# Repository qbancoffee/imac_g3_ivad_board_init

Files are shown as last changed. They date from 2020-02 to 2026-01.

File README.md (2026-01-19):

# Add custom boards to an iMac G3 DV(slot loader) in order to use it as a monitor without having to destroy it.

See the wiki for an explantion of how this was done.<BR>

<H2>Wiki explaining how this was done.</H2>
 
- [Wiki explaining how this was done.](https://github.com/qbancoffee/imac_g3_ivad_board_init/wiki)

If you have a dead logic board but a functioning CRT then these boards can let you use your
iMac G3 DV as a VGA monitor so that you can use a modern desktop with it. You can even hand wire the 
whole thing without the need for the boards if you so wish.

Even if you have a perfectly functional iMac G3 DV you can remove your logic board and use these boards
to convert your iMac G3 DV into a VGA monitor without harming your iMac G3 and when you want your iMac back, you can remove the custom boards and plug your original logic board back in and still use your iMac G3 as an original apple product.
These boards are designed to plug right in without having to modify the case and attached things.

However....

# --->DO THIS AT YOUR OWN RISK<--- as things may break as you dissasemble your iMac and you can get shocked.

Although low risk, things can always go wrong, so be careful.

- The inner bezel is extremely fragile and routintely breaks.
- The CRT can hold a charge and shock you even if the iMac is not plugged in.
- Static discharge from your hands can destroy electronics so "GROUND THYSELF"

 I've documented much of the iMac G3 slot loader chasis connector pinouts on this repo and used 
 it as a guide to make breakout circuit boards than can plug right into the chassis connectors and provide
 standard connections so that a regular computer can use things like the CRT,speakers, power button, audio
 jacks, the down-converter board ect..
 
 It wasn't easy but luckily a lot of people have shared their findings online..
 
 There is working code here for both the arduino and raspberry pi to initialize the IVAD board so that you can use it as a monitor.
 
The current initialization sketch waits for button presses on an arduino pin to send the initialization sequence
to the IVAD board but you can just uncomment "initIvadBoard();" in "setup()" to send it as soon as it's powered.

</br>

Also, you might have to modify values in the init sequence to get the brightness, contrast and screen geometry
just right for your setup. below is an example from the init sketch.

```
  writeToIvad( 0x46, 0x04, 0x80);//red x-30
  writeToIvad( 0x46, 0x05, 0xB0);// green x
  writeToIvad( 0x46, 0x06, 0x78); //blue x-38

  writeToIvad( 0x46, 0x07, 0xB1); //horizontal position
  writeToIvad( 0x46, 0x08, 0xF8); //vertical size
  ```

<!-- toc -->
- [Success stories](#Success-Stories)
- [Goals](#Goals)
- [Chassis Connectors and Pinouts](#Chassis-Connectors-and-Pinouts)
    * [Removing the logic board](#Removing-the-logic-board)
- [Wiring VGA cable](#Wiring-VGA-cable)
    * [Making the cable](#Making-the-cable)
- [Preparing the Raspberry Pi](#Preparing-the-Raspberry-Pi)
    * [What to install](#What-to-install)
    * [Configure Resolution and Refresh Rate](#Configure-Resolution-and-Refresh-Rate)
-   * [Wiring The Raspberry Pi and testing the connection](#Wiring-The-Raspberry-Pi-and-testing-the-connection)
- [Wiring Arduino Uno](#Wiring-Arduino-Uno)
- [Wiring Arduino Nano](#Wiring-Arduino-Nano)
    * [Loading and Running the initialization sketch](#Loading-and-Running-the-initialization-sketch)
- [Wiring Arduino Uno to transmit EDID](#Wiring-Arduino-Uno-to-transmit-EDID)
- [Wiring Arduino Nano to transmit EDID](#Wiring-Arduino-Nano-to-transmit-EDID)
- [Powering the down converter board PAV](#Powering-the-down-converter-board-PAV)
- [Powering the CRT on and off](#Powering-the-CRT-on-and-off)
- [See Also](#See-Also)
   * [See the boards](#Boards)
   * [Getting adapter boards](#Ordering-Boards)
   * [Acknowledgements](#Acknowledgements)
   * [Videos](#Videos)
## Success Stories
- [Apple IIe using the iMac G3 as a monitor](https://www.reddit.com/r/VintageApple/comments/fox7b8/my_half_retro_battle_station/)
- [Apple IIe using the iMac G3 as a monitor 2 ](https://old.reddit.com/r/VintageApple/comments/fmoi5d/slot_loading_imac_g3_vga_input_hack/)
- [oshimai running windows on a pc104 computer](https://vimeo.com/415301897)
- [oshimais' repo with links to videos](https://github.com/shuuryou/imacg3)
- [A Nintendo Switch connected to an iMac G3](https://www.reddit.com/r/crtgaming/comments/k3hf02/imac_g3_crt_connected_to_switch/)
- [Check out the iMacSTer repo by wikerwaka it's impressive!](https://github.com/wickerwaka/iMacSTer)
- [Wikerwaka testing the iMacSTer](https://youtu.be/8O5fEVcCo0Q)
- [Wikerwaka assembling the iMacSTer](https://youtu.be/OmDPnWWWzPM)
- [Matt Gray upgrades an iMac G3 it and now runs on Apple silicon!](https://youtu.be/WoYBuP4Bxiw?si=AiPPqQjk6-E3-r2k)

## Goals

The main goal is to convert the iMac G3 into a VGA monitor whithout sacrificing the original CRT and
using as much of the iMac as possible. The difficult part is tricking the IVAD board into thinking it is 
still connected to a G3 logic board. the idea is to capture the init sequence and reimplement it using
a microcontoller like an arduino.

Once achieved, one can connect a standard computer to it as if it were a regular monitor with speakers.
One can even include a motherboard on the inside of the G3 basically converting it into a modern computer.

Here are the goals

- [x] Capture IVAD board initialization sequence from the Imac logic board to the IVAD board and implement with mcu & rpi.
- [x] Document how to control brightness, contrast, screen goemetry ect via the i2c lines.
- [x] Document as much of the pinouts as possible on the the chassis connectors .
- [x] [Design circuit boards that will plug into the connectors and allow one to use the on/off button,
speakers, power LED, mic ect..](#Boards)
- [x] Design the circuit boards with through hole components so that anyone can build these with just a soldering iron and
solder.
- [x] Use the original down-converter board(kind of like a power supply) to power things like
an amplifier and a slot loading DVD drive.

## Chassis Connectors and Pinouts
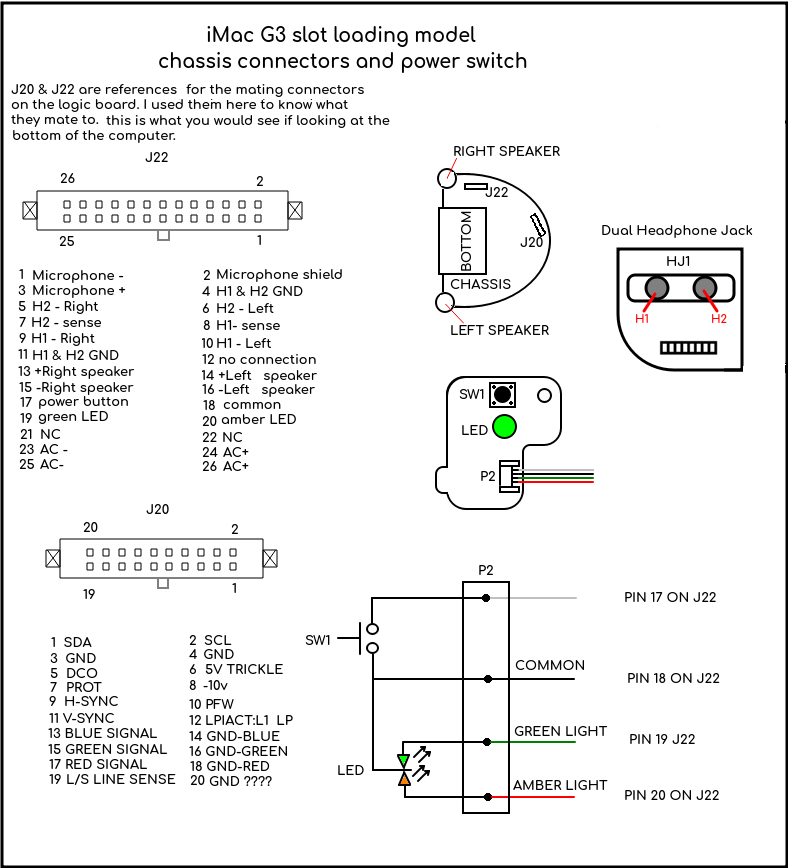
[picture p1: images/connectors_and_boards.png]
ChassisConnectors Chassis connectors


### Removing the logic board
The connector drawings in the above [diagram](#Chassis-Connectors-and-Pinouts) represent the cables
coming from the CRT analog board that plug into the logic board. To expose these, the logic board must
be removed.

## Wiring VGA cable
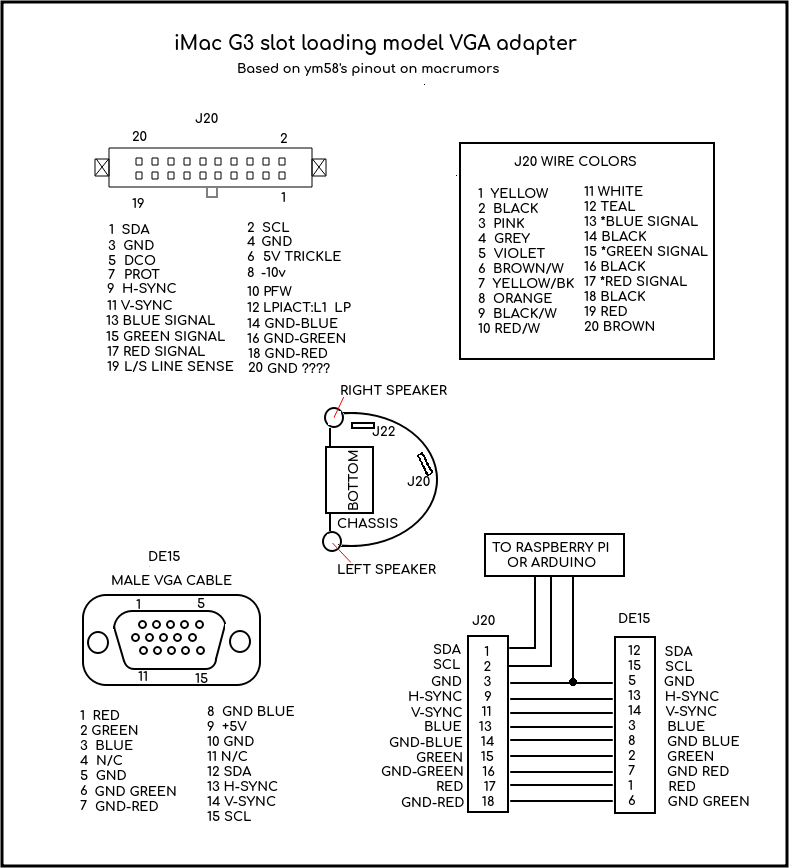
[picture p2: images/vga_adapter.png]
VGACable VGA Cable


### Making the cable
This is perhaps the most time consuming part of the whole process because not all VGA cables are made the same so the colors for the cable I used may not be the colors used in your cable. Here are the steps I took.<br>

- Find a VGA cable to cut.
- Cut the cable so that you have at least one of the ferrite chokes left on the cable.
- Cut away the cable jacket such that the wires are at a comfortable handling length. 3 to 4 inches
- Strip each wire and ring them out to find what color corresponds to each pin on the DE15 connector.
- Use the [diagram](#Wiring-VGA-cable) above and map your cable to J20 using the DE15 pin numbers as the key.
- Option 1 ,use a 20 pin header and solder the DE15 wires to it then plug it into J20.
- Option 2, cut the required wires from J20 and splice them with VGA cable. Solder and use shrink tubing if you can but twisting them and electrical tape works as well. Make sure to leave enough wire on J20 in the event you need to reattach the wires.

## Preparing the Raspberry Pi
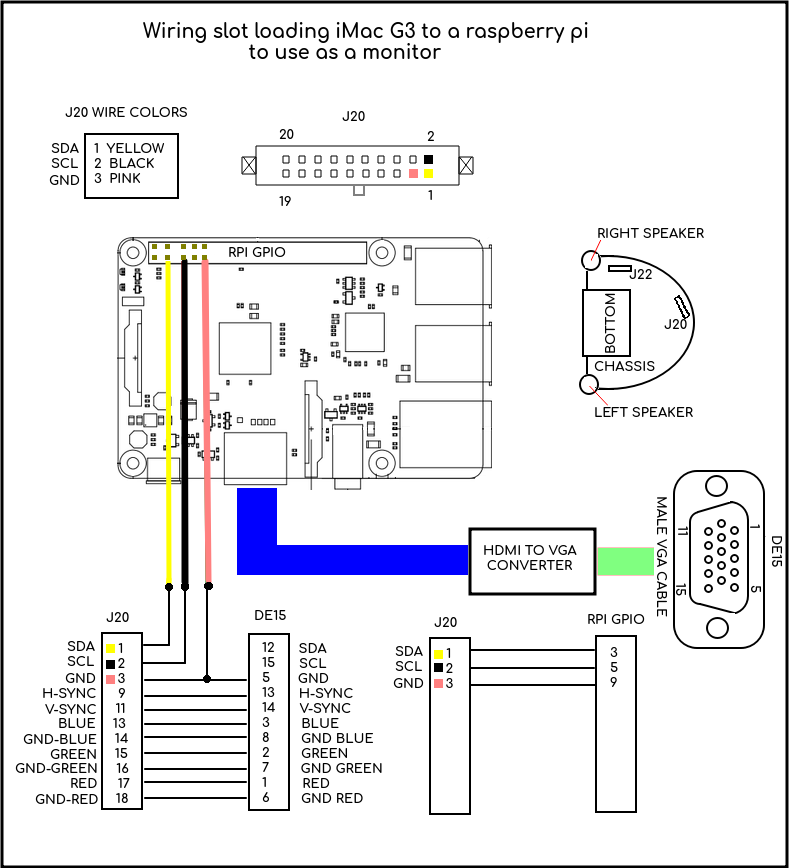
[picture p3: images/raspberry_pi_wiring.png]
WiringRPI Wiring RPI


### What to install
- Install the latest raspian image using a regular monitor.
- Connect to your network and get the ip address for the pi by opening a terminal and issuing the following.
```bash
ifconfig
```
If you connected using wifi then the ip address is under wlan0: , inet.<br>
If you connected using a cable the the ip adress is under eth0: inet<br>
- Enable ssh , you'll need this to login from another computer when you don't have a display.
- Enable I2C.
- Install i2c-tools & git.
- ssh to the pi from a terminal if your on a Mac or linux. If you're on Windows use putty to ssh to the pi I'm assuming
the username is "pi" but replace this with the the username you've created for the pi.

```bash
sudo apt-get update && sudo apt-get -y install i2c-tools git
```
- Install smbus and RPI.GPIO for python using pip for the python version you have.
```bash
sudo pip install smbus RPI.GPIO
```
- Clone the iMac IVAD init repo
```bash
git clone https://github.com/qbancoffee/imac_g3_ivad_board_init.git
cd imac_g3_ivad_board_init
```
- Copy init_ivad.py to /usr/local/bin & and make it executeable
```bash
sudo cp init_ivad.py /usr/local/bin
sudo chmod +x /usr/local/bin/init_ivad.py
```
- Edit rc.local and add the script. Make sure it's added to the line before "exit 0 " or it will not run.
It also needs to be made executable since by default it doesn't do anything.
```bash
sudo nano /etc/rc.local
```

- It should look something like this
```
#!/bin/sh -e
#
# rc.local
#
# This script is executed at the end of each multiuser runlevel.
# Make sure that the script will "exit 0" on success or any other
# value on error.
#
# In order to enable or disable this script just change the execution
# bits.
#
# By default this script does nothing.

# Print the IP address
_IP=$(hostname -I) || true
if [ "$_IP" ]; then
  printf "My IP address is %s\n" "$_IP"
fi

/usr/local/bin/init_ivad.py

exit 0

```

- Ctrl-x to save and exit

- Make rc.local executable
```bash
sudo chmod +x /etc/rc.local
```

### Configure Resolution and Refresh Rate
- Edit config.txt
```bash
sudo nano /boot/config.txt
```
- The newer Raspberry Pi OS uses the VC4 V3D driver that causes the video to go blank. Comment the line that enables it and add the Fake VC4 V3D driver.
```
# Enable DRM VC4 V3D driver
#dtoverlay=vc4-kms-v3d
dtoverlay=vc4-fkms-v3d

```
Newer versions of the Raspberry Pi OS will ignore video modes specified in /boot/config.txt if the EDID sent from the monitor is corrupt or missing. Since we are not sending EDID information to the raspberry pi from the iMac we need to tell the OS to ignore the EDID and set the correct video mode.
- Add the following to the bottom of the file and save.
```
#iMac G3 settings
hdmi_ignore_edid=0xa5000080
hdmi_group=2
hdmi_mode=18
```
Here is a video where I perform the above steps.
- [Modding an iMac G3 DV using only a Raspberry Pi](https://youtu.be/xSiqchucFE4)
### Wiring The Raspberry Pi and testing the connection

In all cases, the IVAD board needs to be initialized when the power analog board is
turned on for the first time. To do this, the initialization sequence must be sent using the
I2C lines(SDA & SCL) on the Raspberry Pi's GPIO header. Connect the I2C lines according to the diagram
above and connect the VGA cable to the HDMI port using a HDMI to VGA converter.

- Use i2cdetect to probe the IVAD board. Make sure the iMac is plugged in, it does not have to be turned on for this.

```bash
i2cdetect -y 1
```
- Confirm it found address's 46 and 53, if no luck, check the wiring and make sure I2C is enabled. The output should look something like the following.
```    
     0  1  2  3  4  5  6  7  8  9  a  b  c  d  e  f
00:          -- -- -- -- -- -- -- -- -- -- -- -- -- 
10: -- -- -- -- -- -- -- -- -- -- -- -- -- -- -- -- 
20: -- -- -- -- -- -- -- -- -- -- -- -- -- -- -- -- 
30: -- -- -- -- -- -- -- -- -- -- -- -- -- -- -- -- 
40: -- -- -- -- -- -- 46 -- -- -- -- -- -- -- -- -- 
50: -- -- -- 53 -- -- -- -- -- -- -- -- -- -- -- -- 
60: -- -- -- -- -- -- -- -- -- -- -- -- -- -- -- -- 
70: -- -- -- -- -- -- -- --
```
- [Turn on the monitor](#Powering-the-CRT-on-and-off) and run the initialization script.The iMac should make
a nice old school "CRT IS ON"  sound. 
```bash
/usr/local/bin/init_ivad.py
```
If there are errors, make sure the iMac is plugged in and check the wiring.<br>
If there are no errors and there is nothing on the screen, move the mouse or press a key.
The raspberry pi might have turned off the display due to inactivity.

- With the IVAD initialized, Reboot the Raspberry Pi.

## Wiring Arduino Uno
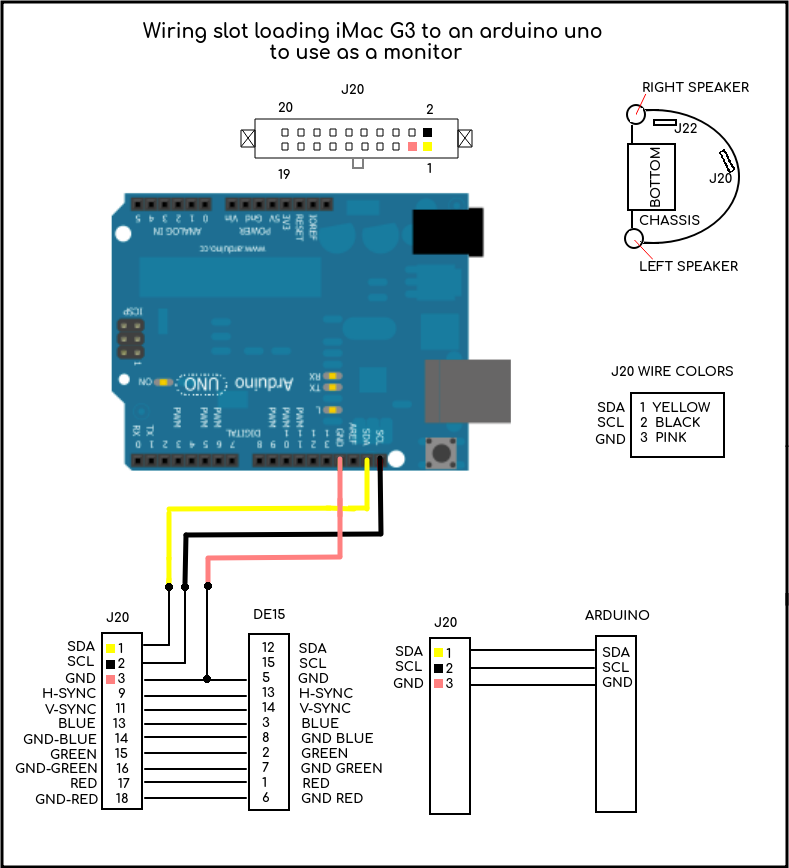
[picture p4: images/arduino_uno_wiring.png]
WiringArduinoUno Wiring Arduino Uno


## Wiring Arduino Nano
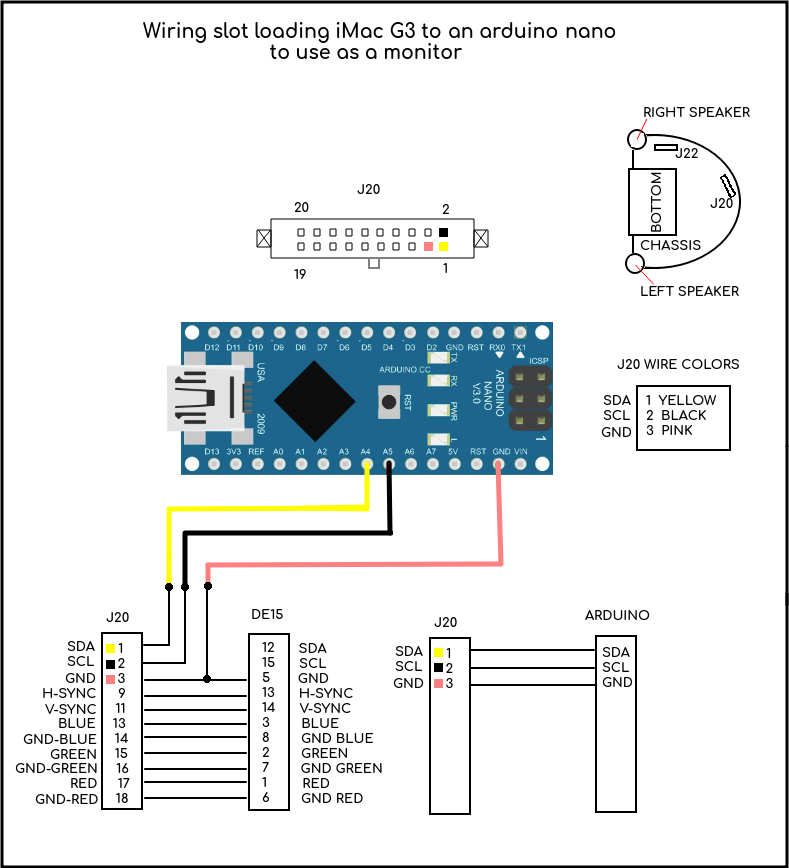
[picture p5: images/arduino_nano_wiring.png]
WiringArduinoNano Wiring Arduino Nano


### Loading and Running the initialization sketch
write here

## Wiring Arduino Uno to transmit EDID
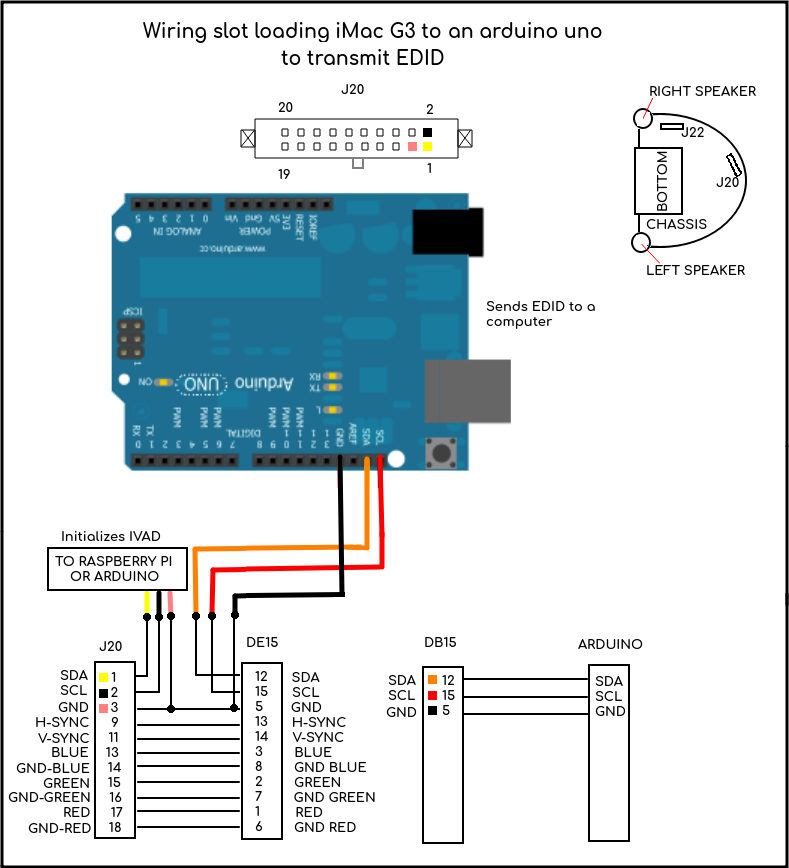
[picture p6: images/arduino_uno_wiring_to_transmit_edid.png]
WiringArduinoUnoToXmitEdid Wiring Arduino Uno to transmit EDID


## Wiring Arduino Nano to transmit EDID
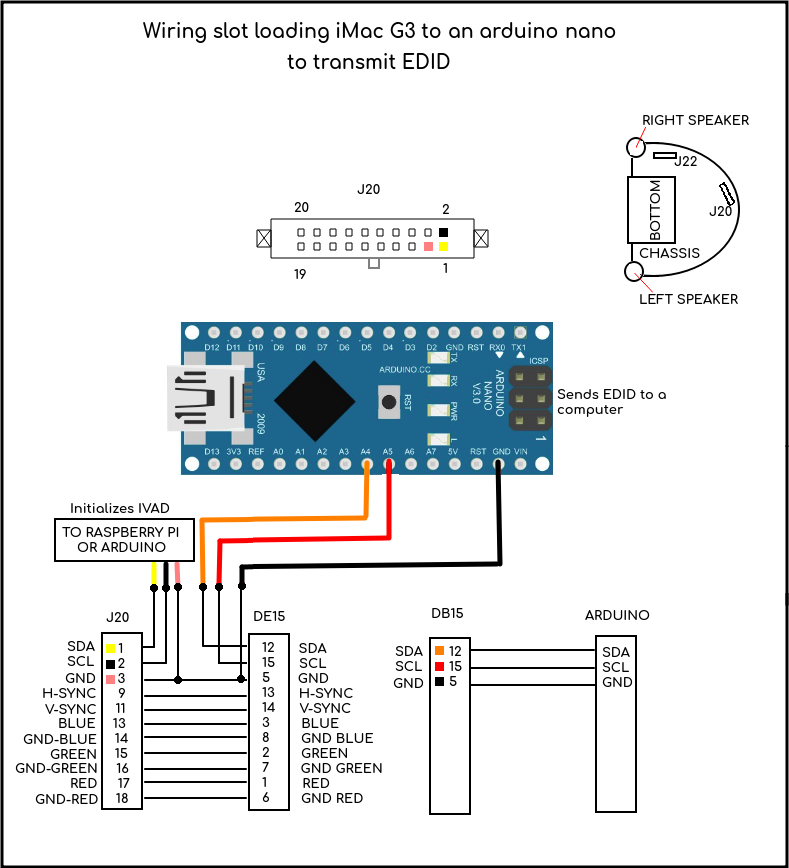
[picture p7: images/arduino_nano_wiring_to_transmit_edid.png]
WiringArduinoNanotoXmitEdid Wiring Arduino Nano to transmit EDID


## Powering the down converter board PAV
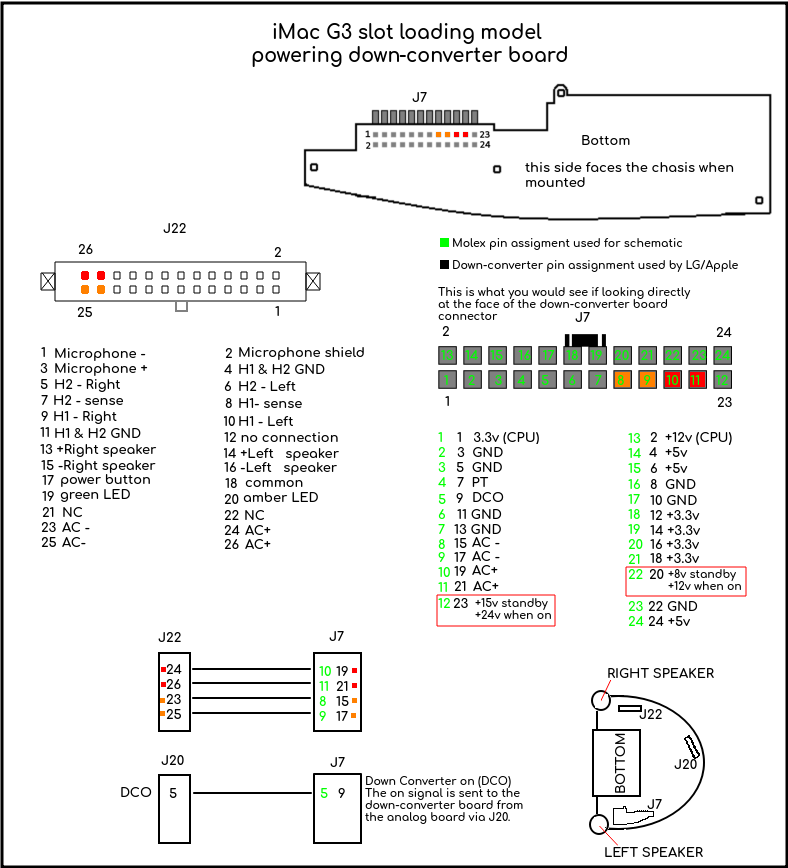
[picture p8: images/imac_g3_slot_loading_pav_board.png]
WiringPAV Powering the PAV board


The CRT analog board provides 24v AC to the PAV or down converter board through the logic board via the J22 
connector. you can directly connect the PAV board and the analog board through the J22 connector and
the PAV board will produce the typical mother board volytages. +12v, +5v +3.3v ect...

## Powering the CRT on and off
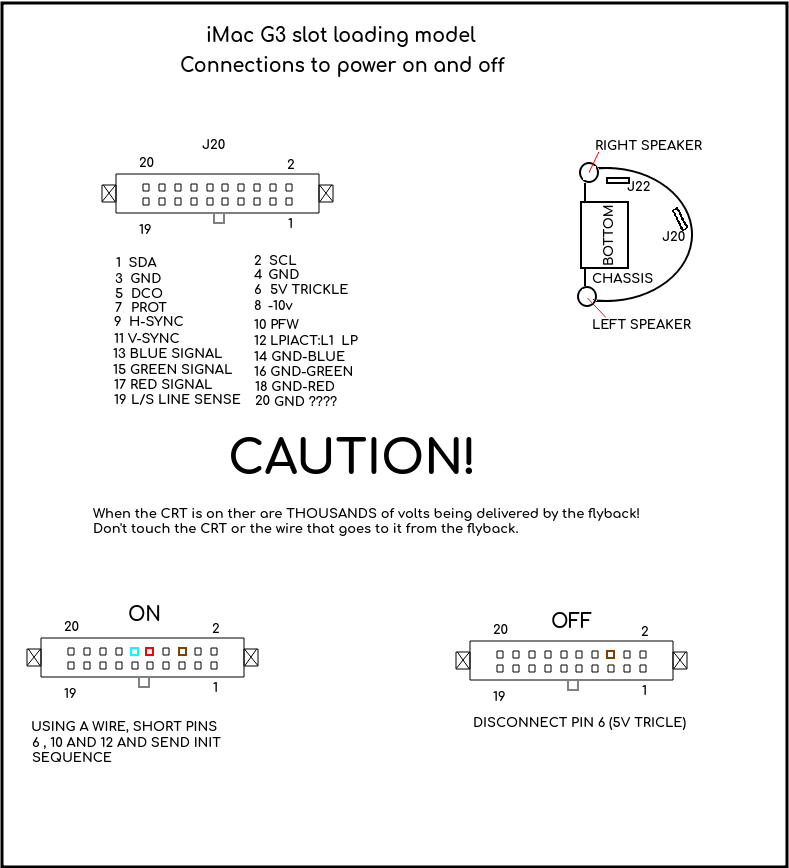
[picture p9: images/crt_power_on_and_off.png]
CRTOnAndOff CRT On and Off


## See Also
### Boards
# J20 Board
What it does.
- detects button presses
- sends the init sequence to the IVAD boar
- sends the "turn-on" signal to the down-converter board
- has a control line "PROT" that when 5 volts are applied turns everythin off. A shut-off signal can be sent here.
- powers the green LED
- sends EDID information via VGA cable so that a connected computer knows how to configure the monitor for use.
</br>

This board works but as of March 23 2020 it needs a slight modification to make it more robust.
# Rendition
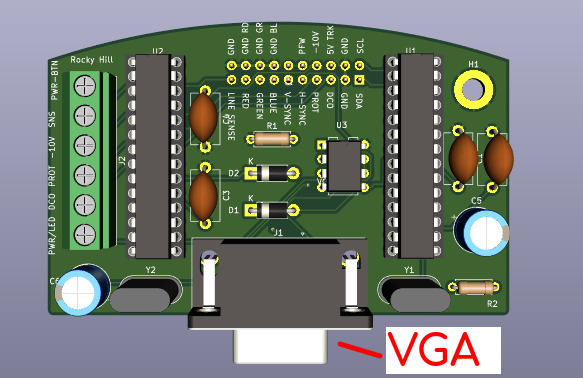
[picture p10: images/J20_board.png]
J20 J20 VGA adapter board

# Board installed
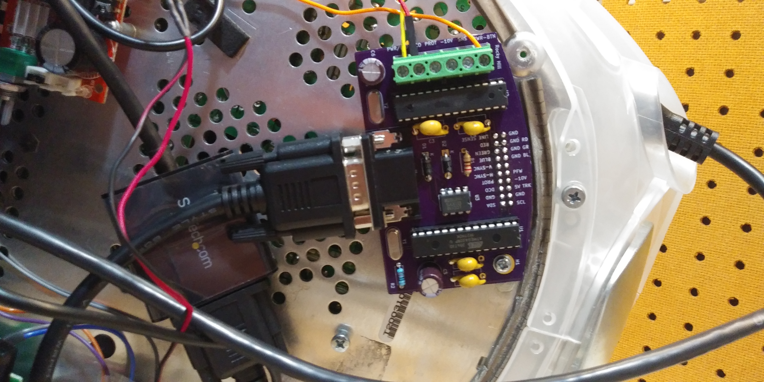
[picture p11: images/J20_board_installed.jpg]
J20Installed J20 VGA adapter board installed

</br>

# Rendiiton of Rev 2 of the J20 board.
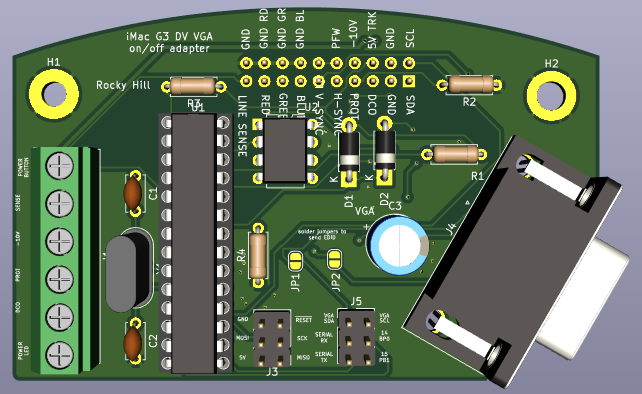
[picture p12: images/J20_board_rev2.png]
J20REV2 J20 VGA adapter board Rev 2

</br>

# J22 Board
What it does.
- provides access to the microphone and the speakers
- provides access to the power button
- provides access to the green LED
- provides access to the amber LED
- provides access to the headphone jacks 
- routes 24 VAC from the analog(CRT) board to the the down converter break out board.
</br>

This board has been tested and mostly worked. I found that the mic was miswired
but I've since fixed that.
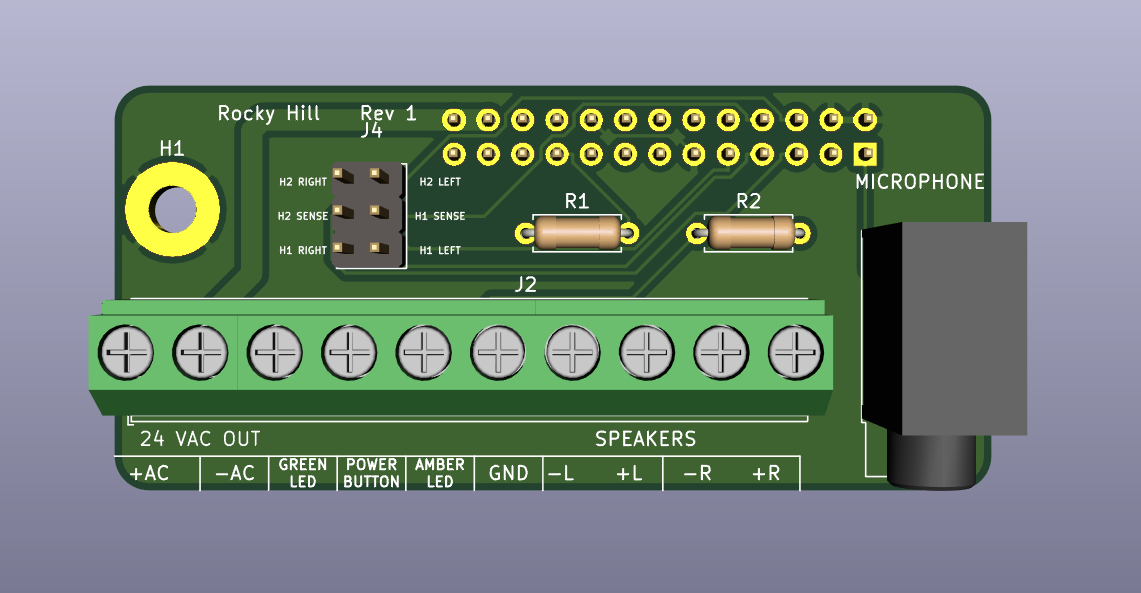
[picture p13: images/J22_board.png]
J22 J22 speaker/mic/led/power button breakout board

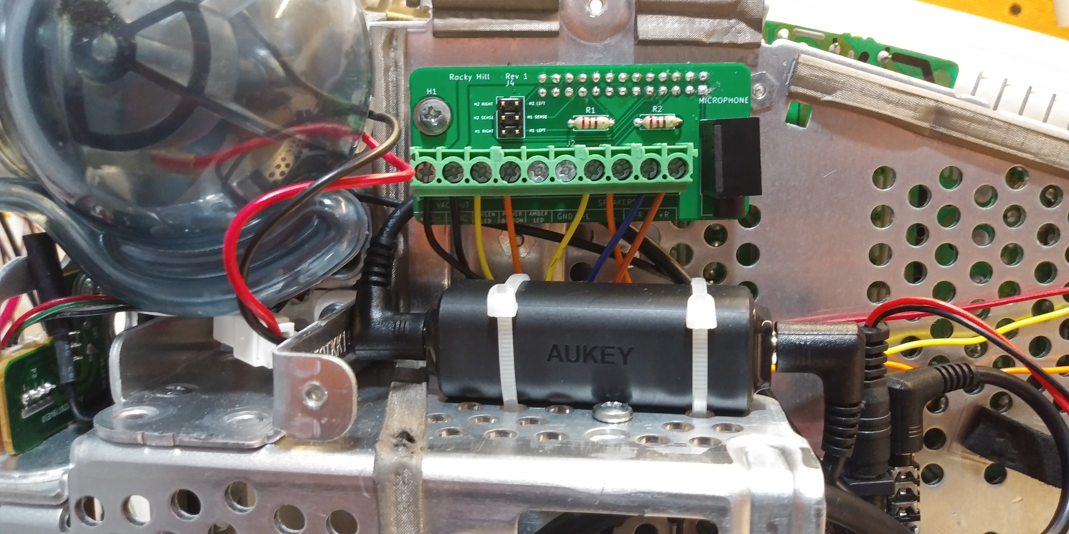
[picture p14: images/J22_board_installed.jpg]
J22Installed J22 speaker/mic/led/power button breakout board installed

</br>
# Down-converter breakout board
What it does
- provides a 24 VAC input from the J22 board into the down-converter board
- provides a "turn-on" input for the J20 board, this is DCO, which stands for Down Converter On
- provides 3.3 VDC out from the down-converter board that turns on and off with the CRT.
- provides   5 VDC out from the down-converter board that turns on and off with the CRT.
- provides  12 VDC out from the down-converter board that turns on and off with the CRT.
- provides a constant  8 VDC standby voltage when all is off and 12 VDC when all is on.
- provided a constant 15 VDC standby voltage when all is off and 24 VDC when all is on.
</br>
The down-conveter uses the 24 VAC coming from J22 in order to power the original logic board and drives. Some people have called this the iMac G3 power supply. This is what it looks like.

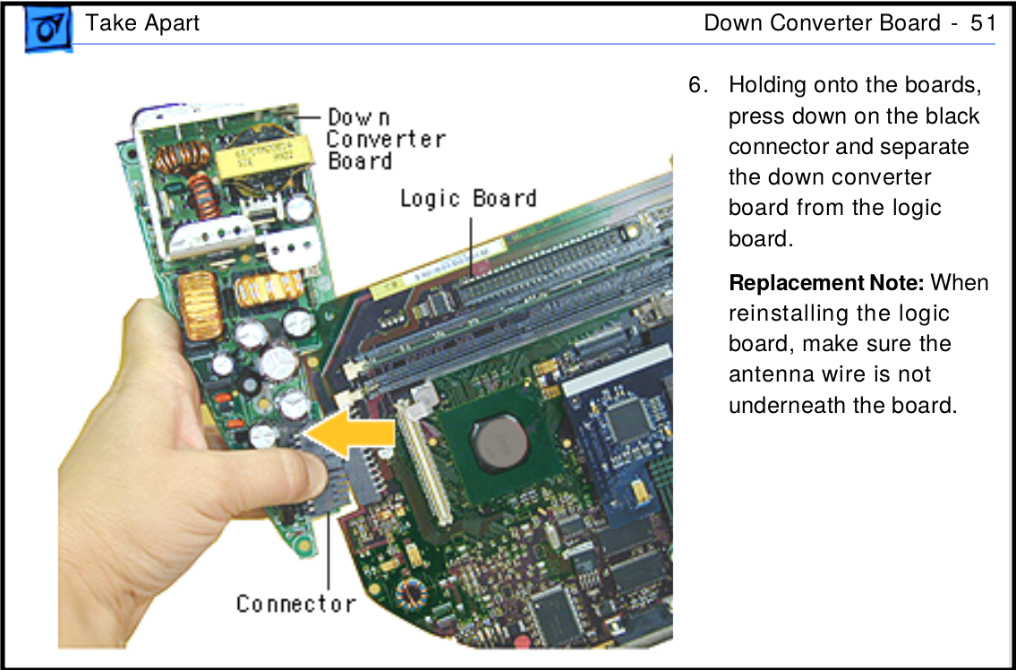
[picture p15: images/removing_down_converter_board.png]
DCB Removing down-converter board

</br>
# Rendition
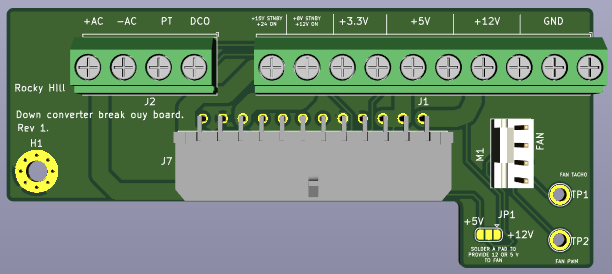
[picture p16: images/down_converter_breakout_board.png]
DCB1 Breakout board for the down-converter board so one can power things.

</br>
# Actual Board
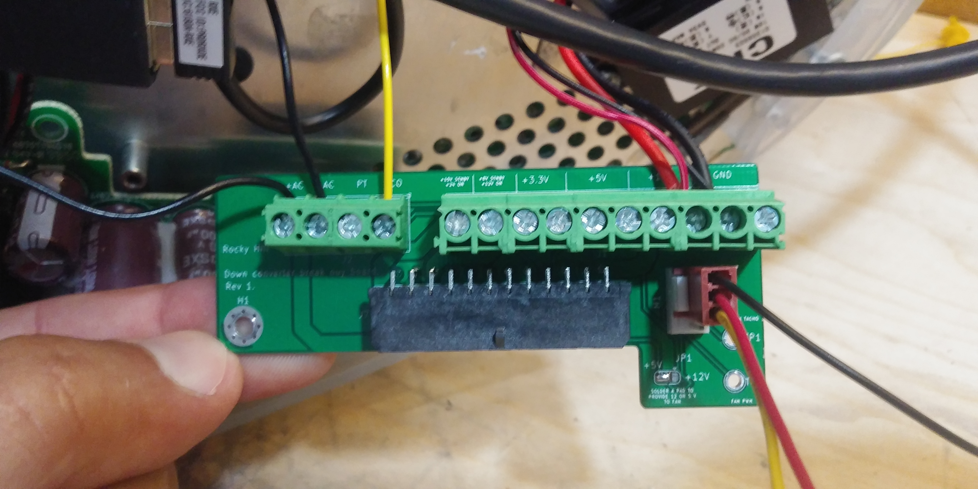
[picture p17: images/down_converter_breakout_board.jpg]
DCB2 Breakout board for the down-converter board so one can power things.

</br>
# Board installed
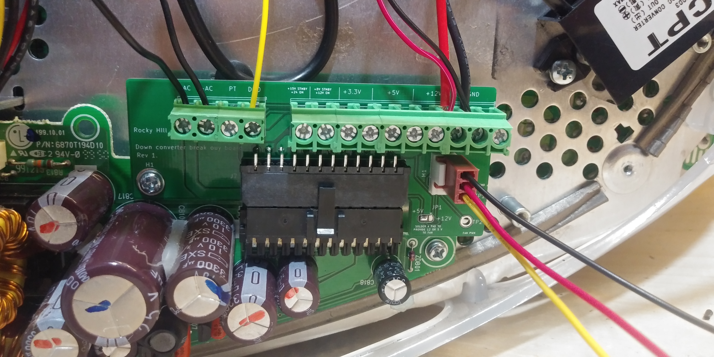
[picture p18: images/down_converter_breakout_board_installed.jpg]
DCB3 Breakout board for the down-converter board so one can power things.


</br>

### Ordering Boards
All PCB manufacturers should accept gerber files to manufacture boards so I've decided
to design these in KiCAD which is suite of open source EDA programs to create schematics and
design PCBs. There are no limitations to the size of the board and you don't have to order from
a specific vendor.

Recently I've been using https://jlcpcb.com/ and the turn arounds are fast for the price.
In the "schematics_and_pcbs" folder are the three kicad projects for each board, each in its own folder.
I've included the gerber files and zipped them up for convenience, they are in the gerber directory
for each project. To order you can just upload the zip file to https://jlcpcb.com/ or whatever company you choose
and you should get them in the mail. There is a bill of materials included in each project folder. It's a csv file
that includes the reference number, the part number and vendor so you can order the componets to build the boards.
I like to buy from digikey but obviously you can find a vendor that fits your needs.

### Acknowledgements

- [patriciooholegu for inspiring me to do this with an eMac](https://forums.macrumors.com/threads/i-have-decided-to-hack-emacs-crt-to-work-with-any-standard-motherboard.1754089/post-19353472)
- [ym58 for providing the video connector wiring.](https://www.tonymacx86.com/threads/imac-g3-slot-mod-video-connector.125515/)
- [Eric Bylenga for providing the pinout for the PAV board.](http://bylenga.ddns.net/index.php?page=vcr.php)
- [sparpet for capturing and sharing the IVAD initialization code](https://forums.macrumors.com/threads/imac-g3-mod-video-connector.1712095/post-25819428)
- [jamie-g for providing a way to adjust monitor settings via i2c](https://forums.macrumors.com/threads/imac-g3-mod-video-connector.1712095/post-25679538)
- [iMac speaker replacement by TEch Chrunch](https://youtu.be/yc8NGDw5aSQ)
- [DrJekyll_XYZ for providing xrandr output that lead to creating an EDID](https://forums.macrumors.com/threads/imac-g3-mod-video-connector.1712095/post-28272422)
- [DrJekyll_XYZ for suggesting the PAM8403 chip for audio](https://forums.macrumors.com/threads/imac-g3-mod-video-connector.1712095/post-28249216)
- [anotherelise for providing another init sequence](https://forums.macrumors.com/threads/imac-g3-mod-video-connector.1712095/post-28346679)
- [anotherelise for providing IVAD CRT property adjustment capture](https://forums.macrumors.com/threads/imac-g3-mod-video-connector.1712095/post-28349738)
- [oshimai for extracting several EDID's and fiding one that works flawlessly](https://forums.macrumors.com/threads/imac-g3-mod-video-connector.1712095/post-28359571)
- [oshimai for coming up with the idea of monitoring VSYNC to use as a signal to shut off the CRT](https://forums.macrumors.com/threads/imac-g3-mod-video-connector.1712095/post-28345426)

### Videos
- [Booting an non-modded iMac G3 to confirm the CRT turns on](https://youtu.be/meIzAyQd0t0)
- [Initializing IVAD board with an Arduino Uno](https://youtu.be/JLaHMjQ7idI)
- [Using iMac G3 as a second monitor with custom modeline](https://youtu.be/iSCjOOsf-QQ)
- [Tweaking the modeline to make the iMac G3 fullscreen](https://youtu.be/1DeY3o7P60g)
- [Sending the EDID via the VGA cable to a connected computer](https://youtu.be/KzHUogEQob4)
- [Using CRT without the logic board](https://youtu.be/MbTqhlqsKoY)
- [Running DOSBOX](https://youtu.be/PG7bluXxrPA)
- [Initializing the CRT using only a Raspberry Pi](https://youtu.be/isjo-4vQxwM)
- [Powering the iMac G3 on and off using an arduino and two transistors](https://youtu.be/-TeNbAcnvbk)
- [Powering the Down Convetrer Board without the logic board](https://youtu.be/xmISR5iBjTU)
- [Using CRT on second iMac without logic board](https://youtu.be/UcsI3FVfpCM)
- [Powering an arduino nano with only the triclke voltage provided by the analog board](https://youtu.be/KuT7AKvZXhk)
- [iMac G3 speaker repair](https://youtu.be/jgs-gkoiUrA)
- [Testing replacement speakers with smooth criminal](https://youtu.be/Vm1vN6xlomQ)
- [Testing an SBC inside the iMac G3 ](https://youtu.be/ZOYHHg9NhZA)
- [Powering a computer using the iMac's down converter board](https://youtu.be/1DuaIlEZ5WU)
- [Using a PAM8403 board to drive the speakers on the iMac G3](https://youtu.be/jEA85s0Cqyg)
- [Testing Retropie with iMac G3 monitor](https://youtu.be/S1fnj0tsFQA)
- [Testing J20 board for the first time](https://youtu.be/_IMhMkrIE4M)
- [Testing the J22 board with a raspberry pi](https://youtu.be/HR-qM3-7SYA)
- [Testing audio via the J22 breakout board 1](https://youtu.be/MyON9M_RYCk)
- [Testing audio via the J22 breakout board 2](https://youtu.be/EDeFRHsqa5c)
- [Testing the down converter breakout board for the first time.](https://youtu.be/BQKrsIXOSxU)
- [Mirroring an iMac G3 DV with this iMac G3 monitor hack](https://youtu.be/4jHPZWJs-aY)
- [All three boards installed and working.](https://youtu.be/dqxeiFkvuYg)
- [Rapberry Pi + Arduino powered iMac G3 hybrid running RetroPie](https://youtu.be/CLCZFmmEnno)
- [Adjusting iMac G3 picture settings via a serial terminal](https://youtu.be/9LLsHE3xdBA)
- [Adjusting iMac G3 picture settings with a java based GUI](https://youtu.be/zrzcvThxDeY)
- [Monitoring VSYNC to shut CRT off](https://youtu.be/fBMyjlEAZAw)
- [Cloning compiling and running oshimai's gui](https://youtu.be/DqM9bZfvwgM)
- [Stable arduino sketch that can communicate with oshimais GUI](https://youtu.be/inmUAiIA7sg)
- [Oshimais GUI running on a raspberry pi3 under mono](https://youtu.be/g9aLTrW5eaU)
- [Making a desktop recording the iMac G3 monitor with a raspberry pi, running oshimais gui](https://youtu.be/JA01o5xfwxg)
- [Assembling the J20 adapter board](https://youtu.be/qILuajxscnE)
- [Assembling the J22 adapter board](https://youtu.be/JCPRYKbwKyk)
- [Using a Gert VGA 666 adapter + Raspberry pi 3 with an Imac G3 monitor](https://youtu.be/5H0nzaTycOg)
- [Playing a round of among us using the iMac G3 as a monitor](https://youtu.be/MomKAUGT8i8)
- [Playing minecraft using the iMac G3 as a monitor](https://youtu.be/VxJVShNo72g)
- [Converting an iMac G3 DV into a monitor start to finish](https://youtu.be/guVSI1aqcJg)
- [Playing Duck Hunt and Super Mario Bros with my NES on the iMac G3](https://youtu.be/wCEGIwrCOMQ)
- [Playing "The Legend of Zelda" with my NES on the iMac G3](https://youtu.be/OpjjOnSjGQU)
- [Using my CoCo 2 on the iMac G3](https://youtu.be/9cu0CFqIWnc)
- [Modding an iMac G3 DV using only a Raspberry Pi](https://youtu.be/xSiqchucFE4)

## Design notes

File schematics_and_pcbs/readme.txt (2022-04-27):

These are the KiCAD project files for this project.

===Main boards===

-imac_g3_333mhz_slot_loading_J20_adapter_board
	This board is the "brains" of the operation, it sends the init sequence
	to the IVAD board and also sends EDID information to any device that
	requests it when conencted to the VGA port.
 
-imac_g3_down_converter_board_adapter
	This board takes 24VAC from the analog board via the the J22 board and
	converts it to standard computer power supply voltages. +12VDC, +5VDC
	and +3.3VDC. This board also has a footprint to include a connector
	to connect a CPU fan.
	
-imac_g3_slot_loading_J22_adapter_board
	This board is essentially a breakout board that allows one to use the 
	built in speakers, power switch, leds and 24VAC.

-surfacemount_version	
	This will be a surface mount version of the original main boards.
	It is currently under development. The idea is to have boards
	that can be assembled by an assembly outfit to bring down the cost.
	
===User contributed boards==

-RPiG3iMac	
	Additional KiCAD projects for a Raspberry Pi Hat and a breakout board
	for the J20 board. These boards were contributed by Rudy https://reng.ca
	, look inside the directory for more details.

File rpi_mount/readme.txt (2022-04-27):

These three parts comprise a mount for a raspberry pi 4 inside of the iMac G3.
These parts were created and graciously given to this project by 
Rudy https://reng.ca so that others can enjoy it.

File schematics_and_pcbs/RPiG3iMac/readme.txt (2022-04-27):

These boards were created and graciously contributed by Rudy https://reng.ca for
this project for others to use.

RPiG3iMac       Contains the KiCAD project files for a Raspberry Pi HAT
                with power and activity LEDs. The HAT also converts the
                incoming TTL RS232 signal to CMOS levels for use by the
                built in serial port.
            
RPiG3iMacJ20    Contains the KiCAD project files for a breakout board
                for the J3 and J5 headers on the J20 board. Once mounted
                one can connect regular wires via a terminal strip to
                interface with the two headers

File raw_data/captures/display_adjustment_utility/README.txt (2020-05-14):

This capture was made by running the Apple Display  adjustment utility
under System 9. The IVAD i2c were lines externally monitored with an
ubuntu 16.04 computer using a Saleae Logic analyzer.

Each Property was recorded by sliding the bar from min to max.
The captures have the IVAD address 0x46 and the register offset for
each property along with the value sent for that property.

Each propertry is in a csv file named according to the name in the
program.

For example when I manipulated the "width" property and captured it,
I called that file "width.csv"

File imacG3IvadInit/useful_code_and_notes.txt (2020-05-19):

  /**
       writeToIvad( 0x46,0x13,0x00);
      writeToIvad(0x46,0x13,0x00);
      readFromIvad(0x46,1);
      writeToIvad(0x46,0x09,0x00);
      writeToIvad(0x53,0x33);
      readFromIvad(0x53,1);
      writeToIvad(0x46,0x13,0x0b);
      writeToIvad(0x46,0x00,0x00);
      writeToIvad(0x46,0x08,0xe4);
      writeToIvad(0x46,0x12,0xc9);
      writeToIvad(0x53,0x00);
      readFromIvad(0x53,10);
      writeToIvad(0x53,0x0a);
      readFromIvad(0x53,10);
      writeToIvad(0x53,0x14);
      readFromIvad(0x53,10);
      writeToIvad(0x53,0x1e);
      readFromIvad(0x53,10);
      writeToIvad(0x53,0x28);
      readFromIvad(0x53,10);
      writeToIvad(0x53,0x32);
      readFromIvad(0x53,10);
      writeToIvad(0x53,0x3c);
      readFromIvad(0x53,10);
      writeToIvad(0x53,0x46);
      readFromIvad(0x53,10);
      writeToIvad(0x53,0x50);
      readFromIvad(0x53,10);
      writeToIvad(0x53,0x5a);
      readFromIvad(0x53,10);
      writeToIvad(0x46,0x01,0x82);
      writeToIvad(0x46,0x02,0x82);
      writeToIvad(0x46,0x03,0x82);
      writeToIvad(0x46,0x04,0xa0);
      writeToIvad(0x46,0x05,0xa0);
      writeToIvad(0x46,0x06,0xa0);
      writeToIvad(0x46,0x07,0xad);
      writeToIvad(0x46,0x08,0xe4);
      writeToIvad(0x46,0x09,0x3d);
      writeToIvad(0x46,0x0a,0x9e);
      writeToIvad(0x46,0x0b,0xb4);
      writeToIvad(0x46,0x0c,0xc4);
      writeToIvad(0x46,0x0d,0x27);
      writeToIvad(0x46,0x0e,0xbf);
      writeToIvad(0x46,0x0f,0xc0);
      writeToIvad(0x46,0x10,0x40);
      writeToIvad(0x46,0x11,0x0a);
      writeToIvad(0x46,0x12,0x5b);
      writeToIvad(0x46,0x00,0xff);
      writeToIvad(0x53,0x00);
      readFromIvad(0x53,10);
      writeToIvad(0x53,0x10);
      readFromIvad(0x53,10);
      writeToIvad(0x53,0x20);
      readFromIvad(0x53,10);
      writeToIvad(0x53,0x30);
      readFromIvad(0x53,10);
      writeToIvad(0x46,0x11,0x05);
      writeToIvad(0x46,0x00,0xff);
      writeToIvad(0x46,0x00,0x00);
      writeToIvad(0x46,0x07,0xb1);
      writeToIvad(0x46,0x0d,0x10);
      writeToIvad(0x46,0x0c,0xc7);
      writeToIvad(0x46,0x09,0x4a);
      writeToIvad(0x46,0x08,0xea);
      writeToIvad(0x46,0x0f,0xc0);
      writeToIvad(0x46,0x0b,0xae);
      writeToIvad(0x46,0x12,0x5b);
      writeToIvad(0x46,0x00,0xff);
      writeToIvad(0x46,0x11,0x05);
      writeToIvad(0x46,0x00,0xff);
      writeToIvad(0x46,0x10,0x40);
      writeToIvad(0x46,0x06,0xa0);
      writeToIvad(0x46,0x05,0xa0);
      writeToIvad(0x46,0x04,0xa0);
      writeToIvad(0x46,0x03,0x82);
      writeToIvad(0x46,0x02,0x82);
      writeToIvad(0x46,0x01,0x82);
      writeToIvad(0x46,0x11,0x05);
      writeToIvad(0x46,0x00,0xff);
      writeToIvad(0x46,0x11,0x05);
      writeToIvad(0x46,0x00,0xff);
      writeToIvad(0x46,0x10,0x40);
      writeToIvad(0x46,0x06,0xa0);
      writeToIvad(0x46,0x05,0xa0);
      writeToIvad(0x46,0x04,0xa0);
      writeToIvad(0x46,0x03,0x82);
      writeToIvad(0x46,0x02,0x82);
      writeToIvad(0x46,0x01,0x82);
      writeToIvad(0x46,0x11,0x05);
      writeToIvad(0x46,0x00,0xff);
  */

//this is the EDID information that is sent to the computer that requests it.
//this edid was created by Rocky Hill
//const byte edid[128] =
//{
//
//  0x00, 0xff, 0xff, 0xff, 0xff, 0xff, 0xff, 0x00, 0x06, 0x10, 0x74, 0x61,
//  0xed, 0x5f, 0x84, 0x00, 0x06, 0x1e, 0x01, 0x03, 0x6d, 0x1a, 0x14, 0x78,
//  0xea, 0x5e, 0xc0, 0xa4, 0x59, 0x4a, 0x98, 0x25, 0x20, 0x50, 0x54, 0x00,
//  0x00, 0x00, 0x61, 0x4f, 0x01, 0x01, 0x01, 0x01, 0x01, 0x01, 0x01, 0x01,
//  0x01, 0x01, 0x01, 0x01, 0x01, 0x01, 0xc3, 0x1e, 0x00, 0x30, 0x41, 0x00,
//  0x34, 0x30, 0x14, 0x60, 0xd3, 0x00, 0x0a, 0xc8, 0x10, 0x00, 0x00, 0x1e,
//  0x5f, 0x18, 0x20, 0xf0, 0x30, 0x58, 0x2c, 0x20, 0x15, 0x50, 0x93, 0x00,
//  0xd0, 0x9c, 0x00, 0x00, 0x00, 0x18, 0x7d, 0x13, 0x80, 0xc0, 0x20, 0xe0,
//  0x22, 0x10, 0x11, 0x40, 0x13, 0x00, 0xa6, 0x7d, 0x00, 0x00, 0x00, 0x18,
//  0x00, 0x00, 0x00, 0xfd, 0x00, 0x3b, 0x3d, 0x3a, 0x3d, 0x08, 0x00, 0x00,
//  0x00, 0x00, 0x00, 0x00, 0x00, 0x00, 0x00, 0x19
//};

//edid1
// extracted from an iMac and given by user oshimai
//https://forums.macrumors.com/threads/imac-g3-mod-video-connector.1712095/post-28356515

//const byte edid[128]
//{
//0x00,0xFF,0xFF,0xFF,0xFF,0xFF,0xFF,0x00,0x06,0x10,0x52,0x03,0x01,0x01,0x01,0x01,
//0x01,0x06,0x01,0x01,0x28,0x26,0x1D,0x86,0xE8,0x01,0xC9,0xA0,0x57,0x49,0x98,0x27,
//0x12,0x48,0x4C,0x3F,0xFF,0x80,0x01,0x01,0x31,0x59,0x45,0x59,0x81,0x59,0x61,0x59,
//0xA9,0x4F,0x01,0x01,0x01,0x01,0x10,0x0E,0x80,0xC0,0x20,0xE0,0x1D,0x10,0x38,0x38,
//0x13,0x00,0x7C,0x22,0x11,0x00,0x00,0x1E,0xF9,0x15,0x20,0xF8,0x30,0x58,0x1F,0x20,
//0x20,0x40,0x13,0x00,0x7C,0x22,0x11,0x00,0x00,0x1E,0x00,0x00,0x00,0xFD,0x00,0x30,
//0x78,0x1E,0x5E,0xFF,0x00,0x0A,0x20,0x20,0x20,0x20,0x20,0x20,0x00,0x00,0x00,0xFC,
//0x00,0x41,0x70,0x6C,0x56,0x69,0x73,0x69,0x6F,0x6E,0x38,0x35,0x30,0x0A,0x00,0xA4
//};

//edid2
// extracted from an iMac and given by user oshimai
//https://forums.macrumors.com/threads/imac-g3-mod-video-connector.1712095/post-28356515

//const byte edid[128]
//{
//0x00,0xFF,0xFF,0xFF,0xFF,0xFF,0xFF,0x00,0x06,0x10,0xEE,0x02,0x01,0x01,0x01,0x01,
//0x01,0x01,0x01,0x01,0x28,0x20,0x18,0x86,0xE8,0x01,0xC9,0xA0,0x57,0x49,0x98,0x27,
//0x12,0x48,0x4C,0x35,0x6B,0x80,0x01,0x01,0x01,0x01,0x01,0x01,0x01,0x01,0x01,0x01,
//0x01,0x01,0x01,0x01,0x01,0x01,0x10,0x0E,0x80,0xC0,0x20,0xE0,0x1D,0x10,0x38,0x38,
//0x13,0x00,0x7C,0x22,0x11,0x00,0x00,0x1E,0x10,0x0E,0x80,0xC0,0x20,0xE0,0x1D,0x10,
//0x38,0x38,0x13,0x00,0x7C,0x22,0x11,0x00,0x00,0x1E,0x00,0x00,0x00,0xFD,0x00,0x30,
//0x78,0x1E,0x53,0xFF,0x00,0x0A,0x20,0x20,0x20,0x20,0x20,0x20,0x00,0x00,0x00,0xFC,
//0x00,0x41,0x70,0x6C,0x56,0x69,0x73,0x69,0x6F,0x6E,0x37,0x35,0x30,0x20,0x00,0xA9
//};

//edid3
// extracted from an iMac and given by user oshimai
//https://forums.macrumors.com/threads/imac-g3-mod-video-connector.1712095/post-28356515

//const byte edid[128]
//{
//0x00,0xFF,0xFF,0xFF,0xFF,0xFF,0xFF,0x00,0x06,0x10,0x10,0x92,0x01,0x01,0x01,0x01,
//0x00,0x08,0x01,0x01,0x68,0x27,0x1D,0x86,0xE8,0x0D,0xC9,0xA0,0x57,0x47,0x98,0x27,
//0x12,0x48,0x4C,0x35,0xEF,0x80,0x31,0x59,0x45,0x59,0x61,0x59,0x81,0x80,0x81,0x99,
//0xA9,0x40,0xA9,0x4F,0xA9,0x59,0x01,0x01,0x01,0x01,0x01,0x01,0x01,0x01,0x01,0x01,
//0x01,0x01,0x01,0x01,0x01,0x01,0x01,0x03,0x01,0x01,0x01,0x01,0x01,0x01,0x01,0x01,
//0x01,0x01,0x01,0x01,0x01,0x01,0x01,0x01,0x01,0x03,0x00,0x00,0x00,0xFD,0x00,0x30,
//0x78,0x1E,0x6B,0x17,0x00,0x0A,0x20,0x20,0x20,0x20,0x20,0x20,0x00,0x00,0x00,0xFC,
//0x00,0x53,0x74,0x75,0x64,0x69,0x6F,0x44,0x73,0x70,0x6C,0x79,0x32,0x31,0x00,0x0F
//};

//edid 4
// extracted from an iMac and given by user oshimai
//https://forums.macrumors.com/threads/imac-g3-mod-video-connector.1712095/post-28358458

//const byte edid[128]
//{
//0x00,0xFF,0xFF,0xFF,0xFF,0xFF,0xFF,0x00,0x06,0x10,0x02,0x9D,0x01,0x01,0x01,0x01,
//0x00,0x08,0x01,0x01,0x68,0x20,0x18,0x8C,0xE8,0x04,0x89,0xA0,0x57,0x4A,0x9B,0x26,
//0x12,0x48,0x4C,0x31,0x2B,0x80,0x31,0x59,0x45,0x59,0x61,0x59,0xA9,0x40,0x01,0x01,
//0x01,0x01,0x01,0x01,0x01,0x01,0x60,0x16,0x40,0x40,0x31,0x70,0x2B,0x20,0x20,0x40,
//0x23,0x00,0x38,0xEA,0x10,0x00,0x00,0x18,0x48,0x3F,0x40,0x32,0x62,0xB0,0x32,0x40,
//0x40,0xC2,0x13,0x00,0x38,0xEA,0x10,0x00,0x00,0x18,0x00,0x00,0x00,0xFD,0x00,0x30,
//0xA0,0x1E,0x55,0x10,0x00,0x0A,0x20,0x20,0x20,0x20,0x20,0x20,0x00,0x00,0x00,0xFC,
//0x00,0x53,0x74,0x75,0x64,0x69,0x6F,0x44,0x73,0x70,0x6C,0x79,0x31,0x37,0x00,0xBE
//};

//edid 5
// extracted from an iMac and given by user oshimai
//https://forums.macrumors.com/threads/imac-g3-mod-video-connector.1712095/post-28358458

//const byte edid[128]
//{
//0x00,0xFF,0xFF,0xFF,0xFF,0xFF,0xFF,0x00,0x06,0x10,0x52,0x03,0x01,0x01,0x01,0x01,
//0x01,0x06,0x01,0x01,0x28,0x26,0x1D,0x28,0xE8,0x01,0xC9,0xA0,0x57,0x49,0x98,0x27,
//0x12,0x48,0x4C,0x3F,0xFF,0x80,0x01,0x01,0x31,0x59,0x45,0x59,0x81,0x59,0x61,0x59,
//0xA9,0x4F,0x01,0x01,0x01,0x01,0x10,0x0E,0x80,0xC0,0x20,0xE0,0x1D,0x10,0x38,0x38,
//0x13,0x00,0x7C,0x22,0x11,0x00,0x00,0x1E,0xF9,0x15,0x20,0xF8,0x30,0x58,0x1F,0x20,
//0x20,0x40,0x13,0x00,0x7C,0x22,0x11,0x00,0x00,0x1E,0x00,0x00,0x00,0xFD,0x00,0x30,
//0x78,0x1E,0x5E,0xFF,0x00,0x0A,0x20,0x20,0x20,0x20,0x20,0x20,0x00,0x00,0x00,0xFC,
//0x00,0x41,0x70,0x6C,0x56,0x69,0x73,0x69,0x6F,0x6E,0x38,0x35,0x30,0x0A,0x00,0x02
//};

//edid6
// extracted from an iMac and given by user oshimai
//https://forums.macrumors.com/threads/imac-g3-mod-video-connector.1712095/post-28359571

/*
 * oshimai extracted this from a debian installation on an iMac G3 DV
 * So far this EDID works the best so I'm making it the default one.
 */

const byte edid[128] = {
  0x00, 0xff, 0xff, 0xff, 0xff, 0xff, 0xff, 0x00, 0x06, 0x10, 0x05, 0x9d,
  0x01, 0x01, 0x01, 0x01, 0x00, 0x08, 0x01, 0x01, 0x08, 0x1b, 0x14, 0x96,
  0xe8, 0x66, 0xe9, 0x9c, 0x57, 0x4c, 0x96, 0x26, 0x10, 0x48, 0x4c, 0x00,
  0x02, 0x00, 0x01, 0x01, 0x01, 0x01, 0x01, 0x01, 0x01, 0x01, 0x01, 0x01,
  0x01, 0x01, 0x01, 0x01, 0x01, 0x01, 0x88, 0x13, 0x80, 0xc0, 0x20, 0xe0,
  0x22, 0x10, 0x10, 0x40, 0x13, 0x00, 0x0e, 0xc8, 0x10, 0x00, 0x00, 0x1e,
  0x60, 0x18, 0x20, 0xf0, 0x30, 0x58, 0x20, 0x20, 0x10, 0x50, 0x13, 0x00,
  0x0e, 0xc8, 0x10, 0x00, 0x00, 0x1e, 0x00, 0x00, 0x00, 0xfd, 0x00, 0x4b,
  0x75, 0x3c, 0x3c, 0x08, 0x00, 0x0a, 0x20, 0x20, 0x20, 0x20, 0x20, 0x20,
  0x00, 0x00, 0x00, 0xfc, 0x00, 0x69, 0x4d, 0x61, 0x63, 0x0a, 0x20, 0x20,
  0x20, 0x20, 0x20, 0x20, 0x20, 0x20, 0x00, 0xc9
};

/*
* this edid was provided by oshimai, it's been upgraded to version 1.4 from
* version 1.0
* https://forums.macrumors.com/threads/imac-g3-mod-video-connector.1712095/post-28411000
*/
//const byte edid[128] = {
//0x00, 0xff, 0xff, 0xff, 0xff, 0xff, 0xff, 0x00, 0x06, 0x10, 0x05, 0x9d,
//0x01, 0x01, 0x01, 0x01, 0xff, 0x0a, 0x01, 0x04, 0x08, 0x1b, 0x14, 0x96,
//0xe8, 0x66, 0xe9, 0x9c, 0x57, 0x4c, 0x96, 0x26, 0x10, 0x48, 0x4c, 0x00,
//0x02, 0x00, 0x31, 0x79, 0x45, 0x63, 0x01, 0x01, 0x01, 0x01, 0x01, 0x01,
//0x01, 0x01, 0x01, 0x01, 0x01, 0x01, 0x88, 0x13, 0x80, 0xc0, 0x20, 0xe0,
//0x22, 0x10, 0x10, 0x40, 0x13, 0x00, 0x0e, 0xc8, 0x10, 0x00, 0x00, 0x1e,
//0x60, 0x18, 0x20, 0xf0, 0x30, 0x58, 0x20, 0x20, 0x10, 0x50, 0x13, 0x00,
//0x0e, 0xc8, 0x10, 0x00, 0x00, 0x1e, 0x00, 0x00, 0x00, 0xfd, 0x00, 0x4b,
//0x75, 0x3c, 0x3c, 0x08, 0x00, 0x0a, 0x20, 0x20, 0x20, 0x20, 0x20, 0x20,
//0x00, 0x00, 0x00, 0xfc, 0x00, 0x69, 0x4d, 0x61, 0x63, 0x20, 0x47, 0x33,
//0x0a, 0x20, 0x20, 0x20, 0x20, 0x20, 0x00, 0x3d
//};

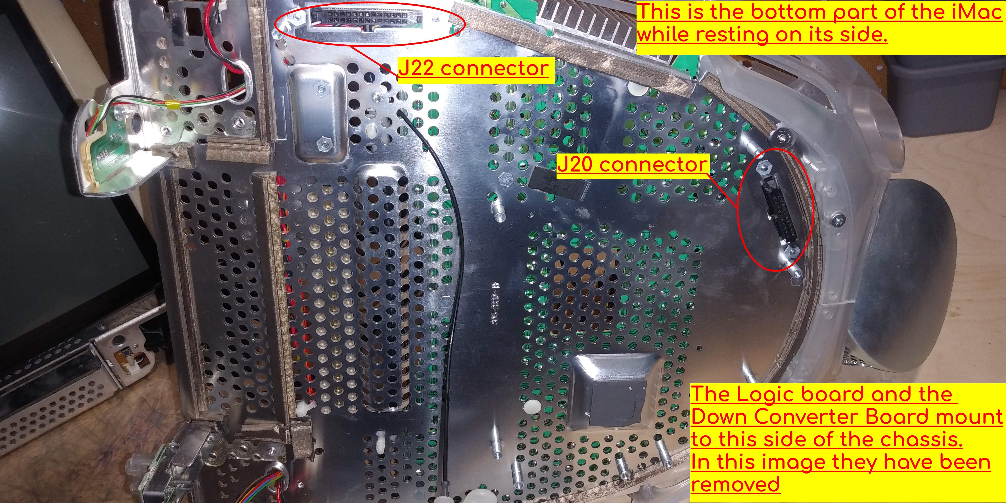
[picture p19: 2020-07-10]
images/chassis.jpg

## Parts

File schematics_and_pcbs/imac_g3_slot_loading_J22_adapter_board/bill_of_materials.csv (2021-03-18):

Manufacturer Part Number | Manufacturer | Digi-Key Part Number | Customer Reference | Reference Designator | Packaging | Part Status | Quantity | Unit Price | Extended Price | Quantity Available | Mfg Std Lead Time | Description | RoHS Status | Lead Free Status | REACH Status
SJ1-3533NG | CUI Devices | CP1-3533NG-ND |  |  | Tray | Active | 1 | 1.18000 | $1.18 | 0 | 11 Weeks | CONN JACK STEREO 3.5MM R/A | RoHS Compliant | Lead free | Not Available
CF14JT220R | Stackpole Electronics Inc | CF14JT220RCT-ND |  |  | Cut Tape (CT) | Active | 1 | 0.10000 | $0.10 | 234432 | 24 Weeks | RES 220 OHM 1/4W 5% AXIAL | ROHS3 Compliant | Lead free | REACH Unaffected
CF14JT220R | Stackpole Electronics Inc | CF14JT220RCT-ND |  |  | Cut Tape (CT) | Active | 1 | 0.10000 | $0.10 | 234432 | 24 Weeks | RES 220 OHM 1/4W 5% AXIAL | ROHS3 Compliant | Lead free | REACH Unaffected
1935857 | Phoenix Contact | 277-9080-ND |  |  | Bulk | Active | 1 | 2.30000 | $2.30 | 605 | 4 Weeks | TERM BLK 10P SIDE ENTRY 5MM PCB | RoHS Compliant | Lead free | Not Available
67997-206HLF | Amphenol ICC (FCI) | 609-3234-ND |  |  | Bag | Active | 1 | 0.35000 | $0.35 | 10232 | 13 Weeks | CONN HEADER VERT 6POS 2.54MM | RoHS Compliant | Lead free | REACH Unaffected
CF14JT2K20 | Stackpole Electronics Inc | CF14JT2K20CT-ND |  |  | Cut Tape (CT) | Active | 1 | 0.10000 | $0.10 | 41877 | 24 Weeks | RES 2.2K OHM 1/4W 5% AXIAL | ROHS3 Compliant | Lead free | REACH Unaffected
USA1H010MDD1TE | Nichicon | 493-14556-1-ND |  |  | Cut Tape (CT) | Active | 1 | 0.29000 | $0.29 | 2916 | 19 Weeks | CAP ALUM 1UF 20% 50V RADIAL | ROHS3 Compliant | Lead free | REACH Unaffected
AOM-5024L-HD-R | PUI Audio, Inc. | 668-1596-ND |  |  | Bulk | Active | 1 | 3.16000 | $3.16 | 8330 | 13 Weeks | MICROPHONE COND ANALOG OMNI | ROHS3 Compliant | Lead free | Not Available
929665-02-13-I | 3M | 3M156308-26-ND |  |  | Bulk | Active | 1 | 4.95000 | $4.95 | 1523 | 2 Weeks | CONN HEADER VERT 26POS 2.54MM | RoHS Compliant | Lead free | REACH Unaffected

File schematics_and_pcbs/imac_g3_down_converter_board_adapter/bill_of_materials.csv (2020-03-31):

Manufacturer Part Number | Manufacturer | Digi-Key Part Number | Customer Reference | Reference Designator | Packaging | Part Status | Quantity | Unit Price | Extended Price | Quantity Available | Mfg Std Lead Time | Description | RoHS Status | Lead Free Status | REACH Status
0430452400 | Molex | WM4728-ND |  |  | Tray | Active | 1 | 6.20000 | $6.20 | 406 | 4 Weeks | CONN HEADER R/A 24POS 3MM | ROHS3 Compliant | Lead free | REACH Unaffected
1935857 | Phoenix Contact | 277-9080-ND |  |  | Bulk | Active | 1 | 2.29000 | $2.29 | 667 | 8 Weeks | TERM BLK 10P SIDE ENTRY 5MM PCB | RoHS Compliant | Lead free | Not Available
1935187 | Phoenix Contact | 277-1579-ND |  |  | Bulk | Active | 1 | 0.84000 | $0.84 | 10518 | 7 Weeks | TERM BLK 4POS SIDE ENTRY 5MM PCB | RoHS Compliant | Lead free | Not Available
0470531000 | Molex | WM4330-ND |  |  | Bag | Active | 1 | 0.46000 | $0.46 | 14543 | 11 Weeks | CONN HEADER VERT 4POS 2.54MM | ROHS3 Compliant | Lead free | REACH Unaffected

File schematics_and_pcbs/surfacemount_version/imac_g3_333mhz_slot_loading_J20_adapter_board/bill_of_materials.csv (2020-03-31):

Manufacturer Part Number | Manufacturer | Digi-Key Part Number | Customer Reference | Reference Designator | Packaging | Part Status | Quantity | Unit Price | Extended Price | Quantity Available | Mfg Std Lead Time | Description | RoHS Status | Lead Free Status | REACH Status
9B-16.000MBBK-B | TXC CORPORATION | 887-2015-ND |  |  | Bulk | Active | 1 | 0.30000 | $0.30 | 1681 | 13 Weeks | CRYSTAL 16.0000MHZ 20PF T/H | RoHS Compliant | Lead free | Not Available
TSW-110-23-G-D | Samtec Inc. | SAM1068-10-ND |  |  | Bulk | Active | 1 | 1.92000 | $1.92 | 801 | Not Available | CONN HEADER VERT 20POS 2.54MM | ROHS3 Compliant | Lead free | REACH Unaffected
L77HDE15SD1CH4F | Amphenol ICC (Commercial Products) | L77HDE15SD1CH4F-ND |  |  | Tray | Active | 1 | 1.51000 | $1.51 | 147 | 5 Weeks | CONN DSUB HD RCPT 15POS R/A SLDR | RoHS Compliant | Lead free | Not Available
LCC110 | IXYS Integrated Circuits Division | CLA106-ND |  |  | Tube | Active | 1 | 3.79000 | $3.79 | 1208 | 6 Weeks | SSR RELAY SPDT 120MA 0-350V | ROHS3 Compliant | Lead free | REACH Unaffected
CF14JT220R | Stackpole Electronics Inc | CF14JT220RCT-ND |  |  | Cut Tape (CT) | Active | 1 | 0.10000 | $0.10 | 37887 | 20 Weeks | RES 220 OHM 1/4W 5% AXIAL | ROHS3 Compliant | Lead free | REACH Unaffected
1N5819-E3/54 | Vishay Semiconductor Diodes Division | 1N5819-E3/54GICT-ND |  |  | Cut Tape (CT) | Active | 1 | 0.45000 | $0.45 | 32593 | 8 Weeks | DIODE SCHOTTKY 40V 1A DO204AL | ROHS3 Compliant | Lead free | REACH Unaffected
1N5819-E3/54 | Vishay Semiconductor Diodes Division | 1N5819-E3/54GICT-ND |  |  | Cut Tape (CT) | Active | 1 | 0.45000 | $0.45 | 32593 | 8 Weeks | DIODE SCHOTTKY 40V 1A DO204AL | ROHS3 Compliant | Lead free | REACH Unaffected
CF14JT10K0 | Stackpole Electronics Inc | CF14JT10K0CT-ND |  |  | Cut Tape (CT) | Active | 1 | 0.10000 | $0.10 | 329624 | 20 Weeks | RES 10K OHM 1/4W 5% AXIAL | ROHS3 Compliant | Lead free | REACH Unaffected
UPW0J471MPD | Nichicon | 493-1702-ND |  |  | Bulk | Active | 1 | 0.36000 | $0.36 | 6705 | 19 Weeks | CAP ALUM 470UF 20% 6.3V RADIAL | ROHS3 Compliant | Lead free | REACH Unaffected
ATMEGA328P-PU | Microchip Technology | ATMEGA328P-PU-ND |  |  | Tube | Active | 1 | 2.08000 | $2.08 | 1721 | 8 Weeks | IC MCU 8BIT 32KB FLASH 28DIP | ROHS3 Compliant | Lead free | REACH Unaffected
61200621621 | Würth Elektronik | 732-5394-ND |  |  | Tray | Active | 1 | 0.45000 | $0.45 | 7331 | 15 Weeks | CONN HEADER VERT 6POS 2.54MM | ROHS3 Compliant | Lead free | REACH Unaffected
67997-206HLF | Amphenol ICC (FCI) | 609-3234-ND |  |  | Bag | Active | 1 | 0.33000 | $0.33 | 15098 | 8 Weeks | CONN HEADER VERT 6POS 2.54MM | RoHS Compliant | Lead free | Not Available
CF14JT10K0 | Stackpole Electronics Inc | CF14JT10K0CT-ND |  |  | Cut Tape (CT) | Active | 1 | 0.10000 | $0.10 | 329624 | 20 Weeks | RES 10K OHM 1/4W 5% AXIAL | ROHS3 Compliant | Lead free | REACH Unaffected
CF14JT10K0 | Stackpole Electronics Inc | CF14JT10K0CT-ND |  |  | Cut Tape (CT) | Active | 1 | 0.10000 | $0.10 | 329624 | 20 Weeks | RES 10K OHM 1/4W 5% AXIAL | ROHS3 Compliant | Lead free | REACH Unaffected
1935174 | Phoenix Contact | 277-1578-ND |  |  | Box | Active | 2 | 0.60000 | $1.20 | 6640 | 7 Weeks | TERM BLK 3POS SIDE ENTRY 5MM PCB | RoHS Compliant | Lead free | Not Available
CC45SL3AD220JYNNA | TDK Corporation | 445-15973-ND |  |  | Bulk | Active | 2 | 0.37000 | $0.74 | 2452 | 10 Weeks | CAP CER 22PF 1KV SL RADIAL | ROHS3 Compliant | Lead free | Not Available

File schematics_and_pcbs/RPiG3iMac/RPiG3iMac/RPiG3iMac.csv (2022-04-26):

Reference | Quantity | Value | Footprint | Datasheet | Manufacturer | Part Number | DigiKey
C1 | 1 | 10uF 25V | Capacitor_SMD:C_0603_1608Metric | https://media.digikey.com/pdf/Data%20Sheets/Samsung%20PDFs/CL10A106MA8NRNC_Spec.pdf | Samsung Electro-Mechanics | CL10A106MA8NRNC | 1276-1869-1-ND
C2 C3 | 2 | 22uF 10V | Capacitor_SMD:C_0603_1608Metric | https://media.digikey.com/pdf/Data%20Sheets/Samsung%20PDFs/CL10A226MP8NUNC_Spec.pdf | Samsung Electro-Mechanics | CL10A226MP8NUNE | 1276-1274-1-ND
D1 | 1 | 40V 3A | Diode_SMD:D_SMB | http://www.smc-diodes.com/propdf/SK310B%20N0283%20REV.A.pdf | SMC Diode Solutions | SK310B | 1655-2295-1-ND
D2 D3 D4 D8 D9 D10 | 6 | --- | LED_SMD:LED_0603_1608Metric | https://www.lumex.com/spec/SML-LXIL0603SIC-TR.pdf | Lumex Opto/Components Inc. | SML-LXIL0603SIC-TR | 67-2333-1-ND
D5 D6 D7 | 3 | 100V 150mA | Diode_SMD:D_SOD-123 | https://www.comchiptech.com/admin/files/product/QW-BA018%20CDBW46-G%20RevD.pdf | Comchip Technology | CDBW46-G | 641-1964-1-ND
J1 | 1 | 12VDC IN | TerminalBlock_Phoenix:TerminalBlock_Phoenix_MKDS-1,5-2-5.08_1x02_P5.08mm_Horizontal | https://media.digikey.com/pdf/Data%20Sheets/Phoenix%20Contact%20PDFs/1729128.pdf | Phoenix Contact | 1729128 | 277-1247-ND
J2 | 1 | RPi | Rudy:Harwin_M20-7812045_2x20_P2.54mm_Vertical_rpi | https://cdn.harwin.com/pdfs/C001XX_M20_Series_Connectors.pdf | Harwin Inc. | M20-7812045 | 952-3218-ND
J3 | 1 | SERIAL TO iMAC G3 J20 BOARD | TerminalBlock_Phoenix:TerminalBlock_Phoenix_MPT-0,5-5-2.54_1x05_P2.54mm_Horizontal | https://media.digikey.com/pdf/Data%20Sheets/Phoenix%20Contact%20PDFs/1725685.pdf | Phoenix Contact | 1725685 | 277-1276-ND
J4 J5 J6 | 3 | --- | TerminalBlock_Phoenix:TerminalBlock_Phoenix_MPT-0,5-2-2.54_1x02_P2.54mm_Horizontal | https://media.digikey.com/pdf/Data%20Sheets/Phoenix%20Contact%20PDFs/1725656_Ds.pdf | Phoenix Contact | 1725656 | 277-1273-ND
Q1 | 1 | BC817 | Package_TO_SOT_SMD:SOT-23 | https://www.mccsemi.com/pdf/Products/BC817-16~BC817-40(SOT-23).pdf | Micro Commercial Co | BC817-16-TP | BC817-16-TPMSCT-ND
R1 | 1 | 1K0 | Resistor_SMD:R_0603_1608Metric | https://industrial.panasonic.com/cdbs/www-data/pdf/RDM0000/AOA0000C328.pdf | Panasonic Electronic Components | ERJ-PB3B1001V | P19972CT-ND
R2 R3 | 2 | 2K0 | Resistor_SMD:R_0603_1608Metric | https://industrial.panasonic.com/cdbs/www-data/pdf/RDO0000/AOA0000C331.pdf | Panasonic Electronic Components | ERJ-PA3J202V | P2KBZCT-ND
R4 R6 | 2 | 470 | Resistor_SMD:R_0603_1608Metric | https://industrial.panasonic.com/cdbs/www-data/pdf/RDM0000/AOA0000C328.pdf | Panasonic Electronic Components | ERJ-PB3D4700V | P20245CT-ND
R5 R7 R8 R9 | 4 | 220 | Resistor_SMD:R_0603_1608Metric | https://industrial.panasonic.com/cdbs/www-data/pdf/RDM0000/AOA0000C328.pdf | Panasonic Electronic Components | ERJ-PB3B2200V | P19894CT-ND
RV1 | 1 | 5M0 | Potentiometer_THT:Potentiometer_Bourns_3296Y_Vertical | https://www.bourns.com/docs/product-datasheets/3296.pdf | Bourns Inc. | 3296Y-1-505LF | 3296Y-1-505LF-ND
U1 | 1 | RPM5.0-3.0 | Converter_DCDC:Converter_DCDC_RECOM_RPMx.x-x.0 | https://recom-power.com/pdf/Innoline/RPM-3.0.pdf | Recom Power | RPM5.0-3.0 | 945-3254-1-ND
FAN | 1 | --- | --- | https://media.digikey.com/pdf/Data%20Sheets/Sunon%20PDFs/MF25101V2-1000U-A99.pdf | Sunon Fans | MF25101V2-1000U-A99 | 259-1833-ND
J2 HEADER | 1 | --- | --- | http://suddendocs.samtec.com/prints/esq-sdt.pdf | Samtec Inc. | ESQ-120-14-G-D | SAM8767-ND

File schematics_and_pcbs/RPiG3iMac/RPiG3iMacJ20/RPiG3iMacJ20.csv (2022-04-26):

Reference | Quantity | Value | Footprint | Datasheet | Manufacturer | Part Number | DigiKey
D1 D2 D3 | 3 | LED | LED_SMD:LED_0603_1608Metric | https://www.lumex.com/spec/SML-LXIL0603SIC-TR.pdf | Lumex Opto/Components Inc. | SML-LXIL0603SIC-TR | 67-2333-1-ND
J1 J2 | 2 | Conn_02x03_Odd_Even | Rudy:Harwin_M20-7810345_2x03_P2.54mm_Vertical | https://cdn.harwin.com/pdfs/C001XX_M20_Series_Connectors.pdf | Harwin Inc. | M20-7810345 | 952-3208-ND
J3 | 1 | Screw_Terminal_01x05 | TerminalBlock_Phoenix:TerminalBlock_Phoenix_MPT-0,5-5-2.54_1x05_P2.54mm_Horizontal | https://media.digikey.com/pdf/Data%20Sheets/Phoenix%20Contact%20PDFs/1725685.pdf | Phoenix Contact | 1725685 | 277-1276-ND
R1 | 1 | 470 | Resistor_SMD:R_0603_1608Metric | https://industrial.panasonic.com/cdbs/www-data/pdf/RDM0000/AOA0000C328.pdf | Panasonic Electronic Components | ERJ-PB3D4700V | P20245CT-ND
R2 R3 | 2 | 220 | Resistor_SMD:R_0603_1608Metric | https://industrial.panasonic.com/cdbs/www-data/pdf/RDM0000/AOA0000C328.pdf | Panasonic Electronic Components | ERJ-PB3B2200V | P19894CT-ND

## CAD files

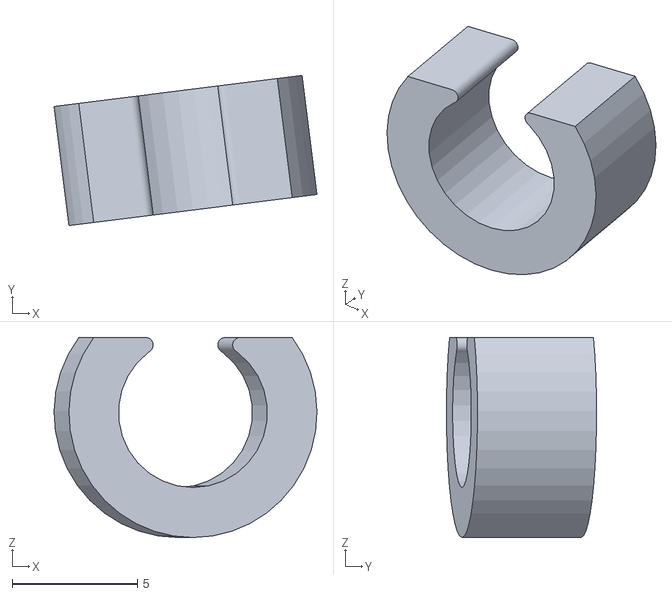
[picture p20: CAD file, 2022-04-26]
rpi_mount/rpi_g3_spacer_v1.stl
10.5 x 6.01 x 8.00

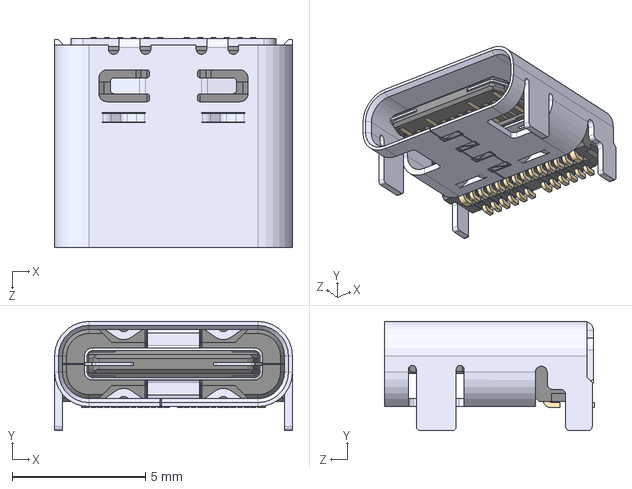
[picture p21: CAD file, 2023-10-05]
schematics_and_pcbs/surfacemount_version/imac_g3_333mhz_slot_loading_J20_adapter_board/3d_models/usb_c_connector_105450-0101.step
8.94 x 4.10 x 7.90 mm

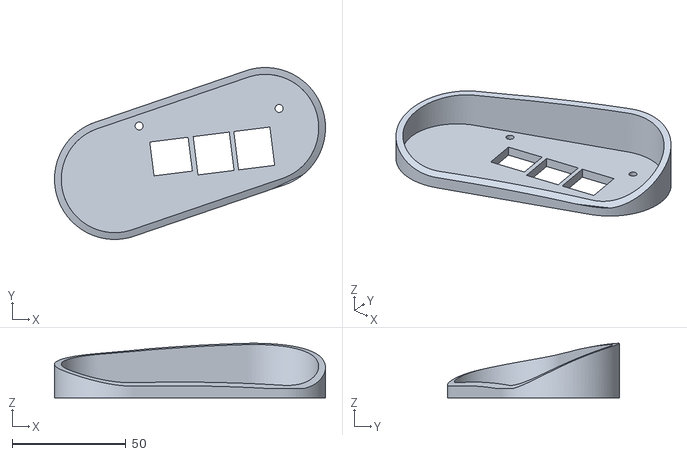
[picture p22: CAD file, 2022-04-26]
rpi_mount/rpi_g3_bezel_v3.stl
119.2 x 75.6 x 24.0

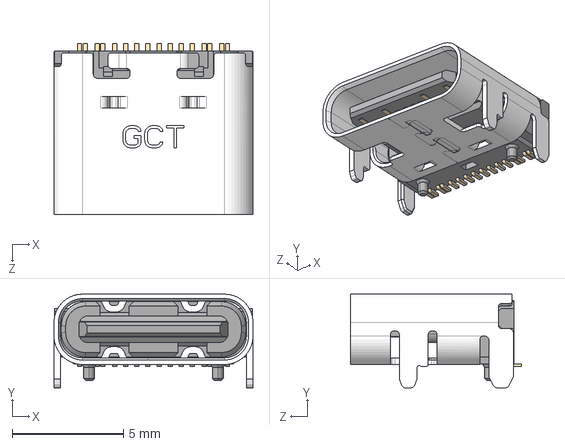
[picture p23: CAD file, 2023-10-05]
schematics_and_pcbs/surfacemount_version/imac_g3_333mhz_slot_loading_J20_adapter_board/3d_models/USB4105-GF-A.step
8.94 x 4.21 x 7.70 mm
HSG_默认

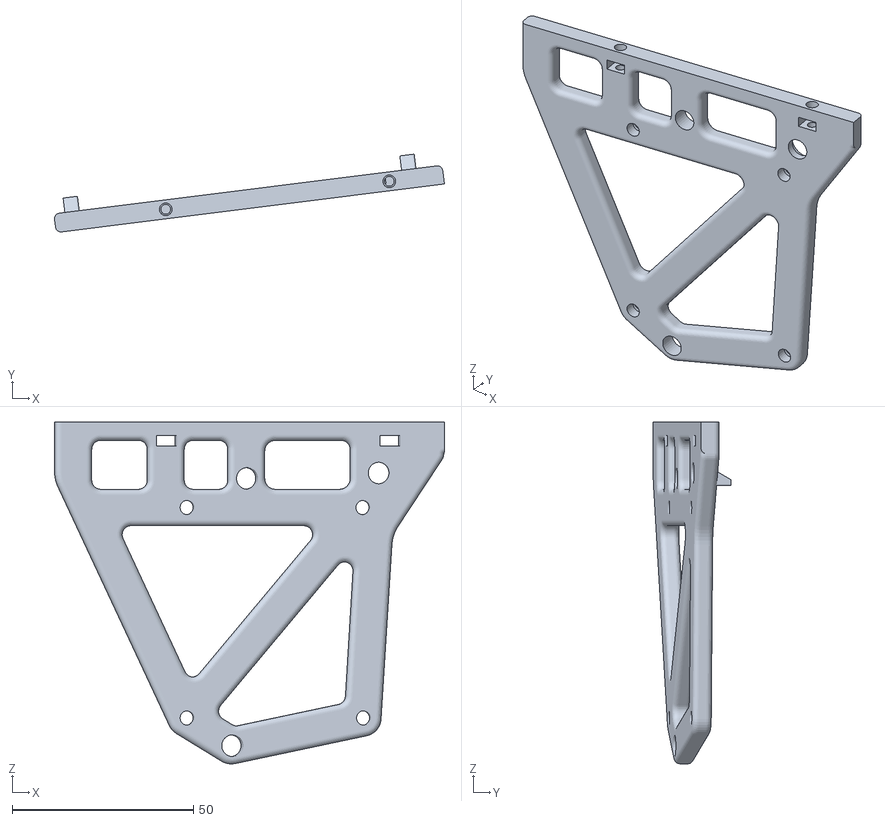
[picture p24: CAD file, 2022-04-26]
rpi_mount/rpi_g3_plate_v2.stl
107.5 x 21.4 x 94.1

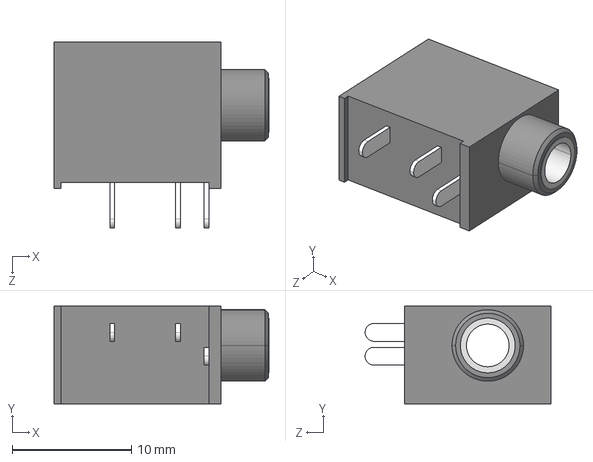
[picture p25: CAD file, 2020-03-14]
schematics_and_pcbs/imac_g3_down_converter_board_adapter/3d_models/CUI_DEVICES_SJ1-3533NG.step
18.1 x 8.20 x 15.6 mm

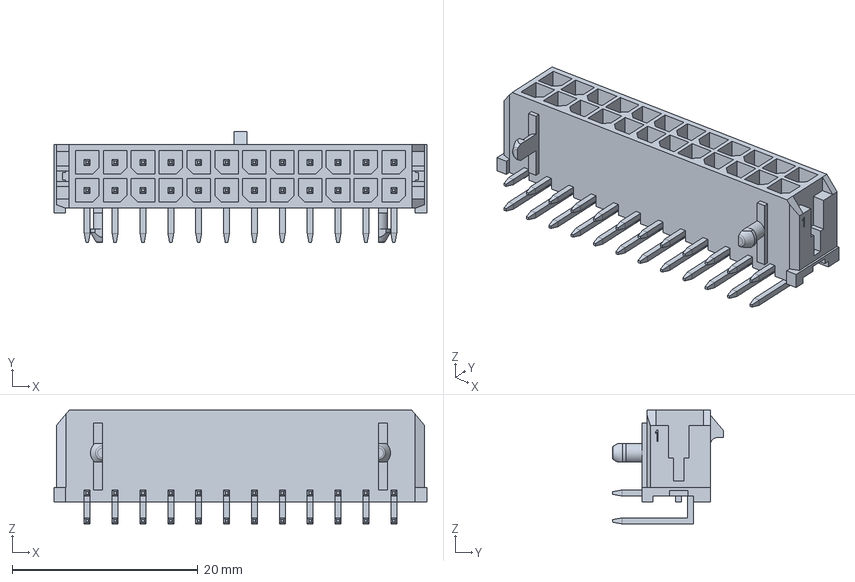
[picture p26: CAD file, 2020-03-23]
schematics_and_pcbs/imac_g3_down_converter_board_adapter/3d_models/430452400.stp
40.1 x 11.9 x 12.2 mm

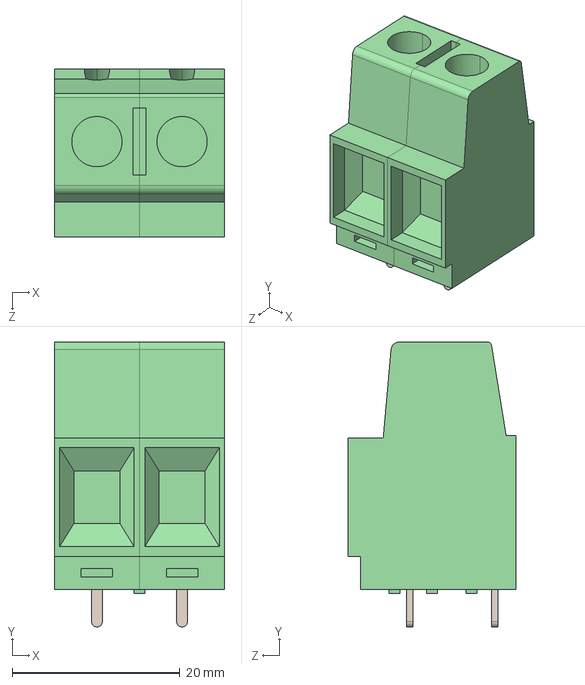
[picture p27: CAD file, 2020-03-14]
schematics_and_pcbs/imac_g3_down_converter_board_adapter/3d_models/EM292902-UL.STEP
20.3 x 34.0 x 20.0 mm

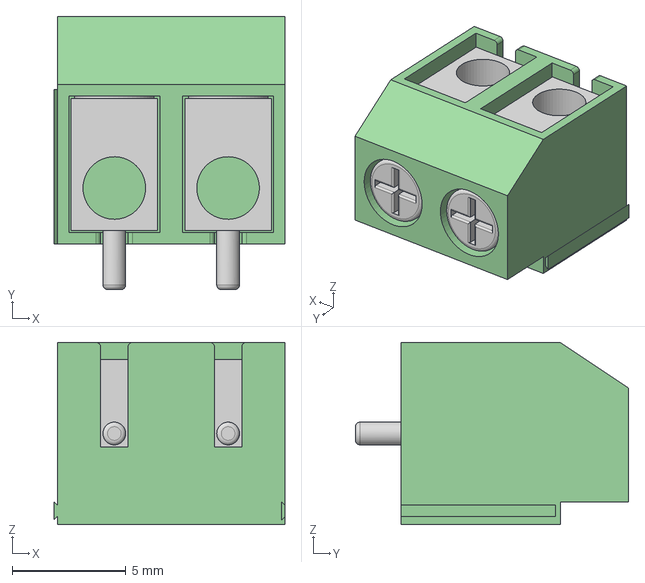
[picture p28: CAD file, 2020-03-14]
schematics_and_pcbs/imac_g3_down_converter_board_adapter/3d_models/Screw Terminal Block 5mm 2-way.step
10.2 x 12.0 x 8.00 mm

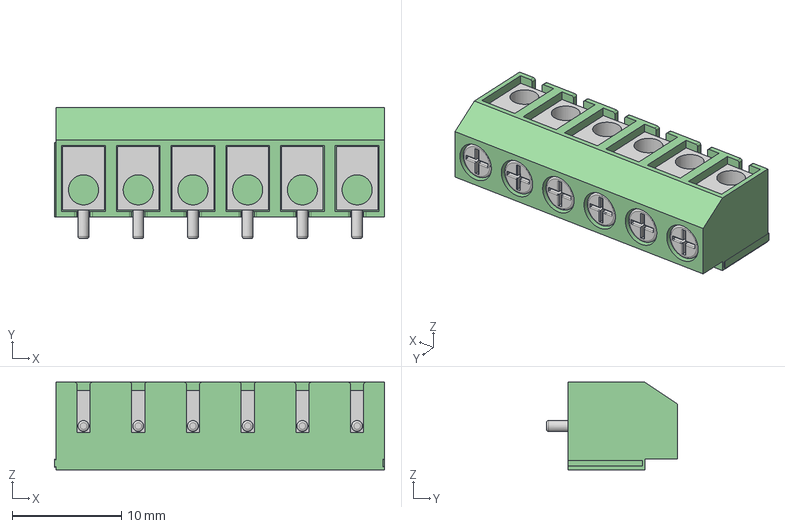
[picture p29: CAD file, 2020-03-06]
schematics_and_pcbs/surfacemount_version/imac_g3_333mhz_slot_loading_J20_adapter_board/3d_models/Screw Terminal Block 5mm 6-way.step
30.1 x 12.0 x 8.00 mm

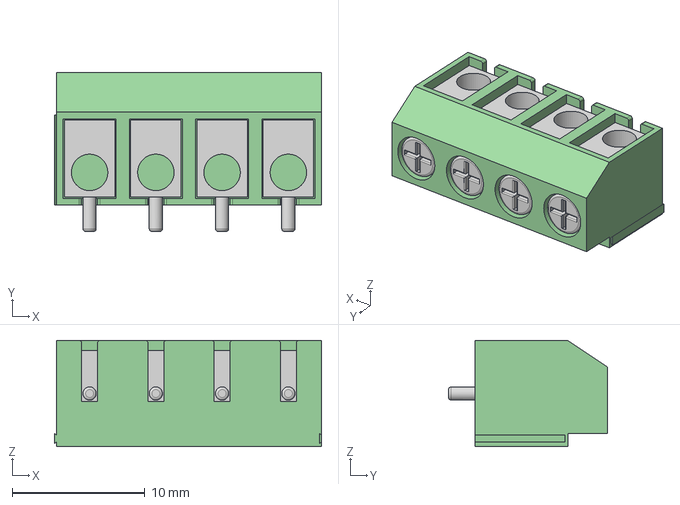
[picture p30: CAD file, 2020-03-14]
schematics_and_pcbs/imac_g3_down_converter_board_adapter/3d_models/Screw Terminal Block 5mm 4-way.step
20.1 x 12.0 x 8.00 mm

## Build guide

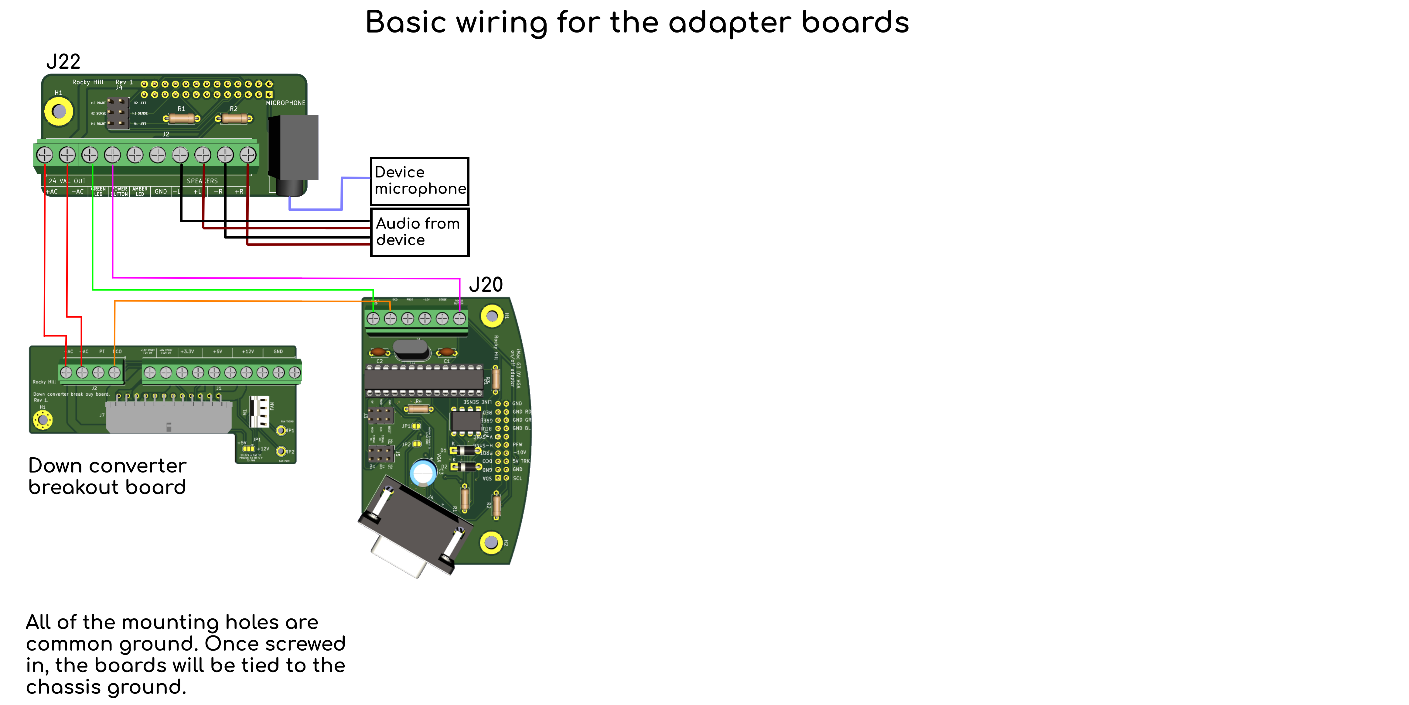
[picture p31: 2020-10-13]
images/basic_wiring.png

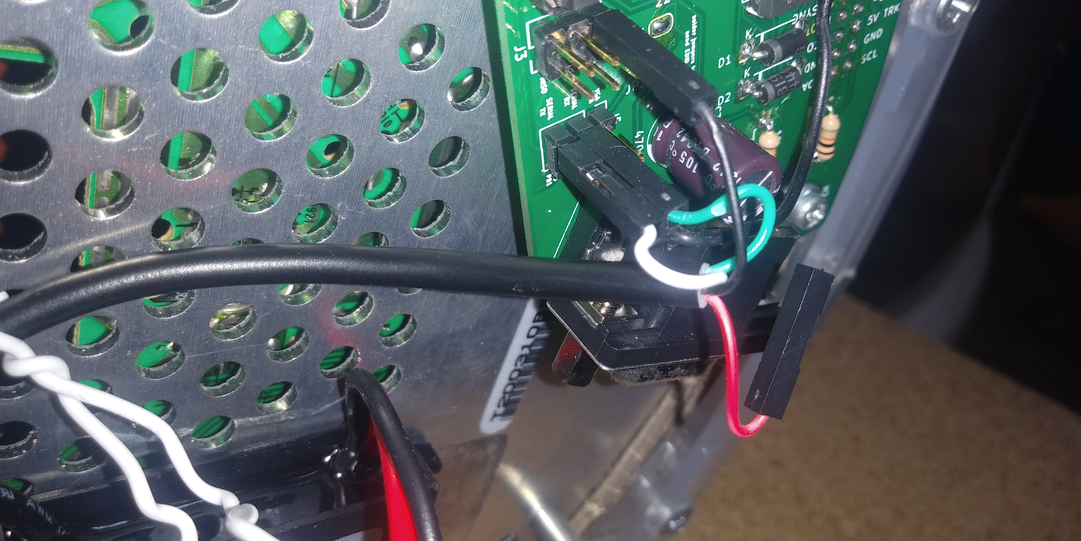
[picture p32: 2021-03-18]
images/wiring_usb_2_serial_debugger.jpg

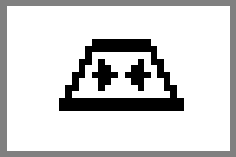
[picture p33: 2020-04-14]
ImacG3DVDisplayProperties/build/classes/imacg3dvdisplayproperties/resources/keystone_pinch_top.png

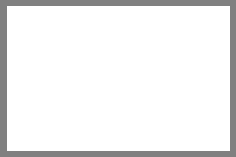
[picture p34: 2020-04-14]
ImacG3DVDisplayProperties/build/classes/imacg3dvdisplayproperties/resources/rectangle.png

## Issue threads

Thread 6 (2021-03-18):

609-3367-ND vertical connecting header is "non-stock" item

chanunnaki, 2021-03-18:
I don't know if this is the right place to put this, but I'm putting in an order with Digikey and one item is listed as being a non-stock item.

That's the 609-3367-ND vertical connecting header.

Is there another substitute item that can stand in for this one?

I'm not sure if it's just on the Digikey Ireland website which I'm ordering from either.

chanunnaki, 2021-03-18:
I can see the J20 boards needs

609-3234-ND 2x03 Vert conn header.

I wonder if they are the same and I can just get two of those instead.

qbancoffee, 2021-03-18:
That is a bummer, I always try to find regularly stocked parts but I guess this one isn't any longer.
As long as the pitch is the same, you should be able to place several of those next to each other
util it adds up to 26.

I'll look around to see if I can find a substitute.

chanunnaki, 2021-03-18:
great, I was thinking the same thing, I will order 6 of the 2x3 and just mate 5 of them together.

qbancoffee, 2021-03-18:
Here is a 26 position header that looks like it might be a better fit then the original.
3M156308-26-ND
I'll update the BOM with this part number.

BTW I have contact info in my profile.

Good luck and please let me know how it goes.

chanunnaki, 2021-03-18:
Great! Thanks a million, I'll order this one and I will let you know how it goes.

In the future I'll use your email or catch you on macrumors :P

Closed 2021-03-18.

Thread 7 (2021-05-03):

Imac G3 Timings?

StrikerMan780, 2021-05-03:
I am wondering, what are the display formats/timings for the Imac G3? I have a device that takes custom timings, and I want to capture the G3's VGA-Out. Figured you might know this. (I'm specifically trying to capture the 640x480, 117hz mode.

qbancoffee, 2021-05-03:
Sounds like fun.

Well, the iMac G3 supports 3 resolutions.

   1024x768 @ 75 Hz  <---standard timings.
   800x600 @ 95 Hz
   640x480 @ 117 Hz

This is what I get when I decode the EDID used in the sketch

Manufacturer: APP Model 9d05 Serial Number 16843009
EDID version: 1.1
Analog display, Input voltage level: 0.7/0.3 V
Sync: Separate
Maximum image size: 27 cm x 20 cm
Gamma: 2.50
DPMS levels: Standby Suspend Off
RGB color display
Established timings supported:
  1024x768@75Hz
Standard timings supported:
Detailed mode: Clock 50.000 MHz, 270 mm x 200 mm
                640  656  720  832 hborder 0
                480  481  484  514 vborder 0
               +hsync +vsync
Detailed mode: Clock 62.400 MHz, 270 mm x 200 mm
                800  816  896 1040 hborder 0
                600  601  604  632 vborder 0
               +hsync +vsync
Monitor ranges (GTF): 75-117Hz V, 60-60kHz H, max dotclock 80MHz
Monitor name: iMac
Checksum: 0xc9 (valid)
EDID block does NOT conform to EDID 1.0!
	Has descriptor blocks other than detailed timings
EDID block does not conform at all!
	Bad year of manufacture

Have you used cvt or gtf to get that sort of info?

I hope that helps.

StrikerMan780, 2021-05-03:
here's an image of the current timings I'm using. The picture is mostly correct, but I have a bunch of flickering garbage at the right-side of the screen:

http://shadowmavericks.com/files/ShareX/GefenSyner-G_2021-05-03_16-02-52.png

qbancoffee, 2021-05-04:
Oh sorry , I somehow missed this.
I'll check it out when I get home.

qbancoffee, 2021-05-05:
its close to what is in one of the edids I use.

try these values. The first column is what you want

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

Closed 2021-08-30.

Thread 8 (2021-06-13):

Emac with just a Pi4

earthwormjim-uk, 2021-06-13:
Have been inspired to try this with an Emac and a Pi4 (no arduino). VGA cable is made and i2cdetect is reporting 46 and 53, as expected.  Looking at the emac_ivad_board_init for the arduino and contemplating next steps, any suggestions or pointers?
Thanks!

qbancoffee, 2021-06-15:
Sorry, I missed this message.

Wow, I hope you get it to work and please share what you've learned.
The sending of the initialization string is very similar for both the eMac and the iMac
so you might just need to modify the python script that runs from the pi and be good to go.
using the iMac without an arduino is possible and here is a link to the video if you haven't seen it.
https://youtu.be/isjo-4vQxwM

it's in the root and it's called "init_ivad.py"

You should only need to edit the config.txt and add the following at the bottom.
hdmi_group=2hdmi_ignore_edid=0xa5000080#hdmi_mode=1#hdmi_mode=87hdmi_cvt=1152 864 80 1

good luck!

earthwormjim-uk, 2021-06-15:
Thanks for replying. what you have described is exactly the approach I've taken, which gives me encouragement that I can get it to work. The CRT is making all the right sounds so I think I'm close, probably just missing something.  When I get it going I'll share the script, Cheers!

earthwormjim-uk, 2021-06-16:
Small update, it's now working and usable at the CLI but needs more work - the screen geometry and settings aren't great, and there is screen flickering in retroarch / retropie.  Maybe need some specific retroarch.cfg settings?

qbancoffee, 2021-06-16:
Most of the changes I made were in the config.txt and I don't remember making changes in retroarch.
Are you supplying the custom monitor settings or are you loading the edid.dat in the repo?
Are you using the sample config.txt file? Can you include a picture of how the image looks?

Great progress!

earthwormjim-uk, 2021-06-17:
Pictures below.  I'm trying to understand exactly how the config.txt works.  It seems that if I set ignore_edid, then it even ignores the manually specified edid.dat file, is that as expected? it's not how I read the documentation. I'm getting interesting results by creating my own edid.dat files but nothing I'm completely happy with.  The edid in the emac repo not working for me.

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

qbancoffee, 2021-06-17:
You've made really good progress!
Generally I've found the documentation to be pretty good when it comes to the raspberry pi 3 however,
I can't say the same for the raspberry pi 4.

That said, I have found that the edid bit in the documentation works as documented.
You've probably seen this already but to use the edid file you need the following line with your filename provided.

hdmi_edid_file=1
hdmi_edid_filename:0=FileForPortZero.edid
hdmi_edid_filename:1=FileForPortOne.edid

It looks like you're trying to fill the whole screen. Is that why you're unhappy with your results?
This part really frustrated me because I couldn't fill the whole screen without some sort of distortion at the edges and to my chagrin it seemed like Apple never intended it to be filled either.

Look for eMac pictures and you'll see that there is usually a 1 inch black border around the image.

earthwormjim-uk, 2021-06-20:
Thanks, couldn't have done this without the great work done by yourself and pedropena.  I may be being optimistic but I think it should be possible to get better output. I created some custom edid files but they didn't seem to work so reconnected the emac logic board and dumped the edid, so I have a the edid used by OSX. Checking it with edid-decode it is valid and has the expected values in it, however unfortunately edidparser concludes that only DVI is supported and the max resolution is 1024x768.  If I use this and disable the v3d driver in config.txt I get a really good output, no borders, no flickering (see below), but only up to 1024x768 :-(
I'd like to retain the v3d driver and get higher res, getting a good edid.dat as suggested by pedropena might do it.
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

qbancoffee, 2021-06-22:
I'm not home at the moment but when I get back home I think I can help you out with an EDID that can get you a higher resolution.
That said, you results are fantastic!

earthwormjim-uk, 2021-06-23:
thanks, hope your getting some holiday time! small update from some more experimenting over the weekend - looking at the edid dumped from the emac in an editor and comparing with another, I've changed my mind - I don't think the edid is the answer, and I don't think it's possible to create a good edid for this?  The CRT settings just don't match any of the standard or preferred settings for an edid.  Instead I've used the edid to derive the complete monitor timings and put those in the config file using hdmi_timings=.  This looks (almost) great at 1280x960, but doesn't work for 1024x768 for reasons I don't understand.  The 'almost' is that although geometry and resolution are near perfect, there are small but irritating screen artefacts (speckles), again for reasons unknown.  I'm hoping that this isn't due a limitation of the pi implementation of hdmi_timings, which seems to only cope with whole number horizontal refresh rates.  any thoughts on that?
 I will upload some code and scripts when I get it fine tuned. The pic doesn't do it justice but;
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

qbancoffee, 2021-06-23:
Thanks, tons of fun in the sun!

Great results and I know what you mean by the pic doesn't do it justice, I went through the same thing...
You are correct that the res and refresh rates are not vesa standards but you can specify custom timings in
an edid file and using an edid editor, I was able to create a custom edid using aw edid editor, by analog way, I think....

I was also able to create a custom timing that worked well with a pi 2 and a pi 3. Regarding the annoying sparklies,
I noticed that was an issue only when I used a VGA cable longer than about one foot and that didn't have a ferrite choke.

I'll look through my files when I get home because clearly I forgot to put some things in the repo.

Great progress!

earthwormjim-uk, 2021-06-24:
Interesting, I also used AWEdidEditor and started with the edid dumped from the (OSx) eMac.  I found that the piemac looked at the edid and didn't see anything it liked, so went with a less-than-optimum default (according to tvservice at least).
I've also looked at CRU, which is nice utility but didn't give me any more than AWEdidEditor did.  Using a pi4 I suspect is part of the problem, a different GPU means some of the sw implementations maybe are still not ironed out?
If I could just lose the speckles / artefacts it would be great, but I'm struggling with that.  The cable is only 6/7 inches long, and now has 3 ferrite cores on it! I still think it's a sw issue, currently experimenting with fbset, and vcgencmd, both of which give inconsistent results as well and haven't solved the artefacts.   Learning lots, but not sure what else to try - more ferrite cores? :-D

earthwormjim-uk, 2021-07-09:
Fixed the artefacts this evening after not touching this for a couple of weeks, it now looks really good, just tinkering with the hex values to get the best out of it, I'll upload some code for the emac, can I add into this repo? let me know and I'll close this issue off, thanks for all help and encouragement.

qbancoffee, 2021-07-09:
glad to hear you have a clean picture now!
The best way to add to the repo is by forking it and making changes to your fork. You can then submit a pull request and I'll go over the changes and merge them to the main branch making sure there is a history of where it came from and so on and so forth.
If you're not familiar with git then it seem like it's more work than it's worth in which case you can send it to me and
add it to the repo and properly credit you somewhere.

earthwormjim-uk, 2021-07-10:
Yeah happy to use git, expect a pull request at some point, thanks.

Closed 2021-07-10.

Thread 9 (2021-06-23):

Solid State Relay

wickerwaka, 2021-06-23:
I have a question about the use of the relay on the J20 board. Is there a reason the PFW and LPIACT signals can't be pulled high/low by the microcontroller directly (high current requirements?) or was it just easier to combine those signals and the led into a single switch?

qbancoffee, 2021-06-24:
Hi,
While testing I was bringing those hi and lo with the micro controller and it was working well but one day it didn't work and I found that somehow the inputs on the atmega had burnt. For all I know it could have been static discharge but I decided to use a solid state relay just in case. I think the SSR is rated to 200mA which I thought would  be safe upper limit.

wickerwaka, 2021-06-24:
Thanks for the response. Great project!

Closed 2021-06-24.

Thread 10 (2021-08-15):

iMac G3 (non slot loading) with DB-15 connector instead of VGA

BeanieBen9990, 2021-08-15:
Hey, I'm wanting to do this with my older, first generation iMac, but it has a two-row DB-15 connector. Still 15 pins like VGA, but with a different layout. Are the same numbered pins the same, or is there a separate pinout diagram for the DB-15 connector?

BeanieBen9990, 2021-08-15:
Actually some more quick research led me to [this!](https://old.pinouts.ru/Video/maclcvideo_pinout.shtml)

It hopefully is the right pinout, and everything here should work since there are corresponding pins, just not the same numbers

qbancoffee, 2021-08-15:
Hi,
Is your G3 a slot loader? If it is, then this mod can't be done to it, the slot loader and the tray loader are just too different on the inside...
Unfortunately I don't have a slot loader to mod myself so I can't really confirm much about how to mod it. That said, I have talked with a couple of people that have modded  a slot loader and it turns out it's a bit easier to do.

http://whatdoyouguyswannado.com/Zotac_Powered_Grape_iMac_revD/

https://forums.macrumors.com/threads/imac-g3-mod-video-connector.1712095/page-16?post=29085273#post-29085273

Good luck.

BeanieBen9990, 2021-08-15:
No, it's not a slot loader, however, I was under the impression that the iMac being referred to in this documentation was a slot loader.

BeanieBen9990, 2021-08-15:
For example, the very first line in the readme:
> Add custom boards to an iMac G3 DV(slot loader) in order to use it as a monitor without having to destroy it.

Does this not refer to a slot loading G3 if it says that?

qbancoffee, 2021-08-15:
Sorry that was a typo on my part... I'm still having my coffee. I meant to say if your's  is a tray loader.

BeanieBen9990, 2021-08-15:
Ahh Gotcha. Honestly, I'm going a very different route with what I'm actually doing, but the pinout diagram and most of the video connector stuff would definitely work and this stuff is hugely helpful. Thanks!

qbancoffee, 2021-08-15:
Eventually I plan on getting a tray loader and I'll definitely document what I do with it just like I did for the slot loader.
Please share whatever it is you end up doing because I think there is still quite a bit to learn about the tray loader.

Good luck!

Closed 2021-08-30.

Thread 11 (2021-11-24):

Consider sending EDID in bursts instead of patching Wire library?

shuuryou, 2021-11-24:
Hello

To make the sketch work in its current state the Wire library needs to be patched in two locations so its buffer size is 128 instead of 32.

I am curious as to why you decided to go with that approach. Did sending the EDID in chunks not work?

e.g. like this (totally untested pseudocode)

```
/* somewhere in the global scope */
// Default buffer size of unpatched Wire library
#define TWI_BUFSIZE 32

#define EDID_LENGTH 128
// (or like this, GCC is hopefully smart enough to optimize it into a constant)
// int EDID_LENGTH = sizeof(edid) / sizeof(byte);

byte edid_chunk_buf[TWI_BUFSIZE];

/* where the EDID is sent to the controlling PC */
int i;
for (i=0;i<EDID_LENGTH;i++)
{
  if (i!=0&&i%TWI_BUFSIZE==0)
    Wire.write(edid_chunk_buf, TWI_BUFSIZE);

  edid_chunk_buf[i%TWI_BUFSIZE] = edid[i];
}

// next 2 lines not really necessary if EDID_LENGTH is always a multiple of TWI_BUFSIZE
if ((TWI_BUFSIZE-i%TWI_BUFSIZE)!=0)
  Wire.write(edid_chunk_buf, (TWI_BUFSIZE-i%TWI_BUFSIZE));
```

I am currently (again, after destroying the first one last year) trying stuff with an eMac and building on the foundations you painfully figured out for that heavy monster. But since your iMac sketch is the pretty one I thought I'd file this here.

The real pain with the eMac is finding a HDMI>VGA adapter that will attempt to do the insane refresh rates on lower resolutions. That's a different story though.

qbancoffee, 2021-12-06:
Hello,

Yes, I tried sending it in bursts and sometimes it would work but I had many many issues with HDMI to VGA adapters.
In the end it was not very reliable so I decided to patch the wire library. I know it isn't the cleanest but until I figure out a
more reliable way of doing it, I need something reproducible.

The eMac was my first conversion and it is one I need to revisit. I had to take a break from most of the stuff I was doing with these projects but I'm planning on revisiting the eMac project to make it as doable as the iMac one.

shuuryou, 2021-12-07:
I ashamed to say that I had the same results as you, unfortunately. :(

I also gave up (for now) and went with this:
```
#if BUFFER_LENGTH < EMAC_EDID_BIN_LEN
#error Must patch the Wire library to send EDID correctly.
#endif
```
BUFFER_LENGTH is in Wire.h or TWI.h; I forget which. But it stops the compile if the library isn't patched.

Same issue with HDMI to VGA adapters. I got a used HDF1 Nano GX which won't pass through my EDID but will at least do the insane refresh rates without crapping out.

I have a Sketch for the eMac and a very crude "GUI" ready. I will put it in my emac repo soon. I also brought the iMac G3 VGA thread on forums.macrumors.com back from the dead.

qbancoffee, 2021-12-10:
Well, I know there's some general handshaking with the HDMI to VGA that I can't figure out and I think it's erratic because of
the limited memory on these devices. I can hard code sending burst EDID and it works on  a per converter basis not a good
general solution....

I can't wait to see your GUI, it will be a great addition! I have some projects lined up that I need to finish but the emac is definitely one project I really want to revisit.

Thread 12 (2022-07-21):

I have some questions about the project.

gerardit, 2022-07-21:
Do I just need the monitor? or do I also need the power supply?
How do I know if my iMac is slot-loader or tray-loader?
I saw in the wiki a link to order speakers, Can I use the original ones?

gerardit, 2022-07-23:
Okay, thanks for the info. Also, I have been reviewing the BOMs and there's a part on Digikey that says it's obsolete.
This is the part USA1H010MDD1TE
Do you know another place where I can order it or a substitute part? DigiKey suggest me another component but the substitute has a minimum order quantity of 2000

gerardit, 2022-07-23:
You made a really nice job with that. You know a lot.

Closed 2022-07-29.

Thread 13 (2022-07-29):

Im trying to order the BOM on digikey but theres a component that is not available

gerardit, 2022-07-29:
I have been reviewing the BOMs and there's a part on Digikey that says it's obsolete.
This is the part USA1H010MDD1TE
Do you know another place where I can order it or a substitute part? DigiKey suggest me another component but the substitute has a minimum order quantity of 2000.

qbancoffee, 2022-07-30:
Take a look at this one on DigiKey. 1189-4015-ND

fradotkso, 2023-09-28:
1189-4015-ND is no longer available in small quantities (bulk 5000 items). With similar specifications I found this one instead on Digikey:  105RSS050M-ND

Closed 2022-09-14.

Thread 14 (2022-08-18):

Everything is assembled, but the monitor doesn't show anything.

Clochard123, 2022-08-18:
Hello, I followed the wiki step by step but something isn't working. I'm trying to understand if it's because some shoddy soldering, some faulty component or rather my Italian iMac G3 that may want a different edid. When i connect a laptop to the vga port on the J20 board, it recognizes a new monitor. As soon as the power chord is connected, the green led on the button turns on and I can hear the cathodic tube warming up. But no image is shown and after a few seconds of inactivity everything turns off. Then if i push the power button, all that happens again, it turns on with no picture just to turn off a few moments later.
Do you happen to have seen this behaviour before? Can it tell us where is the issue in my boards?
Thank you in advance.

qbancoffee, 2022-08-18:
There could be a number of reason why there is no picture so let me ask you a couple of questions.
-Does the iMac work with the original logic board?
-Are you using the latest version of the firmware? If you are, you can comment line 180 so that the iMac that it doesn't turn off after 30 seconds of inactivity. The reason it turns off is because it isn't detecting a vertical sync pulse coming from the video
source.

    //do stuff whn vsyncDetect is 0
    if (vsyncDetect <= 0) {
      startTime = 0;
      currentTime = 0;
//       externalCircuitOff();  <----Comment this line to disable sgutting off when there is no vertical sync pulse

Upload it to the J20 board after commenting.

-Do you have another computer you can use as a video source? Sometimes in two monitor configurations the second display is turned off by default and the signals are not sent in time to the second display.

-Are you using some sort of video converter like an HDMI to VGA converter? I've had a handful of converters that don't
work well.

From the sounds of it, you are very close to getting this to work so don't give up. A handful of people have gotten this mod to work in Europe and Japan so I think that your Italian iMac should work.

Clochard123, 2022-08-20:
Thank you for answering so quickly!
The iMac worked with the original board, and I'm not using video converters. I tried using different computers to no avail.

But commenting the line 170  // externalCircuitOff() DID prevent the monitor from turning off! So now we know v-sync isn't receiving the signal. I'll check my soldering on the vga port and on the j20 pin. What other connection could be preventing the vertical pulse?

Thank you again for pointing me to the right  direction.

gerardit, 2022-11-28:
> Thank you for answering so quickly! The iMac worked before I tore it down, and I'm not using video converters. I tried using different computers to no avail.
>
> But commenting the line 170 // externalCircuitOff() DID prevent the monitor from turning off! So I suspected the v-sync pulse was cut somewhere. But the tester says there is continuity between the vga port and the corresponding j20 pin.

Did you solve it? Im having same issue the monitor is detected but doesnt show anything

qbancoffee, 2022-11-28:
No worries, good luck with school, this will be around for a while!

gerardit, 2022-11-29:
> No worries, good luck with school, this will be around for a while!

I have been trying a couple of things and the green light used to turn on, now not even that.
I might think theres a power issue. Im trying to get the pinout of the down converter board but I didnt find it. Do you have it?

gerardit, 2022-11-29:
> No worries, good luck with school, this will be around for a while!

I have been trying a couple of things and the green light used to come on, now not even that.
Measured sthe volts and they are not ok so i supose there a power issue with the down converter board. Is tehre any way i could use a normal ATX power supply?

Clochard123, 2023-08-29:
Here I am! I must confess that I completely gave up when I found a working Apple Studio Display from 1999 for just 15 euros. It's bigger, has higher resolution and already has a vga socket. Maybe it's better to close the issue here.
Probably my G3 went simply bad and I can't test it anymore because I lost the motherboard. I did see however your last video so maybe I could test this new method just to see if the problem was inside the imac or the custom boards.

Clochard123, 2023-10-12:
Ok, I finally tried connecting directly the raspberry pi to j20! Unluckily, It powers on when I short pin 6 but the screen gives no sign of life whatsoever. It seems like the old crt was the problem all along, but at least now I know it. It also means my boards were not the issue so maybe I'll use them on another G3 if I ever find one for cheap. Thank you for your incredible work and for giving assistance!

Clochard123, 2023-10-13:
The raspberry pi method works! Whatever was the problem with my boards now I completely circumvented it. This is perfect, because my plan was already to use it connected to a rpi and this just cuts down the middle man. Thank you so much!

qbancoffee, 2023-10-13:
I'm just now reading all of these messages.

Glad to hear it's working! Are you still using the custom boards or are you directly connecting the raspberry pi?

If you are directly connecting the raspberry pi without the custom boards, consider using this python script to adjust your settings.
https://github.com/qbancoffee/imac_g3_osd_cli

Clochard123, 2023-10-14:
I'm directly connected with the raspberry pi and yes, I really need an easy way to adjust the settings because the left side of the desktop is missing and I can't even see the applications menu. Problem is, I don't know a thing about Python! I guess I'll have to clone the repo first, and then run the scripts from the terminal top to bottom, but if you were planning to make some guide I'll gladly wait... I don't want to take chances now that I'm so close!

qbancoffee, 2023-10-17:
I added install and start instrcutions.
https://github.com/qbancoffee/imac_g3_osd_cli/tree/main

This should be enough to get you going. The menu is pretty self explanatory but I will write instructions when I get some time.

Clochard123, 2023-10-18:
Thank you! the installation was a breeze and I had fun with the menu. But no matter how far I pushed Width and Horizontal position I didn't manage to see the whole desktop. On the left I can't go further than the browser icon, and even on the right side a piece is missing. It's like there is some sort of overscanning even when I shrink it down.

Closed 2023-10-13.

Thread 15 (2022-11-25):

When i try to upload the code to my arduino it shows this error

gerardit, 2022-11-25:
C:\Users\gerar\Downloads\imac_g3_ivad_board_init-master\imacG3IvadInit\imacG3IvadInit.ino:50:10: fatal error: EEPROMWearLevel.h: No such file or directory
 #include <EEPROMWearLevel.h>
          ^~~~~~~~~~~~~~~~~~~
compilation terminated.

exit status 1

Compilation error: EEPROMWearLevel.h: No such file or directory

qbancoffee, 2022-11-27:
Ah, that looks like you need o load that library. The Arduino has a spot where you can search, find and install that library.
go to "Tools----->Manage Libraries" and search for "EEPROMWearLevel" and install it. It should compile after that.

Closed 2022-11-28.

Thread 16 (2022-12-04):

Apple Studio Display (M7768) boot signal - Potentially Related?

TitaniaEXE, 2022-12-04:
Hello, I've been looking into the ADC Apple Studio Display, model M7768. This is Apple's last CRT, and it uses ADC as it's connector. It's possible to split it back into VGA + USB + Power (+LED +Soft Power), either by a converter or simply splicing the wires. However, the Display will only "boot" if it's connected to a G4-G5 era Mac, as it needs some sort of boot signal.

Now, some known things about this monitor:
* It accepts DDC over USB, to calibrate it. You can audibly trigger the degauss with it.
* It can be woken up even when connected to a VGA/DVI-A port on a proper mac, if the ADC cable is split to it.
* [Per /u/crt09](https://www.reddit.com/r/crtgaming/comments/smrb3f/comment/hvyuuyj/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), the signal is probably coming over DDC.

Is there any possibility the boot signal this monitor expects is related to the signals these IVAD boards use?

qbancoffee, 2022-12-31:
I'm not sure if ti uses the same sort of sequence but I wouldn't doubt it. The best way to know is if you can sniff the comms between the two when starting it up. Do you have a way of sniffing the comms?

TitaniaEXE, 2022-12-31:
I currently lack a compatible Mac system to connect it to, or a logic analyzer. However, using Linux it is possible to transmit arbitrary i2c/DDC signals, so it should  be possible to try the signals. Given that the monitor is active enough to transmit EDID and handle DDC over USB, it would seem that it only needs a "start up" signal, as the device is already awake enough to handle those.

TitaniaEXE, 2023-01-17:
Using an HDMI to VGA adapter, the monitor presents four i2c registers at the bus:
- 3a
- 50 (contains EDID for the monitor)
- 55
- 5a
I reckon I could use i2cset for write_byte_data, and i2cget for read_byte, but I am not certain what would replicate simple write_byte.

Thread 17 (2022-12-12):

I have everything assembled but the screen doesnt shows anything.

GerardPolloRebozado, 2022-12-12:
At first when I click the button it turned on and you heard the electric sound and the green led also turned on, now it doesnt turn on so I supose there is a power issue. Is there anyway i coul use a standard computer PSU to power it?

qbancoffee, 2022-12-31:
You shouldn't need to use a standard PSU to power the iMac because the analog board takes care of that.
Are you using an arduino to send the init sequence?

gerardDuPre, 2023-01-02:
> You shouldn't need to use a standard PSU to power the iMac because the analog board takes care of that. Are you using an arduino to send the init sequence?

yes i am

gerardDuPre, 2023-01-23:
> You shouldn't need to use a standard PSU to power the iMac because the analog board takes care of that. Are you using an arduino to send the init sequence?

So probably the analog board is broken? How can i test whats causing not turning on?

gerardDuPre, 2023-01-27:
> You shouldn't need to use a standard PSU to power the iMac because the analog board takes care of that. Are you using an arduino to send the init sequence?

I have been testing some voltages.
As far as i know by just having the computer pluged in the J20 pin of 5V trickle voltage should be 5V?
My tester read 0.1.
What gives the 5V to the J20? The analog board? or the down converter?

qbancoffee, 2023-08-29:
Have you made any progress with this?

GerardPolloRebozado, 2023-09-03:
No, still same issue don't know whats the problem, I just give up probably the thing that was like a PSU ( I don't remember its name) is broken the iMac wasn't wworking well before trying this.

Closed 2024-03-06.

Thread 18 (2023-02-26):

CRT no picture?

Linkneo5, 2023-02-26:
Hi all,

I should preface this by noting I am a complete amateur and likely am missing something obvious but I would love some help.

Everything is set up, but when I turn on the power the screen remains black. There is a green light indicating power and I can hear static when the CRT is turned off and on. But no image and the computer cannot detect it at all. I did make sure to comment "externalCircuitOff()" under when "vsyncDetect is 0".

Info: The iMac works with the original logic board, I am not using an VGA to HDMI adapter (though I will try it) and I have tried a couple different cables and two different PCs.

Any help would be appreciated. Thanks for your time.

Linkneo5, 2023-05-11:
OK, so I am an idiot. I had two problems: I added the wrong library when programming the MIC (I downloaded Softwire not SoftwareWire) and my VGA to HDMI adapter was HDMI **output** ONLY. So yeah, rookie mistakes all around. Ordered a new VGA adapter from Amazon (a [DTECH HDMI to VGA Adapter with HDMI OUT](https://www.amazon.ca/dp/B09P579LCB/ref=redir_mobile_desktop?_encoding=UTF8&ref=ppx_pop_mob_b_asin_title&th=1)) and boom. Tested and works! PS3 via HDMI out to the iMac G3 works great! Now to get a MiSTer or one of my older consoles hooked up :)

Closed 2023-05-11.

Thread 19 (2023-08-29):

Adapting iMac FP to ATX motherboard

crozone, 2023-08-29:
Hi, I'm creating this issue to track the problems that I'm facing when interfacing the iMac FP panels to an ATX motherboard. This may be a scenario that other people attempt.

Currently the imac_g3_slot_loading_J22_adapter_board behaves as a relatively simple breakout board for the FP connector, with some nice convenience features like microphone power adaptation.

However, I've noticed some issues when attempting to wire this to an ATX motherboard.

## FP LED/Switch board integration

### FP Switch

Works fine. However, polarity matters. ATX power switch pins are un-polarized, they just expect to be shorted to power on. In practice they are usually +5V and GND with some inline resistor. This means the polarity has to be measured with a multimeter and motherboard GND must be connected to FP GND in order to not accidentally short +5V to ground.

### FP LED

Both power and sleep LEDs have a common ground, and take a +5V input to activate. The LED expects an open-emitter style circuit. However, most motherboards I've found have an open collector design for their LED outputs, where the +5V pin is constantly powered (even while PC is off!), and a transistor switches on and off the ground side of the pin.

This is problematic, because the ground is shared with the FP Switch, which is already tied to motherboard ground. When connected, the LED receives a constant +5V, and also has a constant ground via the FP switch ground, so stays lit all of the time (even when the PC is off).

### Solution

Somehow the open-collector circuit from the motherboard power LED pins needs to be adapted into an open-emitter circuit. I think this can be solved by placing a single PNP transistor such that:
* Emitter is wired to motherboard power LED +ve (constant +5V)
* Base is wired to motherboard power LED -ve (open-collector switching ground), probably with an inline resistor (idk I'm not an electrical engineer)
* Collector is wired to FP LED +ve
* Constant motherboard ground is wired to FP GND (or to motherboard power LED -ve via a diode?)

Additionally, the FP switch could be isolated so that it doesn't matter what polarity the wires are connected. Not really sure how to do this without something silly like a relay.

## FP Audio

Wiring FP audio channel outputs is simple. iMac FP connector has isolated left and right wires for each jack. Intel HD Audio header has the exact same thing. Jack detection is a problem however.

The iMac FP Audio connector has normally open jack detect switches J1_SW and J2_SW bridged to a common ground.

Intel HD Audio is weirder. It detects what is plugged into it by measuring the resistance between the HD Audio SENSE_SEND pin and reference GND. There is also a SENSE1_RETURN and SENSE2_RETURN pin on the motherboard header, however these are not actually necessary and really just a convenience feature. They're bridged to ground via an appropriate resistor such that when SENSE_SEND is connected to them, it "sees" jack 1 or jack 2 is connected.

Reference: 7.4.2 Audio Jack Detection Circuits, Page 222, [Intel High Definition Audio Specification](https://www.intel.com/content/dam/www/public/us/en/documents/product-specifications/high-definition-audio-specification.pdf)

### Solution

In order to adapt the FP Audio connectors to Intel HD Audio:
* SENSE_SEND is wired to J1_SW via 39.2 kOhm resistor
* SENSE_SEND is also wired to J2_SW via 20 kOhm resistor

## New adapter board

For ATX integration it probably makes sense to create an ATX interop version of imac_g3_slot_loading_J22_adapter_board which has the additional required interfacing circuity, as well as the pins for ATX power switch, ATX power LED, ATX HDD LED (can be wired to iMac sleep LED), and the Intel HD Audio header pins.

I'm currently learning KiCad so I'll probably eventually take a shot at this, but if anyone wants to jump in first, please please do.

qbancoffee, 2023-08-29:
Have you been able to get any of this to work? If so, describe what you did and I'll try and capture it in KiCAD.
A different version of the J22 board is a good idea, these are good recommendations.

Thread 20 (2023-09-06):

Ivad sequence sent but display not showing anything

cardoric, 2023-09-06:
Hi, I finally got some time to delve into this project and wanted to ask for some help to get this working.

First of all, I would like to thank you for all your efforts in putting together these extremely detailed resources. It is super insightful and inspiring!

The reason for opening this issue is that, like others, I also got stuck on the step where I successfully managed to send the initialization sequence to the ivad board, but the display is still not showing any picture.

Just as a preamble, I'm using an iMac G3 (slot loading), and the screen works properly when connected to the original logic board. Also, I'm not sending the EDID sequence to the computer; however, I believe this shouldn't be a problem at this point.

**Test 1:**

To provide you with more details about my setup:

- I'm not using the breakout board you've created. Instead, I've wired an Arduino Uno with jumper wires to test the concept and see if I could get something.
- The wiring setup is pretty simple: all wires from the VGA are connected to the J20 connector following your wiring diagram. Apart from the SDA and SCL wires that are connected to the Arduino via jumper wires plugged directly into the J20 connector on the iMac. I double-checked all the wiring a couple of times just to make sure all the connections were correct.
- While you have a pretty fancy setup using SSR and a power button, just for testing purposes, I decided to bypass all of that. This means that I shorted Pin 12 and 10 of the J20 connector to Pin 6 (5V trickle) of that same connector using jumper wires. The Arduino Uno is also powered using the 5V trickle.
- For the Arduino code, I changed the buffer size of the Wire libraries to 128.
- I also uncommented line 136 of the latest Arduino sketch (externalCircuitOn();), which, to my understanding, will initialize the ivad board as soon as I give power to the iMac.
- I'm currently using a VGA to miniDP adapter that connects to an Intel Nuc (my final goal is to implant the Nuc inside the iMac and convert it into an all-in-one Windows PC using the original CRT). However, I also tested this with a Windows laptop that has a built-in VGA out and got the same result as with the adapter.

The result of the first test is that when I give power to the iMac, I can hear the static sound from the CRT followed by a click sound (sort of a relay sound) after a few seconds. If I remember correctly, this sequence of sounds occurred in the same way when using the iMac logic board. However, even after waiting for a long time, no picture was showing on the screen.

**Test 2:**
I then made a second test where I tried to replicate a makeshift version of the power button input:

- I commented out line 136 in the sketch, so that it would wait for power button input to send the sequence.
- I wired PD3 of the Arduino to 5V trickle through a resistor and used a jumper wire from PD3 that I would manually connect to ground, mimicking the behavior of the onboard power button.
- I also commented out line 180 of the sketch just to make sure that the problem was not related to the lack of detection of the Vsync signal.

After giving power to the iMac, I can immediately hear the static of the CRT followed by the click, even before grounding the "power button" input. Shorting PD3 to ground for a short interval doesn't produce any effect, and as a result, I get the same result as in the previous test where no picture is shown on the display.

So my questions are: Is there something fundamentally wrong with my current MVP setup? If not, do you have any other suggestions on how to troubleshoot this?

Thanks

qbancoffee, 2023-09-06:
Hi, thank you for the high praise!

I'm in between meetings at the moment so I'll fire off a quick response that will hopefully help you and if not I'll give you a more detailed response later on tonight.

Everything you've done to power the iMac is correct, including bypassing the power switch.
However at least one of the I2C connections is necessary.

There are a pair of I2C buses we are dealing with in this project, the one that connects the arduino to the J20 connector (SDA_1 and SCL_1)  and one that connects the arduino to the NUC via the VGA cable(SDA_2 and SCL_2).

The first one is absolutely necessary because that is the bus used to send the initialization sequence from the arduino to the IVAD board via the J20 connector.

The second one sends an EDID to the NUC via the VGA cable and is optional if you are willing to manually configure stuff on the NUC.

Without an EDID, the NUC has no way of knowing what the display capabilities of the iMac are so it's more than likely defaulting to a resolution and refresh rate that the iMac can't handle. If this is the issue, you can either connect a monitor to the NUC and manually force a resolution of 1024x768 @ 75Hz and then reconnect the NUC to the iMac or you can connect SDA, SCL and GND from the VGA cable to the arduino. Connecting the the second I2C bus is much easier.

Please let me know how it goes and good luck!

cardoric, 2023-09-06:
Hey, thanks a lot for the quick response. Absolutely no rush in this!

Regarding the EDID sequence, i had tried already to force the NUC resolution to 1024x768 at 75hz with another monitor and then turned off the Nuc. So assuming that the NUC stores the last settings, it should be sorted on that side.

Related to the IVAD/ EDID buses, there is an interesting fact. Basically the IVAD bus is the only one i’ve connected from the arduino to the J20 connector. Although  i’ve noticed a discrepancy: for this bus i used PC4 and 5 from the arduino (same as per the wiring diagram you have in the main page. However after looking at the schematic for the J20 board i noticed in there you’re using PC4 and 5 for the EDID sequence instead, and PD4 and 5 of the arduino for the IVAD sequence. This makes me think that currently i’m sending the EDID sequence to the IVAD board??

I’m not home at the moment, but i will try to switch to the other bus from the arduino to see if that was the problem.

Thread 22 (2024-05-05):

Display showing but purple color

cokeman, 2024-05-05:
I have managed to get the screen to work in the raspberry version but it comes out with violet tones. I'm trying to adjust the green but I'm not getting any results.

qbancoffee, 2024-09-19:
Have you made any progress on this?

MPagliari, 2025-07-04:
OK, SO this is a Necropost to revive this thread. I have just completed the PCB's (v3). however my screen has a strong green tint to it. after researching how to correct this I see that the [service manual ](https://lastin.dti.supsi.ch/VET/sys/Apple/iMAC-G3/iMAC-Service_Guide-2.pdf) for the G3 [Screen voltage - 17] mentions using some service software and a jumper on the neck board. Now I'm OK with opening up Monitors and working on them but since the plastic on these old monitors can be quite brittle with age, I plan to use a pull down resistor on the colour channels to bring the colour levels down. I will try using a 1K pot to bring it down also I will connect a series resistor between the pot and grd so as not to cause a dead short to ground if the pot is lowered to much. **I'm writing this to see if anyone else over the years has come up with a better solution**

qbancoffee, 2025-07-06:
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

I'm glad to hear you have been able to improve things. IF you would like to have more control over the various screen settings, you can use a 5 volt  USB to serial converter and use a very nice GUI based screen controller written by Oshimai that make the process very simple. https://github.com/qbancoffee/imacg3

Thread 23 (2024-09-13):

Display works but has green tint and turns off after a few minutes

LXK-98, 2024-09-13:
First of all thanks for this cool project, I've been loving tinkering with it!

I ordered the PCBs and assembled the ones for the ATMega. I was able to get a signal to the iMac display with my laptop, but the signal has a strong green tint. At first I thought maybe the red signal wasn't coming through but it can display red, it just seems the green and blue signals are a lot stringer (since black colors also have a green-ish tint). It was looking just fine with the original mainboard installed (though I haven't tried reinstalling it yet), so what could be the cause for this?

Additionally no matter what I do, the screen turns off after a few minutes. I can turn it on right again after, but in the end it turns off again.

Lastly, with my laptop the screen signal seems to be fine except for the tint, but with my Raspberry Pi it's flickering like crazy! (And it does have the tint as well)

I've tried using the same setup with another VGA display and it works fine so I doubt the first two issues are related to my setup.

I might try putting the old logic board back and seeing what happens, if I still have the green tint then it might just be a hardware issue.

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

UPDATE: I put the original logic board back in and the screen looks just fine, so I would assume the screen itself is fine

LXK-98, 2024-09-15:
Okay, I was able to fix most of these issues!
Turns out the green color was easy to fix using oshimai's GUI.
The turning off issue was the v-sync detection. Turns out you need to solder the JP3 pads to make it work (I assumed not having them soldered would mean the feature was just off but it seems to be enabled in the sketch by default - I'm not sure why the jumpers are there if cutting the connection doesn't turn off that functionality, but maybe I misunderstood something).
Now I just need to find out why my RPi is causing flickering, maybe it's a wrong refresh rate or something but so far things are looking great!

qbancoffee, 2024-09-19:
I'm glad to hear that you've made so much progress!
Is the flickering random or does it happen at a predictable rate? I have seen that in some setups the vsync detection is a bit wonky and it causes the display to flicker. Find the following function block and comment/remove the function
"externalCircuitOff();"  which should be line 180.

    //do stuff whn vsyncDetect is 0
    if (vsyncDetect <= 0) {
      startTime = 0;
      currentTime = 0;
       externalCircuitOff();

    }

Reload the program and let me know how it behaves.

LXK-98, 2024-09-19:
Alright, I think I have everything figured out. I'm not entirely sure what fixed it but
- I bridged the vsync detecion jumper
- I flashed a fresh retropie image onto my SD card (as opposed to the Raspberry Pi OS image that I had already used for other purposes before)
and now everything seems to be working!
Maybe it was the OS or maybe it was the unbridged vsync jumper that caused the pin on the Atmega to float and do weird stuff. Either way things are looking good!

All that's left for me to do now is to connect the audio and recalibrate the display. Thanks a lot for this cool project, I've been enjoying working on it!

Closed 2024-09-19.

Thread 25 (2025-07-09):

EDID not recieved properly (J20 Surface mount Board)

MattGrayYes, 2025-07-09:
Hiya

Firstly, thanks for the project!
I've had a set of your boards produced, and used the J20 Surface Mount design.

When I plug my mac into it via either of my two USB-C to VGA cables ([1](https://amzn.to/4nFchcd), [2](https://amzn.to/40aqJ1Q)), it doesn't read the EDID.

At first I was wondering if the available adapters just bake in an EDID with some default resolutions, but when I plug it in, your board does get the request, and attempts to respond with an EDID. I realise the VGA adapter could still instigate that process and ignore it, but I haven't found a USB-VGA adapter that claims EDID compatibility, and didnt fancy randomly buying more so I ploughed on.

Using a cheap nanoDLA logic analayser, I connected it to the SDA and SCL headers, and monitored while plugging the USB-C cable in.
It seems to respond with FFFFFFFFFFFFFFFF?

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

Any ideas what's going on here?
I'm happy to admit that this is my first time ever using this logic analyser, but the rest of the data seen on it seems to tally with what I'd expect.

I [forked the code](https://github.com/MattGrayYes/imac_g3_boards/commit/97f28e9fa2a17794d425b57581540c2e1dba814e), to add a load of debug stuff on the Serial bus to help figure this out. (I thought I'd better not send a PR as it's not fully working for me.)

My current workaround is to use [BetterDisplay](https://github.com/waydabber/BetterDisplay) to force load in the EDID for that device on my mac. But it would be nice if I could get it to work plug-and-play as designed!

Cheers

Matt

MattGrayYes, 2025-07-13:
Just tried it with a Startech VGA adapter that claims to have EDID pass through and still nothing :(

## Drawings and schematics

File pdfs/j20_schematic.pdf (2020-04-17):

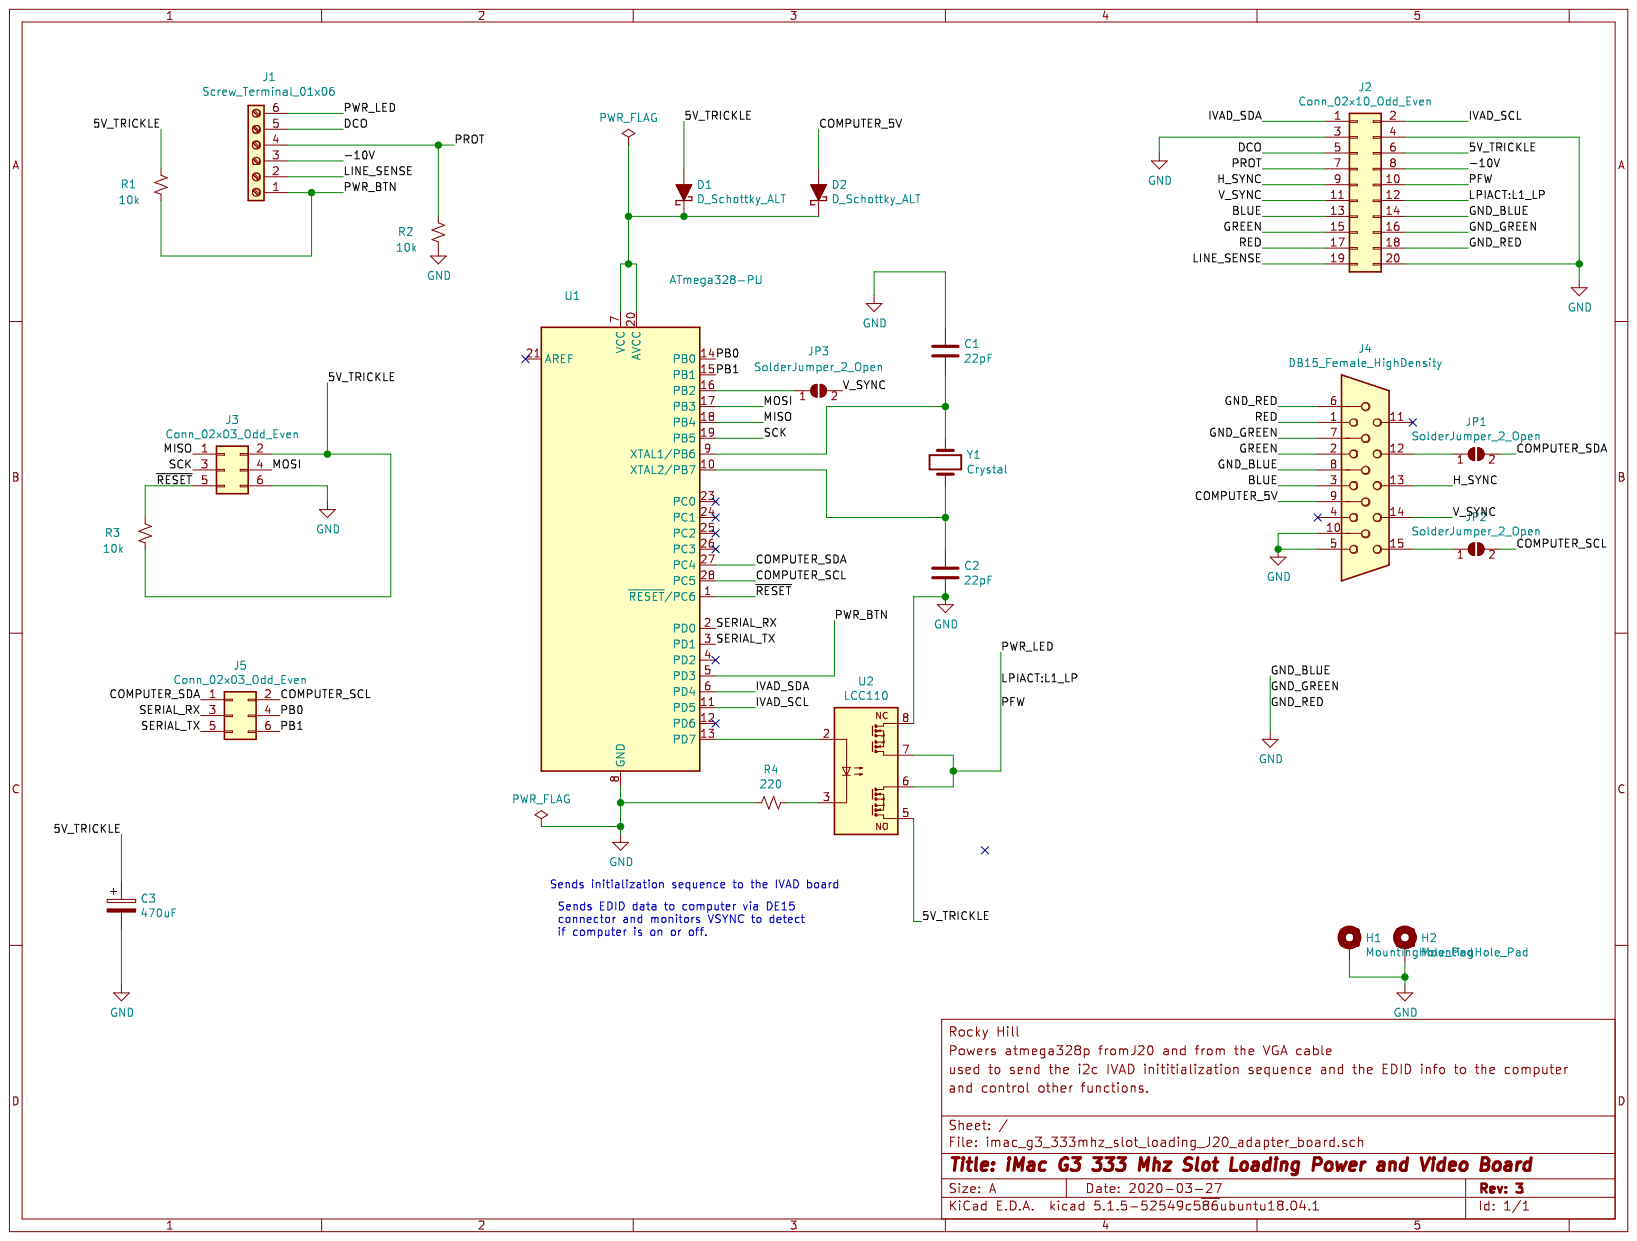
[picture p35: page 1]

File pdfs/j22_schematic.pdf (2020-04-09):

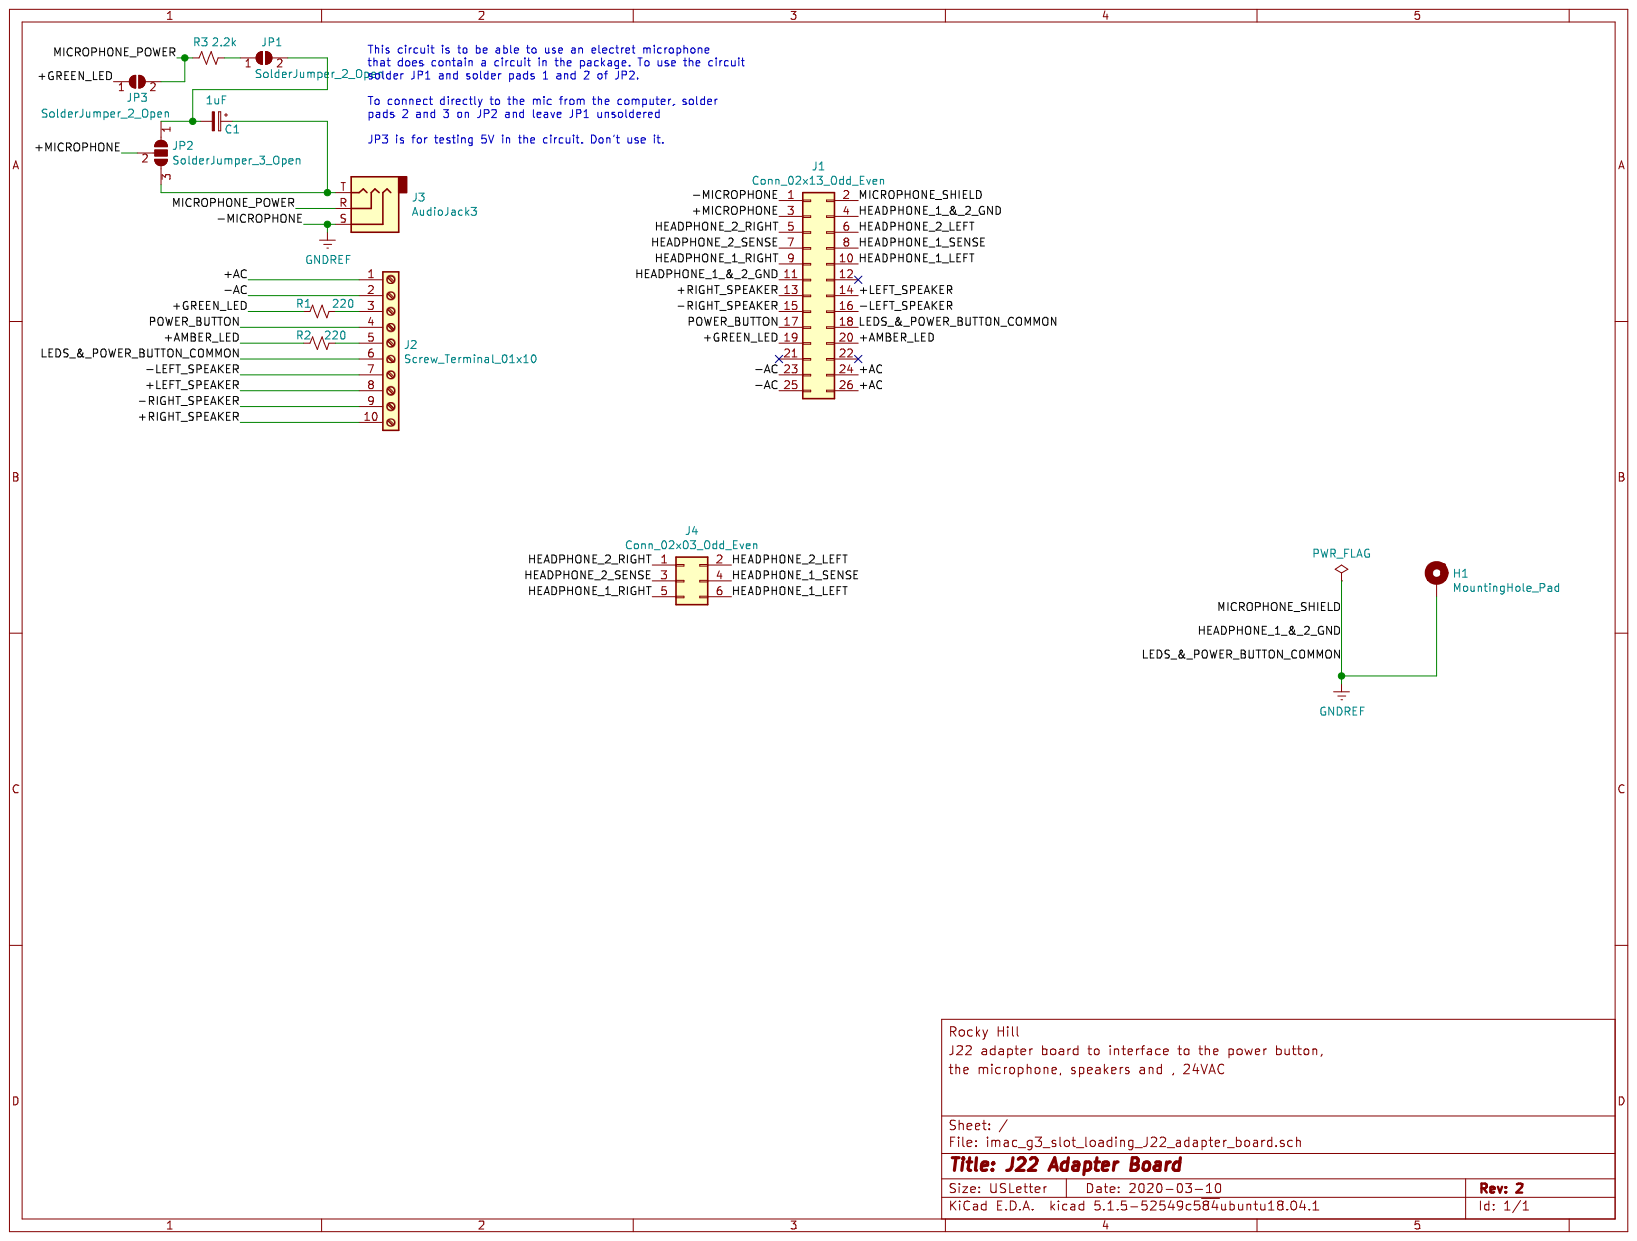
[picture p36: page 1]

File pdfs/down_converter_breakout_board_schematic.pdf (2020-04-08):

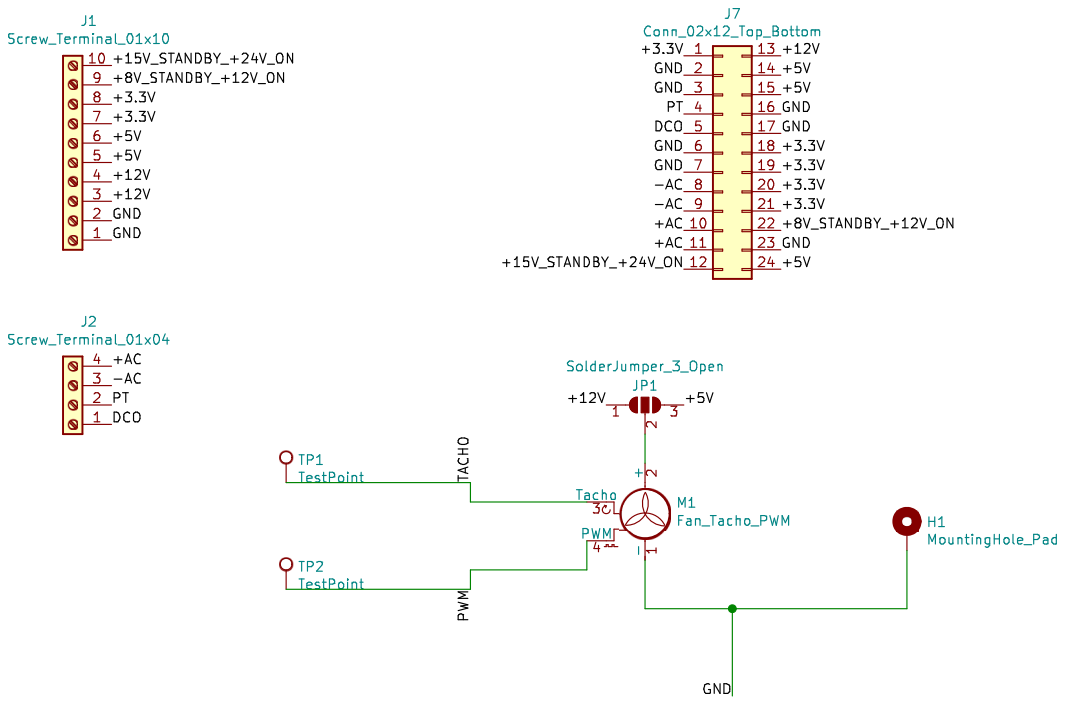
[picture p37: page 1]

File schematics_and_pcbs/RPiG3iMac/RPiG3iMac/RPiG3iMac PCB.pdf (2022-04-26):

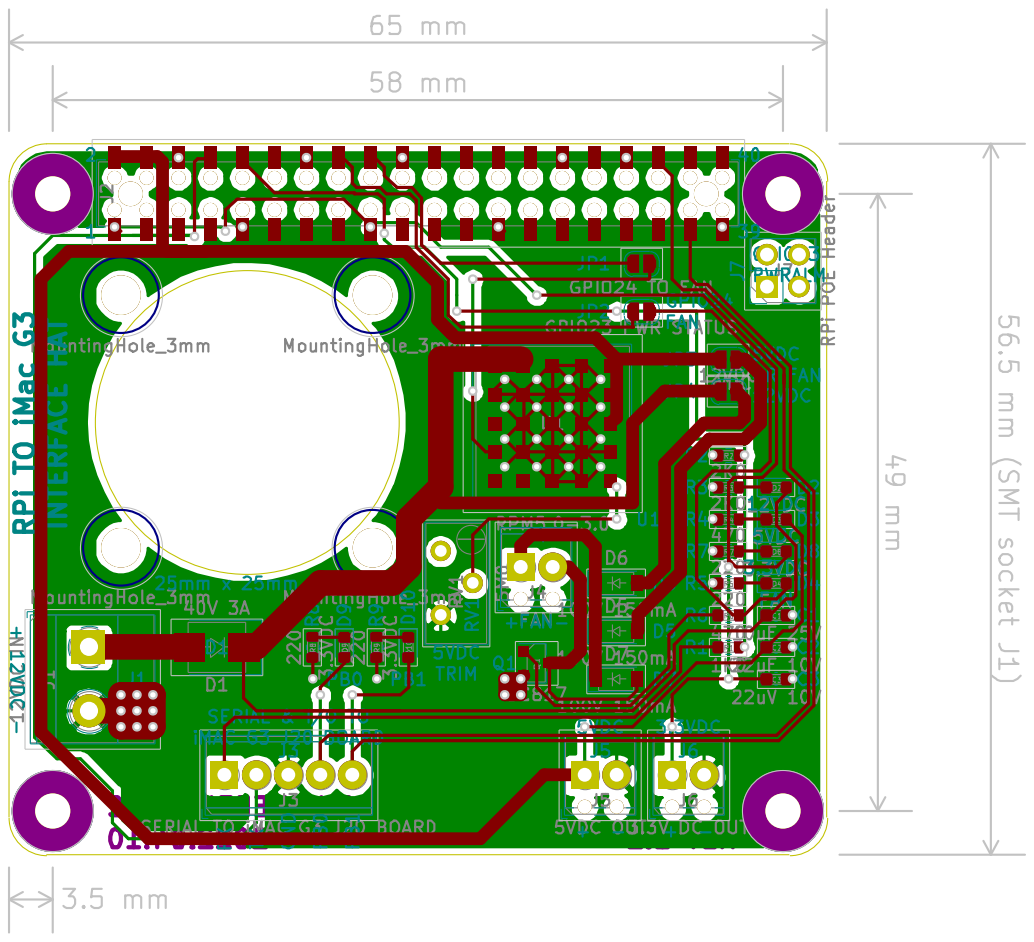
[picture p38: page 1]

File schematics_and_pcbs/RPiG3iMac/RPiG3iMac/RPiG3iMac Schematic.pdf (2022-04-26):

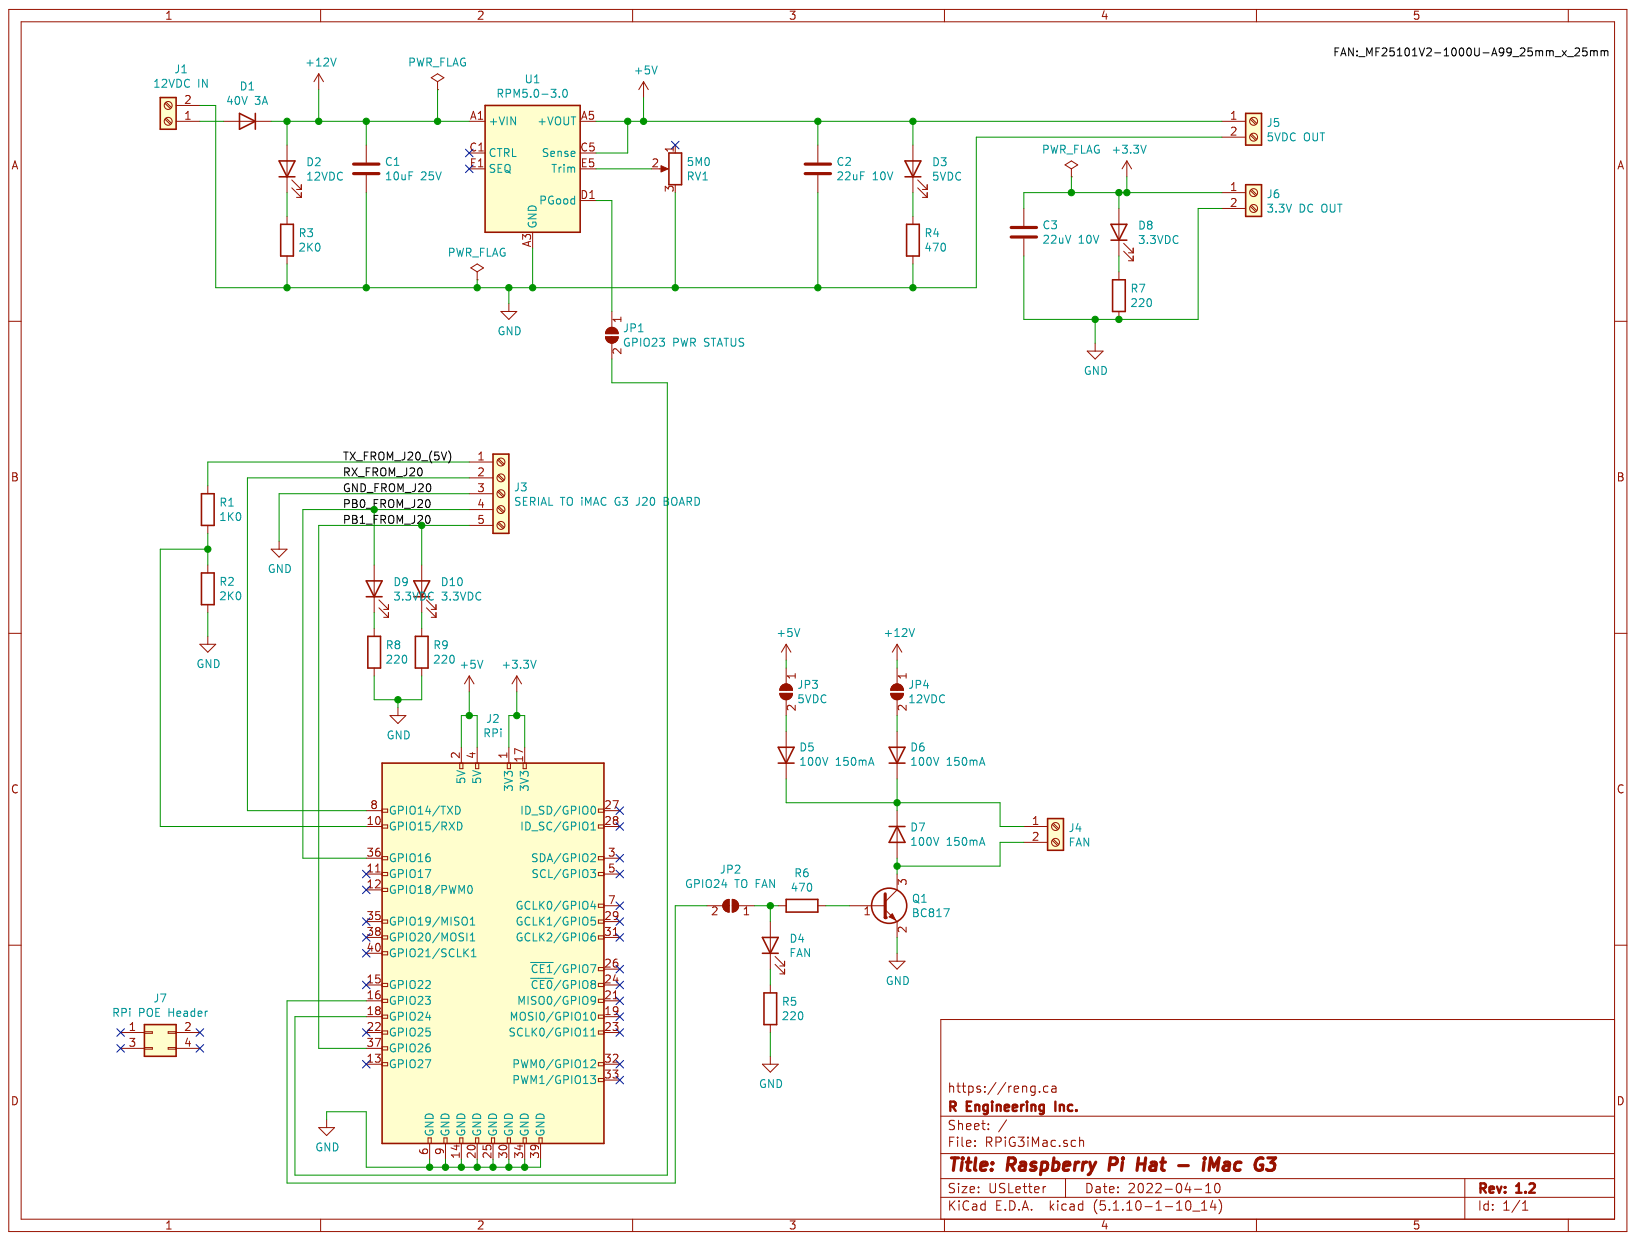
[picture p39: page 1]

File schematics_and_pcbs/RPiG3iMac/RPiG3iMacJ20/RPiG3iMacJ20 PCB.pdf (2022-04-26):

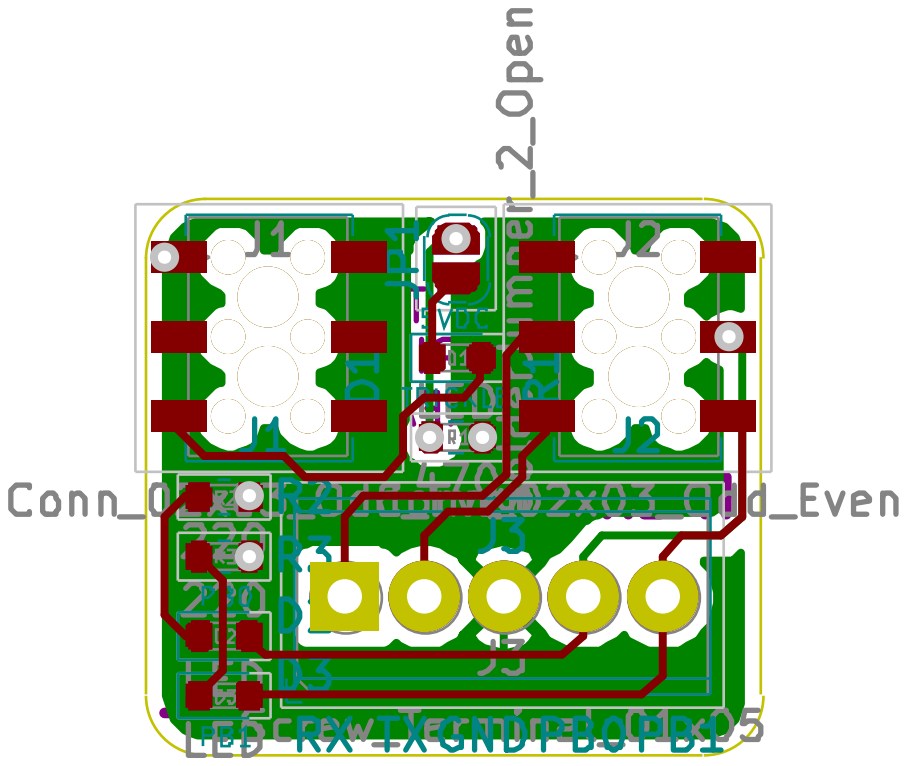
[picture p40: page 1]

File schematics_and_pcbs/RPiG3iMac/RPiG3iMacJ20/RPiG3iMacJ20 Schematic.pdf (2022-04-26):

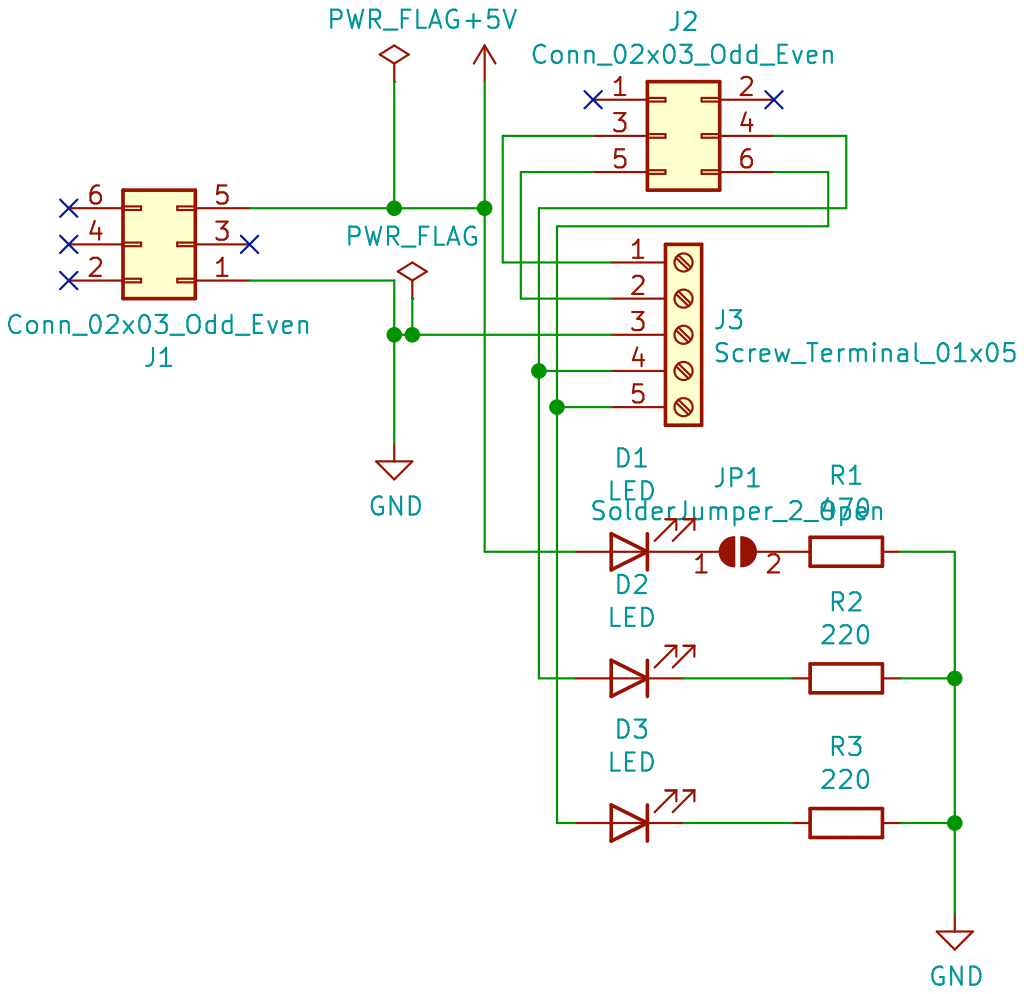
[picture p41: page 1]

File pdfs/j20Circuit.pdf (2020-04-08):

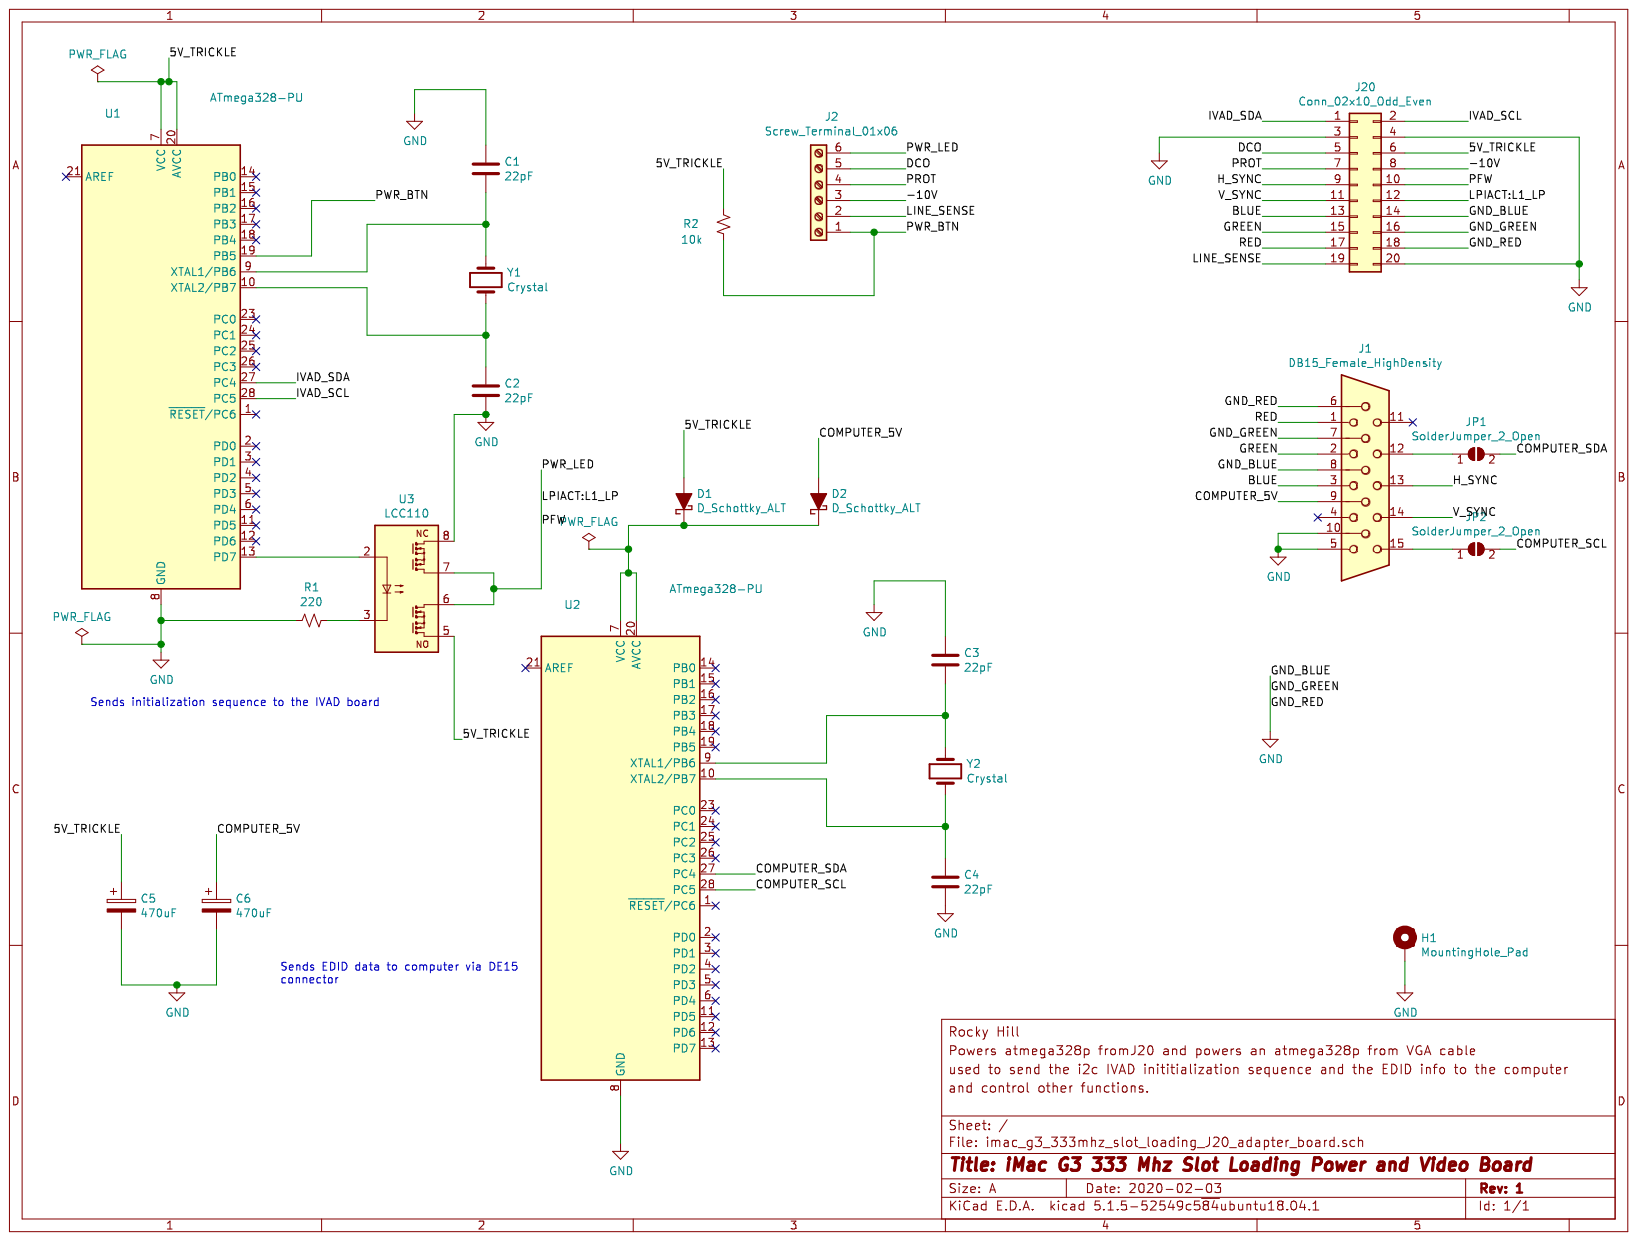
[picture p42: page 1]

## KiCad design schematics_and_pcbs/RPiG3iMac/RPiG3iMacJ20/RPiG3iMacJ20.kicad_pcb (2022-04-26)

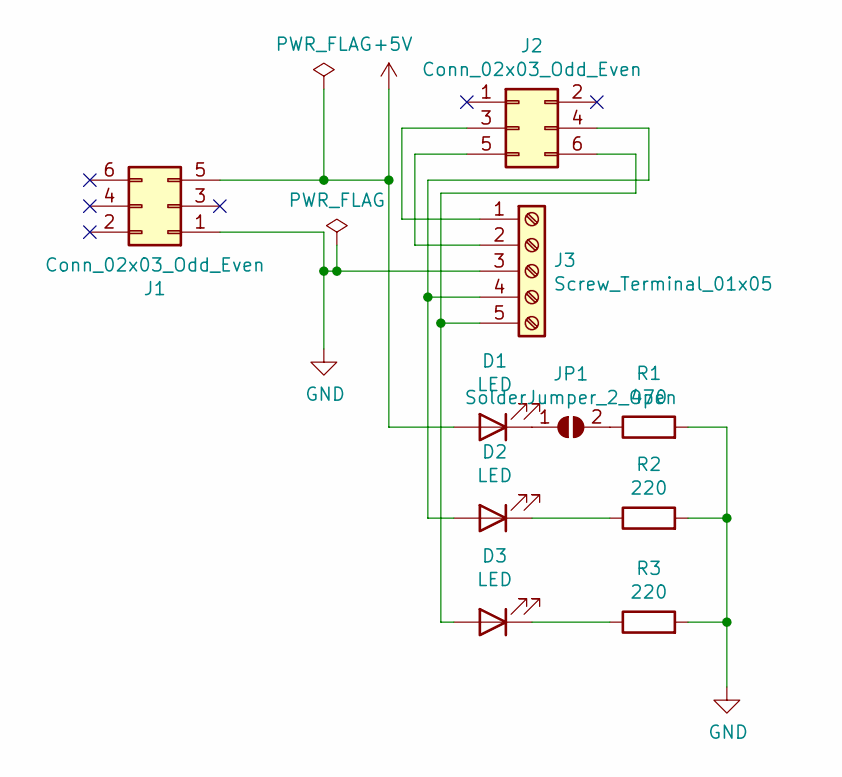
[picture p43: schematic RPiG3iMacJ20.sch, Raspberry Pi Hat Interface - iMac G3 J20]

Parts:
D1, D2, D3: LED; LED_0603_1608Metric
J1, J2: Conn_02x03_Odd_Even; Harwin_M20-7810345_2x03_P2.54mm_Vertical
J3: Screw_Terminal_01x05; TerminalBlock_Phoenix_MPT-0,5-5-2.54_1x05_P2.54mm_Horizontal
JP1: SolderJumper_2_Open; SolderJumper-2_P1.3mm_Open_RoundedPad1.0x1.5mm
R1: 470; R_0603_1608Metric
R2, R3: 220; R_0603_1608Metric

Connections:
+5V: D1.2 (A), J1.5
GND: J1.1, J3.3, R1.2, R2.2, R3.2
unnamed: D1.1 (K), JP1.1 (A)
unnamed: D2.1 (K), R2.1
unnamed: D2.2 (A), J2.4, J3.4
unnamed: D3.1 (K), R3.1
unnamed: D3.2 (A), J2.6, J3.5
unnamed: J2.3, J3.1
unnamed: J2.5, J3.2
unnamed: JP1.2 (B), R1.1

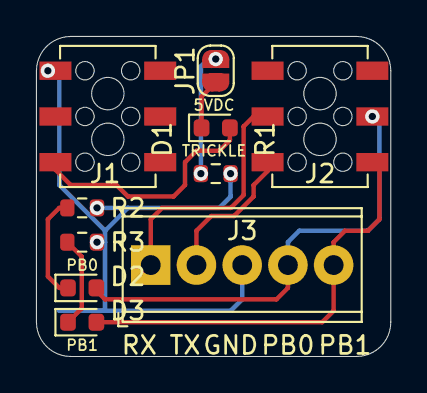
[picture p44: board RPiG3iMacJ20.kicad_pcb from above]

Board: 2 copper layers, 19.7 x 17.8 mm, 10 parts (0 on the bottom side), 10 nets.

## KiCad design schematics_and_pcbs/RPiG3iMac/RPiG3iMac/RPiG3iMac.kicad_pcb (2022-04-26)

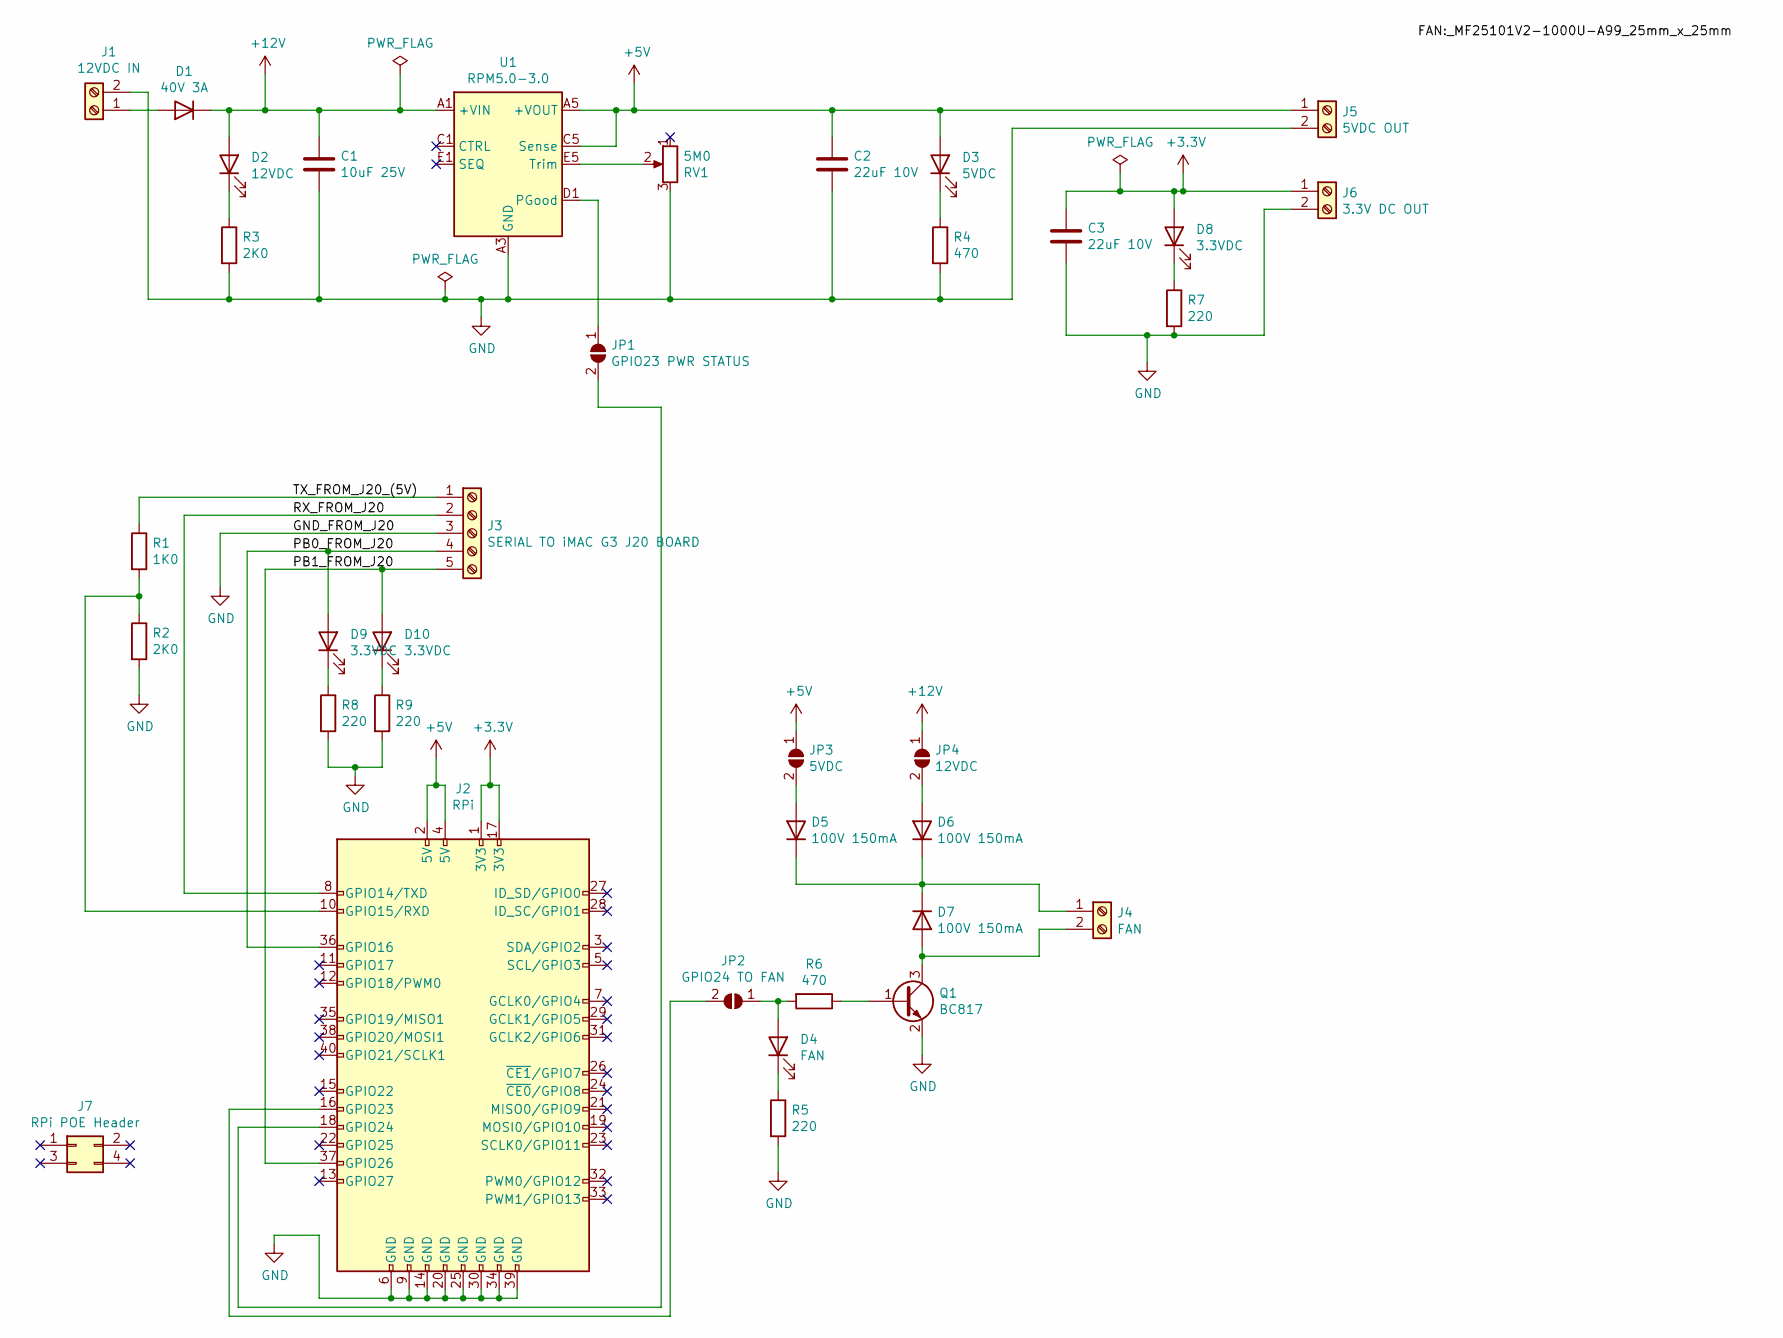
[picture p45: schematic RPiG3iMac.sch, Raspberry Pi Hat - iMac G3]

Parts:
C1: 10uF 25V; C_0603_1608Metric
C2, C3: 22uF 10V; C_0603_1608Metric
D1: 40V 3A; D_SMB
D2: 12VDC; LED_0603_1608Metric
D3: 5VDC; LED_0603_1608Metric
D4: FAN; LED_0603_1608Metric
D5, D6, D7: 100V 150mA; D_SOD-123
D8, D9, D10: 3.3VDC; LED_0603_1608Metric
J1: 12VDC IN; TerminalBlock_Phoenix_MKDS-1,5-2-5.08_1x02_P5.08mm_Horizont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
J2: RPi; Harwin_M20-7812045_2x20_P2.54mm_Vertical_rpi
J3: SERIAL TO iMAC G3 J20 BOARD; TerminalBlock_Phoenix_MPT-0,5-5-2.54_1x05_P2.54mm_Horizontal
J4: FAN; TerminalBlock_Phoenix_MPT-0,5-2-2.54_1x02_P2.54mm_Horizontal
J5: 5VDC OUT; TerminalBlock_Phoenix_MPT-0,5-2-2.54_1x02_P2.54mm_Horizontal
J6: 3.3V DC OUT; TerminalBlock_Phoenix_MPT-0,5-2-2.54_1x02_P2.54mm_Horizontal
J7: RPi POE Header; PinHeader_2x02_P2.54mm_Vertical
JP1: GPIO23 PWR STATUS; SolderJumper-2_P1.3mm_Open_RoundedPad1.0x1.5mm
JP2: GPIO24 TO FAN; SolderJumper-2_P1.3mm_Open_RoundedPad1.0x1.5mm
JP3: 5VDC; SolderJumper-2_P1.3mm_Open_RoundedPad1.0x1.5mm
JP4: 12VDC; SolderJumper-2_P1.3mm_Open_RoundedPad1.0x1.5mm
Q1: BC817; SOT-23
R1: 1K0; R_0603_1608Metric
R2, R3: 2K0; R_0603_1608Metric
R4, R6: 470; R_0603_1608Metric
R5, R7, R8, R9: 220; R_0603_1608Metric
RV1: 5M0; Potentiometer_Bourns_3296Y_Vertical
U1: RPM5.0-3.0; Converter_DCDC_RECOM_RPMx.x-x.0

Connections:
+3V3: C3.1, D8.2 (A), J2.1 (3V3), J2.17 (3V3), J6.1
+5V: C2.1, D3.2 (A), J2.2 (5V), J2.4 (5V), J5.1, JP3.1 (A), U1.A5 (+VOUT), U1.B5 (+VOUT), U1.C5 (Sense)
+12V: C1.1, D1.1 (K), D2.2 (A), JP4.1 (A), U1.A1 (+VIN), U1.A2 (+VIN)
/PB0_FROM_J20: D9.2 (A), J2.36 (GPIO16), J3.4
/PB1_FROM_J20: D10.2 (A), J2.37 (GPIO26), J3.5
/RX_FROM_J20: J2.8 (GPIO14/TXD), J3.2
/TX_FROM_J20_(5V): J3.1, R1.1
GND: C1.2, C2.2, C3.2, J1.2, J2.6 (GND), J2.9 (GND), J2.14 (GND), J2.20 (GND), J2.25 (GND), J2.30 (GND), J2.34 (GND), J2.39 (GND), J3.3, J5.2, J6.2, Q1.2 (E), R2.2, R3.2, R4.2, R5.2, R7.2, R8.2, R9.2, RV1.3, U1.A3 (GND), U1.A4 (GND), U1.B1 (GND), U1.B2 (GND), U1.B3 (GND), U1.B4 (GND), U1.C2 (GND), U1.C3 (GND), U1.C4 (GND), U1.D2 (GND), U1.D3 (GND), U1.D4 (GND), U1.D5 (GND), U1.E3 (GND), U1.E4 (GND)
unnamed: D1.2 (A), J1.1
unnamed: D2.1 (K), R3.1
unnamed: D3.1 (K), R4.1
unnamed: D4.1 (K), R5.1
unnamed: D4.2 (A), JP2.1 (A), R6.2
unnamed: D5.1 (K), D6.1 (K), D7.1 (K), J4.1
unnamed: D5.2 (A), JP3.2 (B)
unnamed: D6.2 (A), JP4.2 (B)
unnamed: D7.2 (A), J4.2, Q1.3 (C)
unnamed: D8.1 (K), R7.1
unnamed: D9.1 (K), R8.1
unnamed: D10.1 (K), R9.1
unnamed: J2.10 (GPIO15/RXD), R1.2, R2.1
unnamed: J2.16 (GPIO23), JP2.2 (B)
unnamed: J2.18 (GPIO24), JP1.2 (B)
unnamed: JP1.1 (A), U1.D1 (PGood)
unnamed: Q1.1 (B), R6.1
unnamed: RV1.2, U1.E5 (Trim)

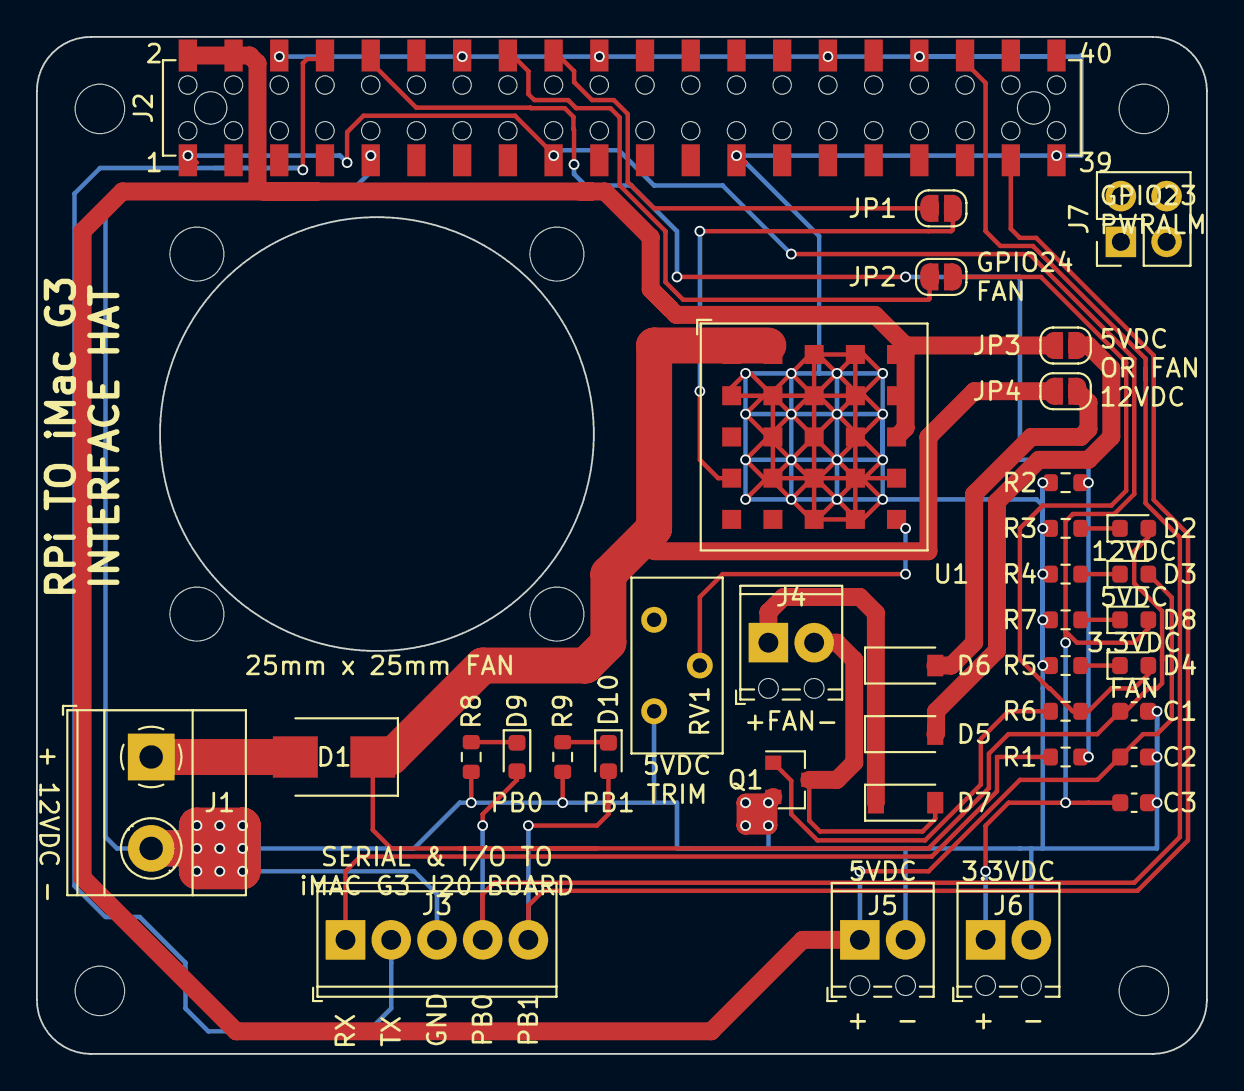
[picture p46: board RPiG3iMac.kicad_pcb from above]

Board: 2 copper layers, 65.0 x 56.5 mm, 40 parts (0 on the bottom side), 26 nets.

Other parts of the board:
 : MountingHole_3mm
 #2,  #3,  #4: MountingHole_3mm

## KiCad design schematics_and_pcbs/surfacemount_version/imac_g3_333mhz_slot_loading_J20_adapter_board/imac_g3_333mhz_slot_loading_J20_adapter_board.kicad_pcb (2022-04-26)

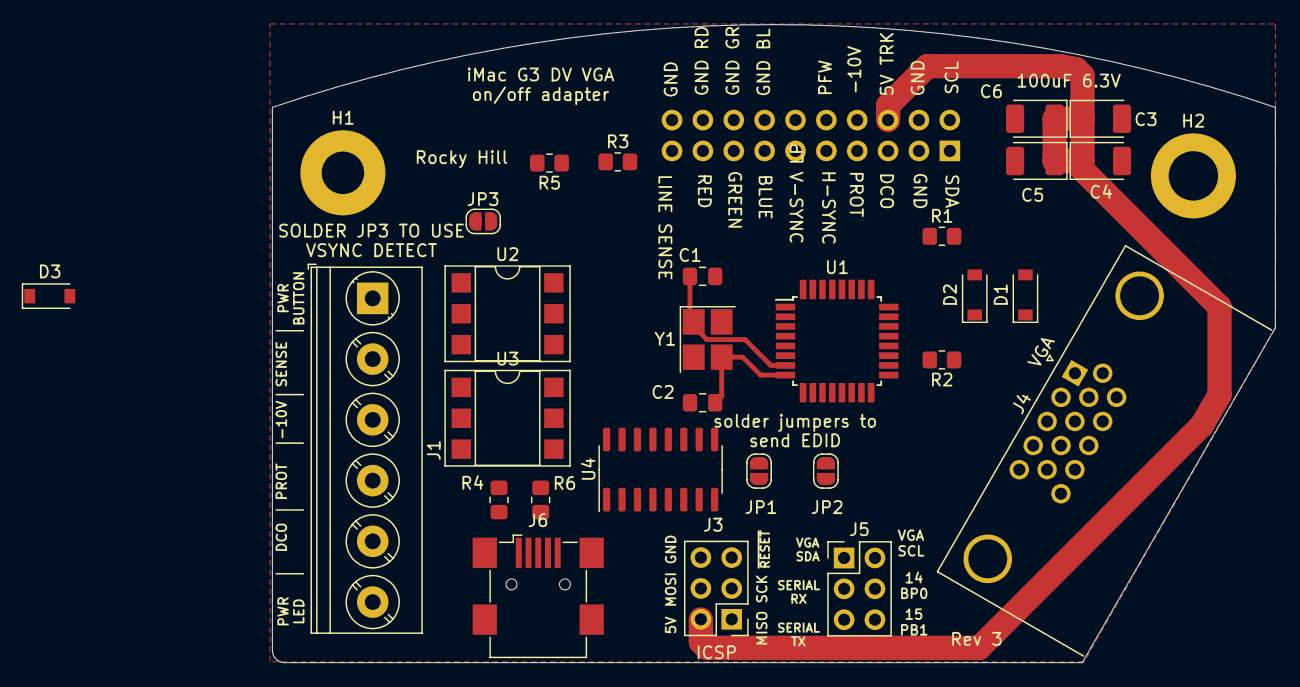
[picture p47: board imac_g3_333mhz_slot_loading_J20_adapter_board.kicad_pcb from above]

Board: 2 copper layers, 82.5 x 52.5 mm, 31 parts (1 on the bottom side), 38 nets.

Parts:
C1, C2: 22pF; C_0805_2012Metric_Pad1.18x1.45mm_HandSolder
C3, C4, C5, C6: 100uF 6.3V; CP_EIA-3528-21_Kemet-B_Pad1.50x2.35mm_HandSolder
D1, D2, D3: D_Schottky_ALT; D_SOD-123
H1, H2: MountingHole_Pad; MountingHole_3.5mm_Pad
J1: Screw_Terminal_01x06; TerminalBlock_Phoenix_PT-1,5-6-5.0-H_1x06_P5.00mm_Horizontal
J2: Conn_02x10_Odd_Even; PinHeader_2x10_P2.54mm_Vertical
J3, J5: Conn_02x03_Odd_Even; PinHeader_2x03_P2.54mm_Vertical
J4: DB15_Female_HighDensity; DSUB-15-HD_Female_Horizontal_P2.29x1.98mm_EdgePinOffset8.35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
J6: USB_B_Micro; USB_Mini-B_Wuerth_65100516121_Horizontal
JP1, JP2, JP3: SolderJumper_2_Open; SolderJumper-2_P1.3mm_Open_RoundedPad1.0x1.5mm
R1, R2, R3, R6: 10k; R_0805_2012Metric_Pad1.20x1.40mm_HandSolder
R4, R5: 220; R_0805_2012Metric_Pad1.20x1.40mm_HandSolder
U1: ATmega328P-AU; TQFP-32_7x7mm_P0.8mm
U2, U3: CPC1972GSTR; DIP-6_W7.62mm_SMDSocket_SmallPads
U4: CH340G; SOIC-16_3.9x9.9mm_P1.27mm
Y1: 16 Mz cystal; Crystal_SMD_3225-4Pin_3.2x2.5mm_HandSoldering

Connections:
/5V_TRICKLE: C3.1, C4.1, C5.1, C6.1, D1.2, J2.6, J3.2, R1.2, R3.1, R5.1, U3.4
/5V_USB: D3.2, J6.1, U4.16
/-10V: J1.3, J2.8
/BLUE: J2.13, J4.3
/COMPUTER_5V: D2.2, J4.9
/COMPUTER_SCL: J5.2, JP2.2, U1.28
/COMPUTER_SDA: J5.1, JP1.2, U1.27
/DCO: J1.5, J2.5
/GREEN: J2.15, J4.2
/H_SYNC: J2.9, J4.13
/IVAD_SCL: J2.2, U1.9
/IVAD_SDA: J2.1, U1.2
/LINE_SENSE: J1.2, J2.19
/LPIACT:L1_LP: J1.6, J2.10, J2.12, U2.4, U3.6
/MISO: J3.1, U1.16
/MOSI: J3.4, U1.15
/PB0: J5.4, U1.12
/PB1: J5.6, U1.13
/PROT: J1.4, J2.7, R2.2
/PWR_BTN: J1.1, R1.1, U1.1
/RED: J2.17, J4.1
/SCK: J3.3, U1.17
/SERIAL_RX: J5.3, U1.30, U4.2
/SERIAL_TX: J5.5, U1.31, U4.3
/V_SYNC: J2.11, J4.14, JP3.2
/~RESET: J3.5, R3.2, U1.29
GND: C1.1, C2.2, C3.2, C4.2, C5.2, C6.2, H1.1, H2.1, J2.3, J2.4, J2.14, J2.16, J2.18, J2.20, J3.6, J4.5, J4.6, J4.7, J4.8, J4.10, J6.5, J6.6, R2.1, R4.1, R6.1, U1.3, U1.5, U1.21, U2.6, U4.1, Y1.2, Y1.4
unnamed: C1.2, U1.7, Y1.1
unnamed: C2.1, U1.8, Y1.3
unnamed: D1.1, D2.1, D3.1, U1.4, U1.6, U1.18
unnamed: J4.12, JP1.1
unnamed: J4.15, JP2.1
unnamed: J6.2, U4.6
unnamed: J6.3, U4.5
unnamed: JP3.1, U1.14
unnamed: R4.2, U3.2
unnamed: R5.2, U2.1
unnamed: R6.2, U1.11, U2.2, U3.1

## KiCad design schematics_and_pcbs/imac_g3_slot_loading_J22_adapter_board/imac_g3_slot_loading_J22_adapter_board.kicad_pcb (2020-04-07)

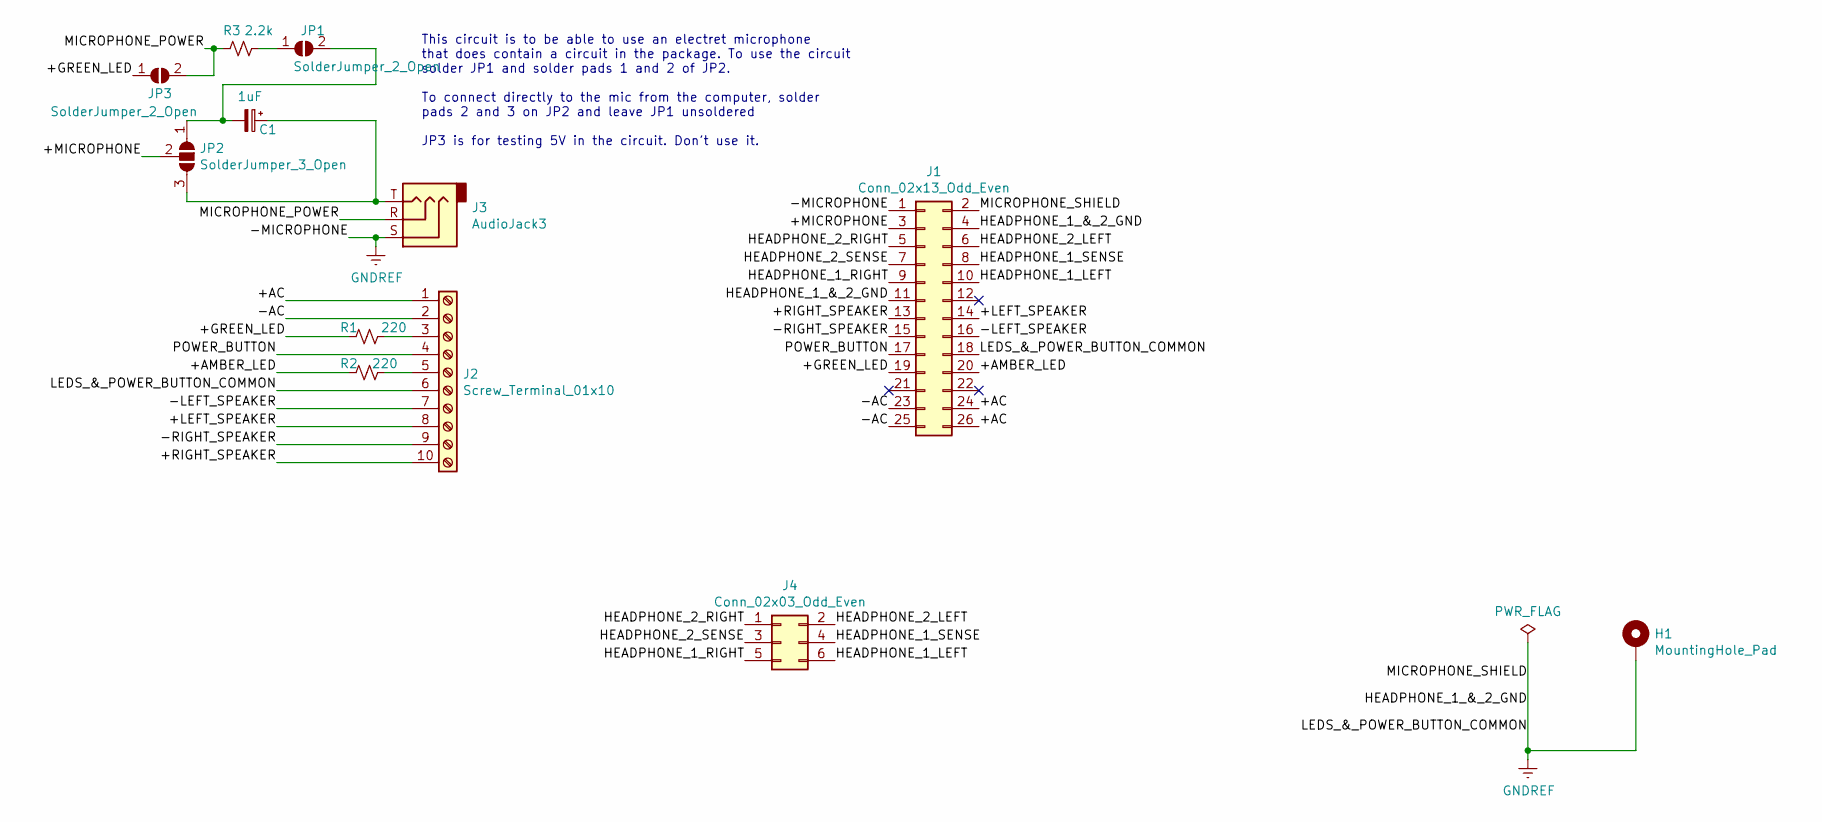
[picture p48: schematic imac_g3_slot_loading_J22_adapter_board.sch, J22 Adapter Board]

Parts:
C1: 1uF; CP_Radial_D4.0mm_P1.50mm; Part# 493-14556-1-ND
H1: MountingHole_Pad; MountingHole_3.5mm_Pad
J1: Conn_02x13_Odd_Even; PinHeader_2x13_P2.54mm_Vertical; Part# 609-3367-ND
J2: Screw_Terminal_01x10; TerminalBlock_Phoenix_PT-1,5-10-5.0-H_1x10_P5.00mm_Horizont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; Part# 277-9080-ND
J3: AudioJack3; Jack_3.5mm_CUI_SJ1-3533NG_Horizontal_CircularHoles; Part# CP1-3533NG-ND
J4: Conn_02x03_Odd_Even; PinHeader_2x03_P2.54mm_Vertical; Part# 609-3234-ND
JP1, JP3: SolderJumper_2_Open; SolderJumper-2_P1.3mm_Open_RoundedPad1.0x1.5mm
JP2: SolderJumper_3_Open; SolderJumper-3_P1.3mm_Open_RoundedPad1.0x1.5mm
R1, R2: 220; R_Axial_DIN0207_L6.3mm_D2.5mm_P7.62mm_Horizontal; Part# CF14JT220RCT-ND
R3: 2.2k; R_Axial_DIN0207_L6.3mm_D2.5mm_P7.62mm_Horizontal; Part# CF14JT2K20CT-ND

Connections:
/+AC: J1.24, J1.26, J2.1
/+AMBER_LED: J1.20, R2.2
/+GREEN_LED: J1.19, JP3.1 (A), R1.2
/+LEFT_SPEAKER: J1.14, J2.8
/+MICROPHONE: J1.3, JP2.2 (C)
/+RIGHT_SPEAKER: J1.13, J2.10
/-AC: J1.23, J1.25, J2.2
/-LEFT_SPEAKER: J1.16, J2.7
/-RIGHT_SPEAKER: J1.15, J2.9
/HEADPHONE_1_LEFT: J1.10, J4.6
/HEADPHONE_1_RIGHT: J1.9, J4.5
/HEADPHONE_1_SENSE: J1.8, J4.4
/HEADPHONE_2_LEFT: J1.6, J4.2
/HEADPHONE_2_RIGHT: J1.5, J4.1
/HEADPHONE_2_SENSE: J1.7, J4.3
/MICROPHONE_POWER: J3.R, JP3.2 (B), R3.2
/POWER_BUTTON: J1.17, J2.4
GNDREF: H1.1, J1.1, J1.2, J1.4, J1.11, J1.18, J2.6, J3.S
unnamed: C1.1, J3.T, JP2.3 (B)
unnamed: C1.2, JP1.2 (B), JP2.1 (A)
unnamed: J2.3, R1.1
unnamed: J2.5, R2.1
unnamed: JP1.1 (A), R3.1

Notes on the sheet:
This circuit is to be able to use an electret microphone that does contain a circuit in the package. To use the circuit solder JP1 and solder pads 1 and 2 of JP2. To connect directly to the mic from the computer, solder pads 2 and 3 on JP2 and leave JP1 unsoldered JP3 is for testing 5V in the circu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

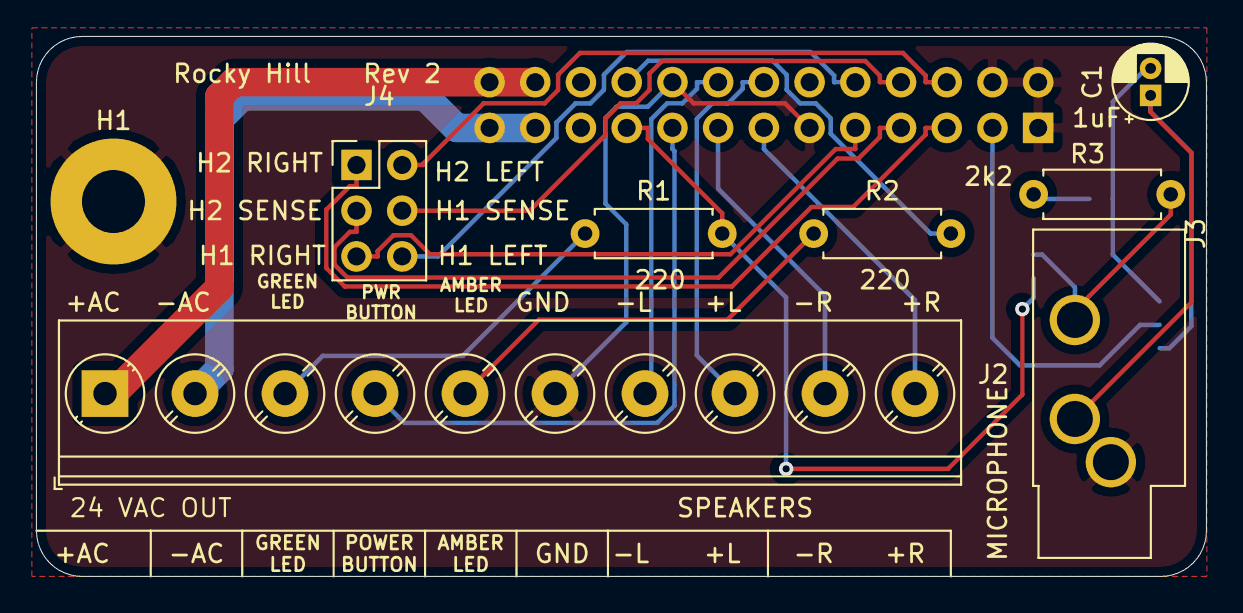
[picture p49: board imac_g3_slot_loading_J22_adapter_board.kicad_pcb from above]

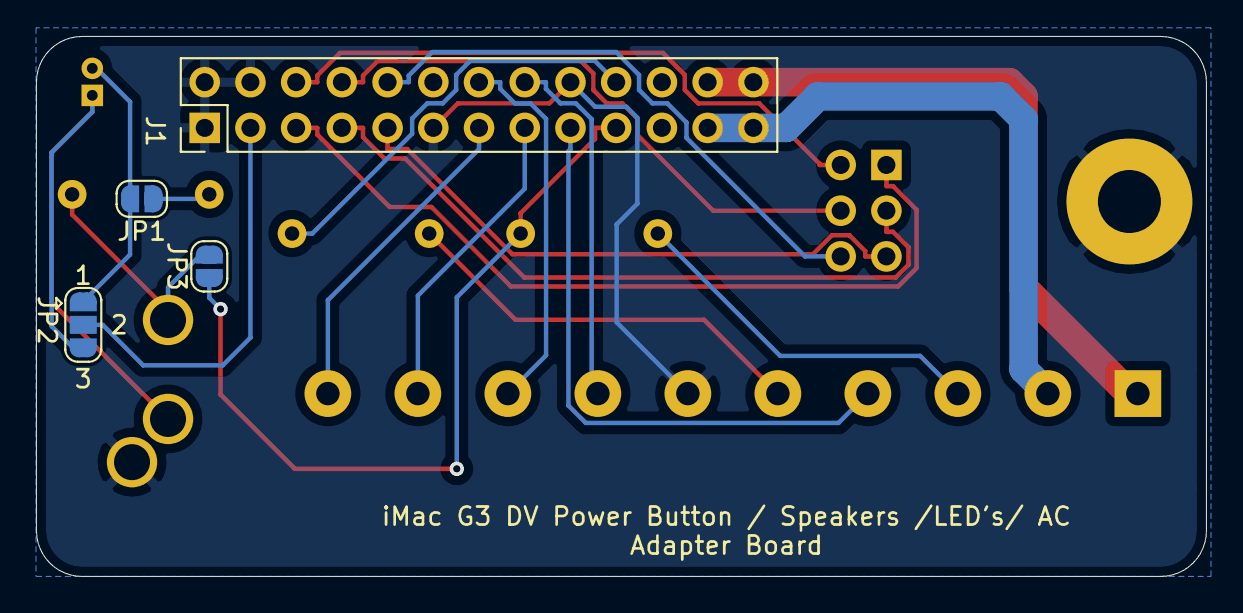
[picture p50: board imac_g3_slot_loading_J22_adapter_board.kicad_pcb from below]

Board: 2 copper layers, 65.0 x 30.0 mm, 12 parts (4 on the bottom side), 23 nets.

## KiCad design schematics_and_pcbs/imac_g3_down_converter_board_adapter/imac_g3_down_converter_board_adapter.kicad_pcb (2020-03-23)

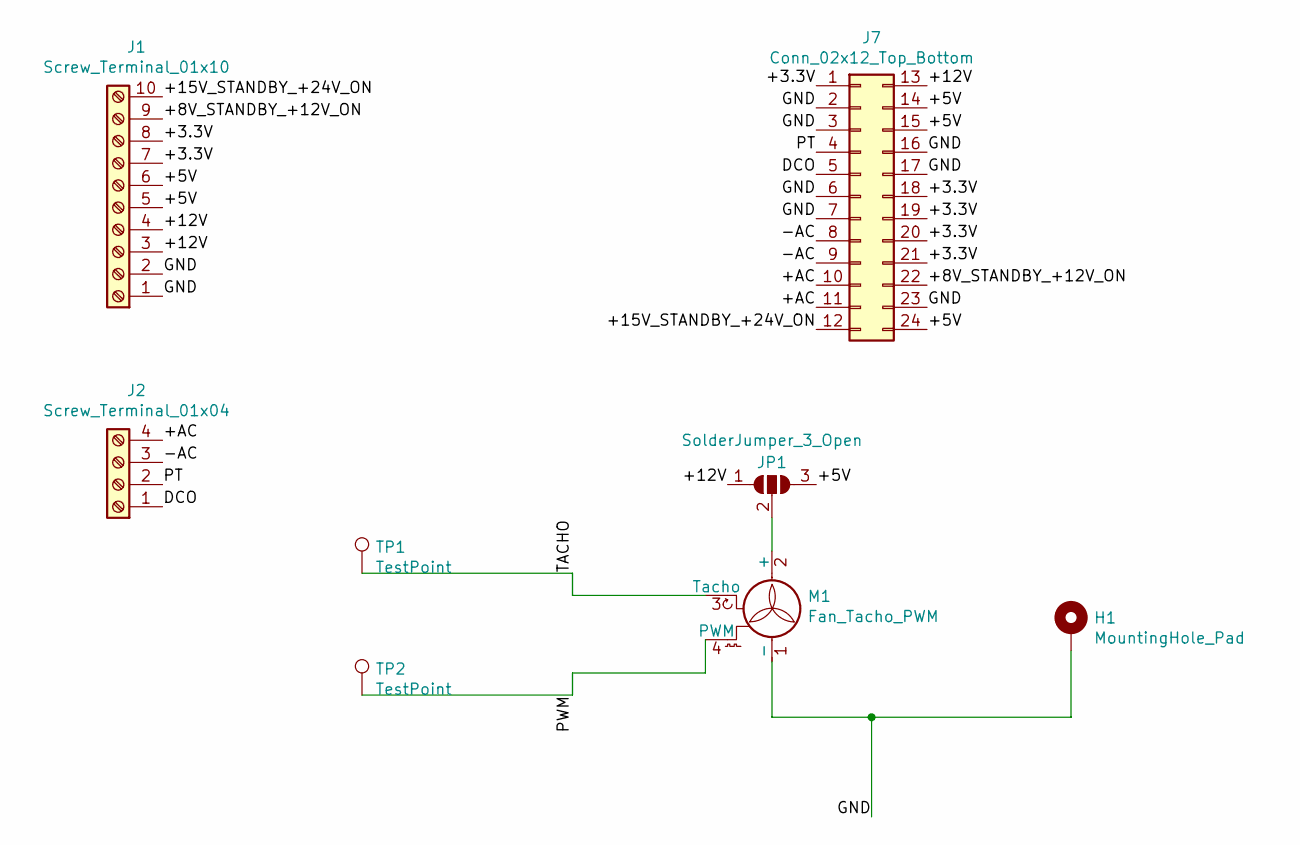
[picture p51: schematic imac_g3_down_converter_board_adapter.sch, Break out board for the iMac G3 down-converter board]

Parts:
H1: MountingHole_Pad; MountingHole_3.2mm_M3_Pad_Via
J1: Screw_Terminal_01x10; TerminalBlock_Phoenix_PT-1,5-10-5.0-H_1x10_P5.00mm_Horizont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; Part# 277-9080-ND
J2: Screw_Terminal_01x04; TerminalBlock_Phoenix_PT-1,5-4-5.0-H_1x04_P5.00mm_Horizontal; Part# 277-1579-ND
J7: Conn_02x12_Top_Bottom; Molex_Micro-Fit_3.0_43045-2400_2x12_P3.00mm_Horizontal; Part# WM4728-ND
JP1: SolderJumper_3_Open; SolderJumper-3_P1.3mm_Open_RoundedPad1.0x1.5mm
M1: Fan_Tacho_PWM; FanPinHeader_1x04_P2.54mm_Vertical; Part# WM4330-ND
TP1, TP2: TestPoint; TestPoint_Plated_Hole_D2.0mm

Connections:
/+3.3V: J1.7, J1.8, J7.1, J7.18, J7.19, J7.20, J7.21
/+5V: J1.5, J1.6, J7.14, J7.15, J7.24, JP1.3 (B)
/+8V_STANDBY_+12V_ON: J1.9, J7.22
/+12V: J1.3, J1.4, J7.13, JP1.1 (A)
/+15V_STANDBY_+24V_ON: J1.10, J7.12
/+AC: J2.4, J7.10, J7.11
/-AC: J2.3, J7.8, J7.9
/DCO: J2.1, J7.5
/GND: H1.1, J1.1, J1.2, J7.2, J7.3, J7.6, J7.7, J7.16, J7.17, J7.23, M1.1 (-)
/PT: J2.2, J7.4
/PWM: M1.4 (PWM), TP2.1
/TACHO: M1.3 (Tacho), TP1.1
unnamed: JP1.2 (C), M1.2 (+)

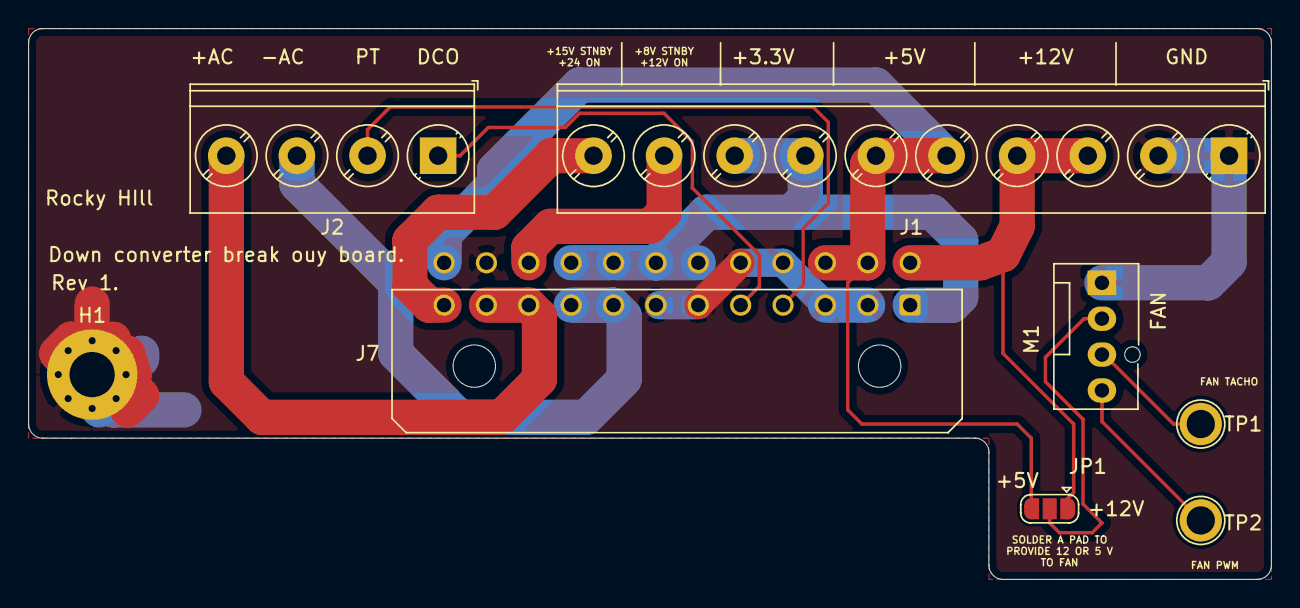
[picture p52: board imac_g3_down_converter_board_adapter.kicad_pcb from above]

Board: 2 copper layers, 88.0 x 39.0 mm, 8 parts (0 on the bottom side), 13 nets.

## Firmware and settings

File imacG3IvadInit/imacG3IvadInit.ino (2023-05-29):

//Rocky Hill


/*
   This sketch waits for button presses to turn on/off the iMac G3 CRT
   circuitry and send the init sequence to the IVAD board.
   if you are planning to just send the init sequence on startup, you
   can uncomment "initIvadBoard();"  in setup(). It uses software i2c
   lines.

   it also sends edid information when requested via i2c on port 0x50.
   The Edid information is for an iMac G3 DV and it sends the three
   supported modes.

   1024x768 @ 75 Hz
   800x600 @ 95 Hz
   640x480 @ 117 Hz

   In order for this program to work, the i2c transmit buffer length
   constants must be changed in two files. The Wire library has two
   buffers it uses for i2c transmissions

   "BUFFER_LENGTH" in
   "arduino_install_folder/hardware/arduino/avr/libraries/Wire/src/Wire.h"

   and

   "TWI_BUFFER_LENGTH" in
   "arduino_install_folder/hardware/arduino/avr/libraries/Wire/src/utility/twi.h"

   Both of these must be changed from 32 to 128 to be able to transmit
   the edid byte array in one shot.

   To test this program, you can directly wire SDA(pin 12),SCL(pin 15)
   and GND(pin 6) pins from your computers VGA portbdirectly into the
   corresponding pins on the arduino.


*/


/*
  Uses SoftwareWire from the arduino libraries. install with library
  manager or from https://github.com/Testato/SoftwareWire
*/

#include "ivad.h"
#include "imacG3IvadInit.h"
#include <EEPROMWearLevel.h>
#include <SoftwareWire.h>
#include <Wire.h>


//starting monitor property values.
byte verticalPositionValueIndex = 0x4d;//77
byte contrastValueIndex = 0xfe;
byte horizontalPositionValueIndex = 0xb0;//176
byte heightValueIndex = 0xf0;//240
byte widthValueIndex = 0x19;//25
byte brightnessValueIndex = 0x0a;
byte parallelogramValueIndex = 0xc6;//198
byte keystoneValueIndex = 0x9b;//155
byte rotationValueIndex = 0x42;//66
byte pincushionValueIndex = 0xcb;//203

byte SERIAL_BUFFER[SERIAL_BUFFER_MAX_SIZE];
byte SERIAL_BUFFER_DATA_SIZE;
byte CURRENT_CONFIG[CONFIG_EEPROM_SLOTS];
byte FIRST_RUN = 0x79;

byte data = -1;

//define solid state relay and power button pins
byte solid_state_relay_Pin = 7;

byte powerButtonPin = 3;
//int powerButtonPin = 13;

//define state variables
byte externalCircuitState = LOW;
byte buttonState = LOW;

//vsync pin
byte vsyncPin = 10;


//vsync power off countdown in seconds
byte vsync_off_time = 180;

//counters
byte buttonPressedTime = 0;
byte vsyncDetect = 0;
unsigned long currentTime = 0;
unsigned long startTime = 0;
unsigned long elapsedTime = 0;

//The init sequence is sent on a software i2c bus.
// sda is on 4 and scl is on 5
SoftwareWire softWire( 4, 5);




void setup() {

  //define pin direction
  pinMode(solid_state_relay_Pin, OUTPUT);
  pinMode(powerButtonPin, INPUT);
  pinMode(vsyncPin, INPUT);//this pin is used to monitor VSYNC.
  pinMode(8, INPUT);//this pin is on the J5 connector for general use PB0.
  pinMode(9, INPUT);//this pin is on the J5 connector for general use PB1.

  EEPROMwl.begin(CONFIG_EEPROM_VERSION, CONFIG_EEPROM_SLOTS + 1);
  Wire.begin(0x50); //join as slave and wait for EDID requests
  softWire.begin();// join as master and send init sequence
  Serial.begin(115200);//use built in serial
  Serial.setTimeout(1000);

  Wire.onRequest(requestEvent); //event handler for requests from master
  Wire.onReceive(receiveData); // event handler when receiving from  master
  // turn it all off
  externalCircuitOff();

  //check to see if it's the 1st time running after burning firmware
  FIRST_RUN = EEPROMwl.read(CONFIG_EEPROM_SLOTS);
  if (FIRST_RUN != 0x79 ) {
    EEPROMwl.update(CONFIG_EEPROM_SLOTS, 0x79);
    settings_reset_default();
    settings_store();
    settings_load();
    ivad_write_settings();
  }//end if


  //externalCircuitOn();


}//end setup

//byte x = 0;
/*
   This loops looks for button presses, turns the circuit on or off, and
   listens for characters on the serial port to make screen adjustments.
*/
void loop() {

  buttonState = digitalRead(powerButtonPin);

  // do stuff only when the CRT is on
  if ( externalCircuitState == HIGH ) {

    currentTime = millis();
    elapsedTime = currentTime - startTime;


    serial_processing();


    //increment vsyncDetect everytime vsync is detected
    if (pulseIn(vsyncPin, HIGH, 10000) > 0) {

      if (vsyncDetect < vsync_off_time) {
        vsyncDetect++;
      }//end if
      startTime = currentTime = millis();
    }//end if


    //decrement vsyncDetect whenever one second elapses
    if (elapsedTime >= 1000 && vsyncDetect > 0) {
      vsyncDetect--;
      startTime = currentTime = millis();
    }

    //do stuff whn vsyncDetect is 0
    if (vsyncDetect <= 0) {
      startTime = 0;
      currentTime = 0;
       externalCircuitOff();


    }

  }//end if


  if (buttonState == LOW )
  {
    if (buttonPressedTime <= 10) {
      buttonPressedTime++;
    }//end if



  }
  else
  {
    //buttonPressedTime = 0;

  }

  //turn everything off if button is pressed for 10 ms
  if (buttonPressedTime > 0 && externalCircuitState == HIGH && buttonState == HIGH) {
    externalCircuitOff();
    buttonPressedTime = 0;

  }

  //turn everything on if button is pressed for 10 ms
  if (buttonPressedTime > 0 && externalCircuitState == LOW  && buttonState == HIGH) {
    externalCircuitOn();
    buttonPressedTime = 0;
    startTime = millis();
    currentTime = millis();
    vsyncDetect = vsync_off_time;

  }




}//end loop



void handleSerial(char incoming) {
  /*
     a = move left
     s = move right
     w = move up
     z = move down

     d = skinnier
     f = fatter
     r = taller
     c = shorter

     g = contrast down
     h = contrast up

     j = brightness down
     k = brightness up


  */


  //if (Serial.available() > 0) {
  // char incoming = Serial.read();

  int index = -1;
  bool increment = true;
  switch (incoming) {
    case 'a'://move left
      //moveHorizontal(+1);
      index = IVAD_SETTING_HORIZONTAL_POS;
      break;
    case 's'://move right
      //moveHorizontal(-1);
      index = IVAD_SETTING_HORIZONTAL_POS;
      increment = false;
      break;
    case 'w'://move up
      //moveVertical(-1);
      index = IVAD_SETTING_VERTICAL_POS;
      increment = false;
      break;
    case 'z'://move down
      //moveVertical(+1);
      index = IVAD_SETTING_VERTICAL_POS;
      break;
    case 'd'://make skinnier
      //changeWidth(+1);
      index = IVAD_SETTING_WIDTH;
      break;
    case 'f'://make fatter
      //changeWidth(-1);
      index = IVAD_SETTING_WIDTH;
      increment = false;
      break;
    case 'r'://make taller
      //changeHeight(+1);
      index = IVAD_SETTING_HEIGHT;
      break;
    case 'c'://make shorter
      //changeHeight(-1);
      index = IVAD_SETTING_HEIGHT;
      increment = false;
      break;
    case 'g'://decrease contrast
      //changeContrast(-1);
      index = IVAD_SETTING_CONTRAST;
      increment = false;
      break;
    case 'h'://increase contrast
      //changeContrast(+1);
      index = IVAD_SETTING_CONTRAST;
      break;
    case 'j'://decrease brightness
      //changeBrightness(-1);
      index = IVAD_SETTING_BRIGHTNESS;
      increment = false;
      break;
    case 'k'://increase brightness
      // changeBrightness(+1);
      index = IVAD_SETTING_BRIGHTNESS;
      break;
    case 'x'://tilt paralellogram left
      //changeParallelogram(+1);
      index = IVAD_SETTING_PARALLELOGRAM;
      break;
    case 'v'://tilt paralellogram right
      //changeParallelogram(-1);
      index = IVAD_SETTING_PARALLELOGRAM;
      increment = false;
      break;
    case 'b'://keystone pinch top
      //changeKeystone(-1);
      index = IVAD_SETTING_KEYSTONE;
      increment = false;
      break;
    case 'n'://keystone pinch bottom
      //changeKeystone(+1);
      index = IVAD_SETTING_KEYSTONE;
      break;
    case 't'://rotate left
      //changeRotation(+1);
      index = IVAD_SETTING_ROTATION;
      break;
    case 'y'://rotate right
      //changeRotation(-1);
      index = IVAD_SETTING_ROTATION;
      increment = false;
      break;
    case 'u'://pincushion pull corners out
      //changePincushion(-1);
      index = IVAD_SETTING_PINCUSHION;
      increment = false;
      break;
    case 'i'://pincushion pull corners in
      //changePincushion(+1);
      index = IVAD_SETTING_PINCUSHION;
      break;
    case 'p':
      printCurrentSettings();
      break;
    case 'o'://power off
      if ( externalCircuitState == HIGH ) {
        externalCircuitOff();
      }//end if
      break;
  }
  //}

  if (index > -1) {
    int val = CURRENT_CONFIG[index];
    if (increment) {
      val++;
    }
    else
    {
      val--;
    }

    ivad_change_setting(index, val);
  }//end if


}//end handleSerial

void printCurrentSettings() {
  Serial.println(F("----------------------------"));

  Serial.print(F("heightValueIndex: "));
  Serial.println(heightValueIndex, HEX);

  Serial.print(F("widthValueIndex: "));
  Serial.println(widthValueIndex, HEX);

  Serial.println("");

  Serial.print(F("verticalPositionValueIndex: "));
  Serial.println(verticalPositionValueIndex, HEX);

  Serial.print(F("horizontalPositionValueIndex: "));
  Serial.println(horizontalPositionValueIndex, HEX);

  Serial.println(F(""));

  Serial.print(F("rotationValueIndex: "));
  Serial.println(rotationValueIndex, HEX);

  Serial.print(F("parallelogramValueIndex: "));
  Serial.println(parallelogramValueIndex, HEX);

  Serial.print(F("keystoneValueIndex: "));
  Serial.println(keystoneValueIndex, HEX);

  Serial.print(F("pincushionValueIndex: "));
  Serial.println(pincushionValueIndex, HEX);

  Serial.println("");

  Serial.print(F("contrastValueIndex: "));
  Serial.println(contrastValueIndex, HEX);

  Serial.print(F("brightnessValueIndex: "));
  Serial.println(brightnessValueIndex, HEX);

  Serial.println(F("----------------------------"));

}

void writeToIvad(byte address, byte message) {
  softWire.beginTransmission(address);
  softWire.write(message);
  softWire.endTransmission();

}//end method

void writeToIvad(byte address, byte message1, byte message2) {
  softWire.beginTransmission(address);
  softWire.write(message1);
  softWire.write(message2);
  softWire.endTransmission();

}//end method

void  readFromIvad(byte address, byte bytes) {
  char buf[bytes + 1];
  byte bytesRead = 0;
  softWire.requestFrom(address, bytes);
  while (softWire.available())
  {
    char c = softWire.read();
    buf[bytesRead++] = c;
  }
  buf[bytesRead] = '\0';

}//end method


void initIvadBoard() {

//  //init sequence 2 <---this is the one that works well with my iMac G3, Rocky Hill
//  writeToIvad( IVAD_REGISTER_PROPERTY, IVAD_SETTING_WIDTH, 0x00);
//  readFromIvad(IVAD_REGISTER_PROPERTY, 1);
//  writeToIvad( IVAD_REGISTER_PROPERTY, IVAD_SETTING_VERTICAL_POS, 0x00);
//  writeToIvad( 0x53, 0x33);
//  readFromIvad(0x53, 1);
//  writeToIvad( IVAD_REGISTER_PROPERTY, IVAD_SETTING_WIDTH, 0x0B);
//  writeToIvad( IVAD_REGISTER_PROPERTY, IVAD_SETTING_CONTRAST, 0x00); //setting contrast to 0x00 seems to turn something on.
//  writeToIvad( IVAD_REGISTER_PROPERTY, IVAD_SETTING_HEIGHT, 0xE4);
//  writeToIvad( IVAD_REGISTER_PROPERTY, IVAD_SETTING_ROTATION, 0xC9);
//  writeToIvad( 0x53, 0x00);
//  readFromIvad(0x53, 10);
//  writeToIvad( 0x53, 0x0A);
//  readFromIvad(0x53, 10);
//  writeToIvad( 0x53, 0x14);
//  readFromIvad(0x53, 10);
//  writeToIvad( 0x53, 0x1E);
//  readFromIvad(0x53, 10);
//  writeToIvad( 0x53, 0x28);
//  readFromIvad(0x53, 10);
//  writeToIvad( 0x53, 0x32);
//  readFromIvad(0x53, 10);
//  writeToIvad( 0x53, 0x3C);
//  readFromIvad(0x53, 10);
//  writeToIvad( 0x53, 0x46);
//  readFromIvad(0x53, 10);
//  writeToIvad( 0x53, 0x50);
//  readFromIvad(0x53, 10);
//  writeToIvad( 0x53, 0x5A);
//  readFromIvad(0x53, 2);
//  writeToIvad( IVAD_REGISTER_PROPERTY, IVAD_SETTING_RED_CUTOFF,         VIDEO_CONFIG_DEFAULT[ IVAD_SETTING_RED_CUTOFF ]        );
//  writeToIvad( IVAD_REGISTER_PROPERTY, IVAD_SETTING_GREEN_CUTOFF,       VIDEO_CONFIG_DEFAULT[ IVAD_SETTING_GREEN_CUTOFF ]      );
//  writeToIvad( IVAD_REGISTER_PROPERTY, IVAD_SETTING_BLUE_CUTOFF,        VIDEO_CONFIG_DEFAULT[ IVAD_SETTING_BLUE_CUTOFF ]       ); 
//  writeToIvad( IVAD_REGISTER_PROPERTY, IVAD_SETTING_HORIZONTAL_POS,     VIDEO_CONFIG_DEFAULT[ IVAD_SETTING_HORIZONTAL_POS ]    );
//  writeToIvad( IVAD_REGISTER_PROPERTY, IVAD_SETTING_HEIGHT,             VIDEO_CONFIG_DEFAULT[ IVAD_SETTING_HEIGHT ]            );
//  writeToIvad( IVAD_REGISTER_PROPERTY, IVAD_SETTING_VERTICAL_POS,       VIDEO_CONFIG_DEFAULT[ IVAD_SETTING_VERTICAL_POS ]      );
//  writeToIvad( IVAD_REGISTER_PROPERTY, IVAD_SETTING_S_CORRECTION,       VIDEO_CONFIG_DEFAULT[ IVAD_SETTING_S_CORRECTION ]      );
//  writeToIvad( IVAD_REGISTER_PROPERTY, IVAD_SETTING_KEYSTONE,           VIDEO_CONFIG_DEFAULT[ IVAD_SETTING_KEYSTONE ]          );
//  writeToIvad( IVAD_REGISTER_PROPERTY, IVAD_SETTING_PINCUSHION,         VIDEO_CONFIG_DEFAULT[ IVAD_SETTING_PINCUSHION ]        );
//  writeToIvad( IVAD_REGISTER_PROPERTY, IVAD_SETTING_WIDTH,              VIDEO_CONFIG_DEFAULT[ IVAD_SETTING_WIDTH ]             );
//  writeToIvad( IVAD_REGISTER_PROPERTY, IVAD_SETTING_PINCUSHION_BALANCE, VIDEO_CONFIG_DEFAULT[ IVAD_SETTING_PINCUSHION_BALANCE ]);
//  writeToIvad( IVAD_REGISTER_PROPERTY, IVAD_SETTING_PARALLELOGRAM,      VIDEO_CONFIG_DEFAULT[ IVAD_SETTING_PARALLELOGRAM ]     );
//  writeToIvad( IVAD_REGISTER_PROPERTY, IVAD_SETTING_RESERVED6,          VIDEO_CONFIG_DEFAULT[ IVAD_SETTING_RESERVED6 ]         ); // brightness
//  writeToIvad( IVAD_REGISTER_PROPERTY, IVAD_SETTING_BRIGHTNESS,         VIDEO_CONFIG_DEFAULT[ IVAD_SETTING_BRIGHTNESS ]        );
//  writeToIvad( IVAD_REGISTER_PROPERTY, IVAD_SETTING_ROTATION,           VIDEO_CONFIG_DEFAULT[ IVAD_SETTING_ROTATION ]          );
//  writeToIvad( IVAD_REGISTER_PROPERTY, IVAD_SETTING_CONTRAST,           VIDEO_CONFIG_DEFAULT[ IVAD_SETTING_CONTRAST ]          );



     //provided by anothere
      writeToIvad( 0x46,0x13,0x00);
      writeToIvad(0x46,0x13,0x00);
      readFromIvad(0x46,1);
      writeToIvad(0x46,0x09,0x00);
      writeToIvad(0x53,0x33);
      readFromIvad(0x53,1);
      writeToIvad(0x46,0x13,0x0b);
      writeToIvad(0x46,0x00,0x00);
      writeToIvad(0x46,0x08,0xe4);
      writeToIvad(0x46,0x12,0xc9);
      writeToIvad(0x53,0x00);
      readFromIvad(0x53,10);
      writeToIvad(0x53,0x0a);
      readFromIvad(0x53,10);
      writeToIvad(0x53,0x14);
      readFromIvad(0x53,10);
      writeToIvad(0x53,0x1e);
      readFromIvad(0x53,10);
      writeToIvad(0x53,0x28);
      readFromIvad(0x53,10);
      writeToIvad(0x53,0x32);
      readFromIvad(0x53,10);
      writeToIvad(0x53,0x3c);
      readFromIvad(0x53,10);
      writeToIvad(0x53,0x46);
      readFromIvad(0x53,10);
      writeToIvad(0x53,0x50);
      readFromIvad(0x53,10);
      writeToIvad(0x53,0x5a);
      readFromIvad(0x53,10);
      writeToIvad(0x46,0x01,0x82);
      writeToIvad(0x46,0x02,0x82);
      writeToIvad(0x46,0x03,0x82);
      writeToIvad(0x46,0x04,0xa0);
      writeToIvad(0x46,0x05,0xa0);
      writeToIvad(0x46,0x06,0xa0);
      writeToIvad(0x46,0x07,0xad);
      writeToIvad(0x46,0x08,0xe4);
      writeToIvad(0x46,0x09,0x3d);
      writeToIvad(0x46,0x0a,0x9e);
      writeToIvad(0x46,0x0b,0xb4);
      writeToIvad(0x46,0x0c,0xc4);
      writeToIvad(0x46,0x0d,0x27);
      writeToIvad(0x46,0x0e,0xbf);
      writeToIvad(0x46,0x0f,0xc0);
      writeToIvad(0x46,0x10,0x40);
      writeToIvad(0x46,0x11,0x0a);
      writeToIvad(0x46,0x12,0x5b);
      writeToIvad(0x46,0x00,0xff);
      writeToIvad(0x53,0x00);
      readFromIvad(0x53,10);
      writeToIvad(0x53,0x10);
      readFromIvad(0x53,10);
      writeToIvad(0x53,0x20);
      readFromIvad(0x53,10);
      writeToIvad(0x53,0x30);
      readFromIvad(0x53,10);
      writeToIvad(0x46,0x11,0x05);
      writeToIvad(0x46,0x00,0xff);
      writeToIvad(0x46,0x00,0x00);
      writeToIvad(0x46,0x07,0xb1);
      writeToIvad(0x46,0x0d,0x10);
      writeToIvad(0x46,0x0c,0xc7);
      writeToIvad(0x46,0x09,0x4a);
      writeToIvad(0x46,0x08,0xea);
      writeToIvad(0x46,0x0f,0xc0);
      writeToIvad(0x46,0x0b,0xae);
      writeToIvad(0x46,0x12,0x5b);
      writeToIvad(0x46,0x00,0xff);
      writeToIvad(0x46,0x11,0x05);
      writeToIvad(0x46,0x00,0xff);
      writeToIvad(0x46,0x10,0x40);
      writeToIvad(0x46,0x06,0xa0);
      writeToIvad(0x46,0x05,0xa0);
      writeToIvad(0x46,0x04,0xa0);
      writeToIvad(0x46,0x03,0x82);
      writeToIvad(0x46,0x02,0x82);
      writeToIvad(0x46,0x01,0x82);
      writeToIvad(0x46,0x11,0x05);
      writeToIvad(0x46,0x00,0xff);
      writeToIvad(0x46,0x11,0x05);
      writeToIvad(0x46,0x00,0xff);
      writeToIvad(0x46,0x10,0x40);
      writeToIvad(0x46,0x06,0xa0);
      writeToIvad(0x46,0x05,0xa0);
      writeToIvad(0x46,0x04,0xa0);
      writeToIvad(0x46,0x03,0x82);
      writeToIvad(0x46,0x02,0x82);
      writeToIvad(0x46,0x01,0x82);
      writeToIvad(0x46,0x11,0x05);
      writeToIvad(0x46,0x00,0xff);
}


void solid_state_relayOn() {
  digitalWrite(solid_state_relay_Pin, HIGH);

}

void solid_state_relayOff() {
  digitalWrite(solid_state_relay_Pin, LOW);

}




//these are probably too much but they are here in case I would lke to add more stuff to turn on and off
void externalCircuitOn() {
  solid_state_relayOn();
  delay(500);
  initIvadBoard();
  settings_load();
  ivad_write_settings();
  externalCircuitState = HIGH;


}

void externalCircuitOff() {
  solid_state_relayOff();
  externalCircuitState = LOW;

}



// function that executes whenever data is requested by master
// this function is registered as an event.
void requestEvent() {
  //delay(500);
  Wire.write(edid, 128);



}//end method
// function that executes whenever data is received by the slave


void receiveData(byte byteCount) {


  while (Wire.available()) {
    data = Wire.read();
  }
}


/*
  This is my implementation of oshimai's communications protocol.
  Clearly I borrowed heavily from his sketch and I purposely
  kept the same variable names to make it easier to port any
  changes he might make to his sletch. There are parts I didn't
  bother to port, verifying the checksum for example because of
  time constraints. I might implement the rest in the future.

*/
void serial_processing()
{

  byte b ;

  if (Serial.available()) {

    do
    {
      b = Serial.read();
      SERIAL_BUFFER[SERIAL_BUFFER_DATA_SIZE++] = b;
    }
    while (Serial.available() &&  b != SERIAL_EOL_MARKER);


    //call other serial handler
    if (SERIAL_BUFFER_DATA_SIZE != 9)
    {
      if (SERIAL_BUFFER[0] != 0x07) {
        SERIAL_BUFFER_DATA_SIZE = 0;
        handleSerial((char)b);
      }
      return;

    }


    SERIAL_BUFFER_DATA_SIZE = 0;

    byte id = SERIAL_BUFFER[1];
    byte cmd = SERIAL_BUFFER[2];
    byte valA = SERIAL_BUFFER[3];
    byte valB = SERIAL_BUFFER[4];

    switch (cmd)
    {

      case 0x01: // Get EEPROM Version
        {
          byte ret[8] { 0x06, id, 0x01, CONFIG_EEPROM_VERSION, 0x03, 0xFF, 0x04, SERIAL_EOL_MARKER };
          ret[5] = checksum(ret, 5);
          Serial.write(ret, 8);
        }
        break;

      case 0x02: // Dump SRAM Config
        {
          byte ret[7 + CONFIG_EEPROM_SLOTS];
          ret[0] = 0x06;
          ret[1] = SERIAL_BUFFER[1];
          ret[2] = CONFIG_EEPROM_SLOTS;

          for (int i = 0; i < CONFIG_EEPROM_SLOTS; i++)
            ret[3 + i] = CURRENT_CONFIG[i];

          ret[2 + CONFIG_EEPROM_SLOTS + 1] = 0x03;
          ret[2 + CONFIG_EEPROM_SLOTS + 2] = checksum(ret, 2 + CONFIG_EEPROM_SLOTS + 1 + 1);
          ret[2 + CONFIG_EEPROM_SLOTS + 3] = 0x04;
          ret[2 + CONFIG_EEPROM_SLOTS + 4] = SERIAL_EOL_MARKER;
          Serial.write(ret, 7 + CONFIG_EEPROM_SLOTS);
        }
        break;

      case 0x03: // IVAD Change Setting
        {
          ivad_change_setting(valA, valB);
          byte ret[7] { 0x06, id, 0x00, 0x03, 0xFF, 0x04, SERIAL_EOL_MARKER };
          ret[4] = checksum(ret, 4);
          Serial.write(ret, 7);
        }
        break;

      case 0x04: // IVAD Reset from EEPROM
        {
          settings_load();
          byte ret[7] { 0x06, id, 0x00, 0x03, 0xFF, 0x04, SERIAL_EOL_MARKER };
          ret[4] = checksum(ret, 4);
          Serial.write(ret, 7);
        }
        break;

      case 0x05: // EEPROM Reset to Default
        {
          settings_reset_default();
          settings_store();
          settings_load();
          ivad_write_settings();
          byte ret[7] { 0x06, id, 0x00, 0x03, 0xFF, 0x04, SERIAL_EOL_MARKER };
          ret[4] = checksum(ret, 4);
          Serial.write(ret, 7);
        }
        break;

      case 0x06: // Write SRAM to EEPROM
        {
          settings_store();
          byte ret[7] { 0x06, id, 0x00, 0x03, 0xFF, 0x04, SERIAL_EOL_MARKER };
          ret[4] = checksum(ret, 4);
          Serial.write(ret, 7);
        }
    }//end switch

    SERIAL_BUFFER[1] = 0xFF;

  }

}//end if









//===================================



byte checksum(const byte arr[], const int len)
{
  int sum = 1; // Checksum may never be 0.

  for (int i = 0; i < len; i++)
    sum += arr[i];

  byte ret = 256 - (sum % 256);

  return ret;
}




int ivad_change_setting(const int ivad_setting,  const byte value)
{

  CURRENT_CONFIG[ivad_setting] = value;

  if (CURRENT_CONFIG[ivad_setting] < VIDEO_CONFIG_MIN[ivad_setting]) CURRENT_CONFIG[ivad_setting] = VIDEO_CONFIG_MIN[ivad_setting];
  if (CURRENT_CONFIG[ivad_setting] > VIDEO_CONFIG_MAX[ivad_setting]) CURRENT_CONFIG[ivad_setting] = VIDEO_CONFIG_MAX[ivad_setting];

  writeToIvad(IVAD_REGISTER_PROPERTY, ivad_setting, CURRENT_CONFIG[ivad_setting]);
  CURRENT_CONFIG[CONFIG_OFFSET_CHECKSUM] = checksum(CURRENT_CONFIG, CONFIG_EEPROM_SLOTS - 1);

  return 0;
}
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

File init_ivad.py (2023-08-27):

#!/usr/bin/python

import RPi.GPIO as GPIO
from smbus import SMBus
bus = SMBus(1)




def writeToIvad(address, message1, message2):
    msg1=[message1]
    msg2=[message2]
    msg=[message1,message2]
#    bus.write_i2c_block_data(address,0,msg1)
#    bus.write_i2c_block_data(address,0,msg2)
#    bus.write_byte(address,message1)
#    bus.write_byte(address,message2)
#    bus.write_i2c_block_data(address,0,msg)
    bus.write_byte_data(address,message1,message2)
    return;
    

def readFromIvad(address, bytes):
    #bus.read_i2c_block_data(address,0,bytes)
    for x in range(bytes):
        bus.read_byte(address)
    return;    


writeToIvad(0x46,0x13,0x00)
readFromIvad(0x46,1)
writeToIvad(0x46,0x09,0x00)
bus.write_byte(0x53,0x33)
readFromIvad(0x53,1)
writeToIvad(0x46,0x13,0x0A)
writeToIvad(0x46,0x00,0x00)
writeToIvad(0x46,0x08,0xE4)
writeToIvad(0x46,0x12,0xC9)
bus.write_byte(0x53,0x00)
readFromIvad(0x53,10)
bus.write_byte(0x53,0x0A)
readFromIvad(0x53,10)
bus.write_byte(0x53,0x14)
readFromIvad(0x53,10)
bus.write_byte(0x53,0x1E)
readFromIvad(0x53,10)
bus.write_byte(0x53,0x28)
readFromIvad(0x53,10)
bus.write_byte(0x53,0x32)
readFromIvad(0x53,10)
bus.write_byte(0x53,0x3C)
readFromIvad(0x53,10)
bus.write_byte(0x53,0x46)
readFromIvad(0x53,10)
bus.write_byte(0x53,0x50)
readFromIvad(0x53,10)
bus.write_byte(0x53,0x5A)
readFromIvad(0x53,10)
writeToIvad(0x46,0x01,0x93)
writeToIvad(0x46,0x02,0x93)
writeToIvad(0x46,0x03,0x8F)
writeToIvad(0x46,0x04,0x9A)
writeToIvad(0x46,0x05,0x7B)
writeToIvad(0x46,0x06,0x7B)
writeToIvad(0x46,0x07,0xB0)
writeToIvad(0x46,0x08,0xDC)
writeToIvad(0x46,0x09,0x49)
writeToIvad(0x46,0x0A,0x92)
writeToIvad(0x46,0x0B,0xA2)
writeToIvad(0x46,0x0C,0xDF)
writeToIvad(0x46,0x0D,0x20)
writeToIvad(0x46,0x0E,0xC2)
writeToIvad(0x46,0x0F,0xD2)
writeToIvad(0x46,0x10,0x40)
writeToIvad(0x46,0x11,0x09)
writeToIvad(0x46,0x12,0x27)
writeToIvad(0x46,0x00,0xFA)
bus.write_byte(0x53,0x00)
readFromIvad(0x53,10)
bus.write_byte(0x53,0x0A)
readFromIvad(0x53,10)
bus.write_byte(0x53,0x14)
readFromIvad(0x53,10)
bus.write_byte(0x53,0x1E)
readFromIvad(0x53,10)
bus.write_byte(0x53,0x28)
readFromIvad(0x53,10)
bus.write_byte(0x53,0x32)
readFromIvad(0x53,10)
bus.write_byte(0x53,0x3C)
readFromIvad(0x53,10)
bus.write_byte(0x53,0x46)
readFromIvad(0x53,10)
bus.write_byte(0x53,0x50)
readFromIvad(0x53,10)
bus.write_byte(0x53,0x5A)
readFromIvad(0x53,2)
writeToIvad(0x46,0x01,0x93)
writeToIvad(0x46,0x02,0x93)
writeToIvad(0x46,0x03,0x8F)
writeToIvad(0x46,0x04,0x9A)
writeToIvad(0x46,0x05,0x7B)
writeToIvad(0x46,0x06,0x7B)
writeToIvad(0x46,0x07,0xB0)
writeToIvad(0x46,0x08,0xDC)
writeToIvad(0x46,0x09,0x49)
writeToIvad(0x46,0x0A,0x92)
writeToIvad(0x46,0x0B,0xA2)
writeToIvad(0x46,0x0C,0xDF)
writeToIvad(0x46,0x0D,0x20)
writeToIvad(0x46,0x0E,0xC2)
writeToIvad(0x46,0x0F,0xD2)
writeToIvad(0x46,0x10,0x40)
writeToIvad(0x46,0x11,0x09)
writeToIvad(0x46,0x12,0x27)
writeToIvad(0x46,0x00,0xFA)

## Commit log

2020-02-01 Update README.md
    added connectors and pinout images
2020-02-01 added i2c initialization script to run on the raspberry pi
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2020-02-01 added diagrams to connects arduinos to transmit EDID info
2020-02-02 added tab to connector drawing to use as a reference
2020-02-03 modified the arduino sketch to use transistors instead of relays to power the iMac on and off
2020-02-04 started putting together a schematic to connect to the chassis connectors
    [imac_g3_333mhz_slot_loading_J20_adapter_board.kicad_pcb, imac_g3_333mhz_slot_loading_J20_adapter_board.sch]
2020-02-07 added pav board pinout and updated J22 pins
2020-02-07 fixed mispelled chasis to chassis...
2020-02-14 updated schematic with new J20 info
    [imac_g3_333mhz_slot_loading_J20_adapter_board.sch]
2020-02-18 updated diagrams with headphone jack pinout and correcected ground swap
2020-02-24 I confirmed that the second capture of the initialization sequence works with both of my iMacs so there is no need to keep two copies. I replaced the first one with the second one.
    [i2c_capture.ods]
2020-02-24 made a test pcb
    [imac_g3_333mhz_slot_loading_J20_adapter_board.sch]
2020-03-02 made board a little curvier
    [imac_g3_333mhz_slot_loading_J20_adapter_board.kicad_pcb, imac_g3_333mhz_slot_loading_J20_adapter_board.sch]
2020-03-03 made more changes to the board
    [imac_g3_333mhz_slot_loading_J20_adapter_board.dsn, imac_g3_333mhz_slot_loading_J20_adapter_board.kicad_pcb, imac_g3_333mhz_slot_loading_J20_adapter_board.sch]
2020-03-04 added caps to the board
    [imac_g3_333mhz_slot_loading_J20_adapter_board.dsn, imac_g3_333mhz_slot_loading_J20_adapter_board.kicad_pcb, imac_g3_333mhz_slot_loading_J20_adapter_board.sch]
2020-03-06 added rev-1 finshes. this is the board I ordered
    [Screw Terminal Block 5mm 6-way.step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]
2020-03-14 added J22 board design
    [CUI_DEVICES_SJ1-3533NG.step, EM292902-UL.STEP, Screw Terminal Block 5mm 2-way.step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]
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2020-03-14 added BOM
    [imac_g3_slot_loading_J22_adapter_board.csv]
2020-03-22 updated pin assigments on down-converter board to reflect those assigned by the manufacturer
2020-03-22 fixed pin assignment error in drawing
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2020-03-23 added schematics and pcb for down converter board
    [430452400.stp, CUI_DEVICES_SJ1-3533NG.step, EM292902-UL.STEP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]
2020-03-26 fixed miswired microphone jack
    [imac_g3_slot_loading_J22_adapter_board-B_Cu.gbr, imac_g3_slot_loading_J22_adapter_board-B_Mask.gbr, imac_g3_slot_loading_J22_adapter_board-B_Paste.gbr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]
2020-03-27 updated sketch to iclude two init sequences and code to detect button presses
2020-03-27 added edid.bin, a binary that has the edid for the iMac G3 slot loader
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2020-03-29 removed an atmega328 and moved VGA connector
    [bill_of_materials.csv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]
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2020-03-29 updated sketch for use with the J20 board rev 2
2020-03-29 added resistor values to silkscreen
    [imac_g3_333mhz_slot_loading_J20_adapter_board-B_Cu.gbr, imac_g3_333mhz_slot_loading_J20_adapter_board-B_Mask.gbr, imac_g3_333mhz_slot_loading_J20_adapter_board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]
2020-03-30 added electrek mic circuit stuff
    [imac_g3_slot_loading_J22_adapter_board-B_Cu.gbr, imac_g3_slot_loading_J22_adapter_board-B_Mask.gbr, imac_g3_slot_loading_J22_adapter_board-B_Paste.gbr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]
2020-03-31 created BOMs and updated crystal caps
    [bill_of_materials.csv, imac_g3_333mhz_slot_loading_J20_adapter_board.sch, imac_g3_down_converter_board_adapter.csv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]
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2020-04-07 updated silkscreen to make it more readable
    [imac_g3_333mhz_slot_loading_J20_adapter_board-B_Cu.gbr, imac_g3_333mhz_slot_loading_J20_adapter_board-B_Mask.gbr, imac_g3_333mhz_slot_loading_J20_adapter_board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]
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2020-04-10 uploaded correct schematic
2020-04-12 finer adjustment values
    p command to print current value indexes
2020-04-14 added rockyhill raw capture and sparpet raw capture
    [i2c_capture_rocky_hill.ods]
2020-04-17 updated schematic with a VSYNC detect input line.
    [imac_g3_333mhz_slot_loading_J20_adapter_board-B_Cu.gbr, imac_g3_333mhz_slot_loading_J20_adapter_board-B_Mask.gbr, imac_g3_333mhz_slot_loading_J20_adapter_board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]
2020-04-18 added a new initialization sequence and a capture when the computer balnks the screen and wakes
    [imac_g3_ivad_blanking_capture.csv, imac_g3_ivad_waking_capture.csv, imac_ivad_init_2_rocky_hill.csv]
2020-05-14 added apple display adjustment capture files and updated ivad.h
    [blue_cutoff.csv, blue_drive.csv, brightness.csv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]
2020-05-16 finally fixed the code to be compatible with both my gui and oshimais
    [imacG3IvadInit.ino]
2020-05-21 added three more captures, shutdown sleep and wakeup
    [shutdown.csv, sleep.csv, wakeup.csv]
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2020-07-10 added more text to the analog board pic
2020-07-10 added text to the logic board and down converter board imae
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2020-08-09 added interactive bom's to help in the assembly process
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2021-03-18 Updated the 26 pos header on the J22 board from a non stock item to a normally stocked item.
    [bill_of_materials.csv, imac_g3_slot_loading_J22_adapter_board.sch]
2022-03-20 Update imacG3IvadInit.ino
    Corrected comments as suggested by Rudy Boonstra.
    [imacG3IvadInit.ino]
2022-04-26 started putting together a surface mount version.
    [Screw Terminal Block 5mm 6-way.step, bill_of_materials.csv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]
2022-04-26 added stl files for a raspberry pi 4 mount
    [rpi_g3_bezel_v3.stl, rpi_g3_plate_v2.stl, rpi_g3_spacer_v1.stl]
2022-04-26 Added user contributed boards by Rudy. -A raspberry pi HAT -A breakout board for the headers on the J20 board.
    [RPiG3iMac-B_Cu.gbr, RPiG3iMac-B_Fab.gbr, RPiG3iMac-B_Mask.gbr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]
2022-04-27 removed .DS files and zipped gerber files. Made some changes to some of he readme's
2023-08-27 fixed python spacing issue
    [init_ivad.py]
2023-10-05 converted J20 board to SMD and sourced components for it.
    [USB4105-GF-A.step, imac_g3_333mhz_slot_loading_J20_adapter_board.kicad_sch, imac_g3_333mhz_slot_loading_J20_adapter_board.sch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]
